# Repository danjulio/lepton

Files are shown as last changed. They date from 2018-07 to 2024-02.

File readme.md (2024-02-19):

## FLIR Lepton Code

This repository contains code, libraries and hardware I developed over the course of making a series of thermal imaging cameras based on the FLIR Lepton 3.5 camera or [module](https://store.groupgets.com/collections/flir-lepton-accessories/products/flir-lepton-breakout-board) on many different platforms.

The project process is documented at [hackaday.io](https://hackaday.io/project/159615-lepton-35-thermal-imaging-camera).

### ESP32
Contains code, design information and supporting applications for a pair of cameras based around the ESP32.

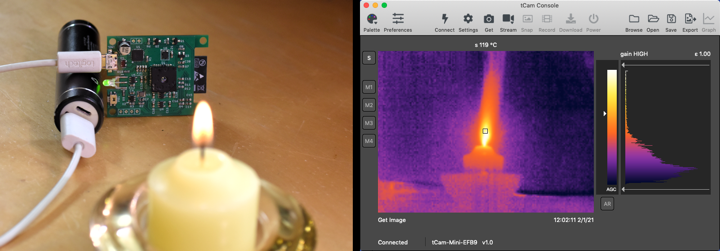
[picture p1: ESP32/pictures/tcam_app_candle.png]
tCam-Mini
 

# Note

As of Nov 6 2022, the ESP32 designs have been moved to their own repository [tCam](https://www.github.com/danjulio/tCam) to make it easier for most people who are only interested in those files.  Files here will no longer be updated.

### beaglebone
Code for the Beaglebone Black including my initial PRU-based VoSPI video pipleline and LCD display.

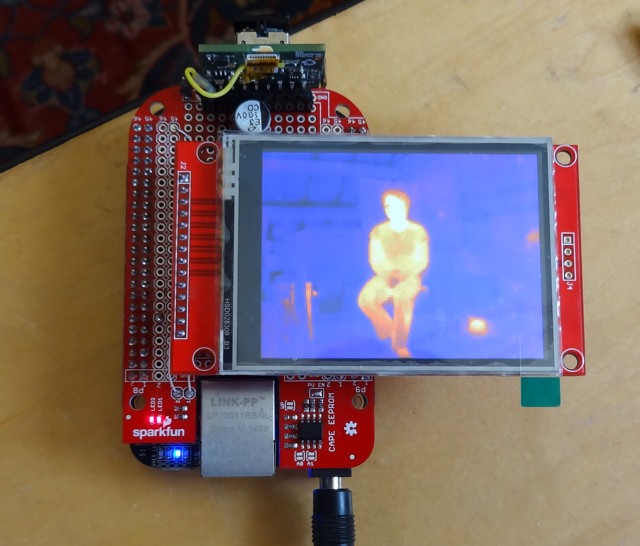
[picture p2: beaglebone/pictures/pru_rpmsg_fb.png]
Beaglebone Black Prototype


### pocketbeagle
The pocketbeagle was used for the final design of a thermal imaging camera.  This directory contains the code supporting the camera and the re-targeting of my Solar Pi Platter as a power-management and expansion board for the Pocketbeagle.

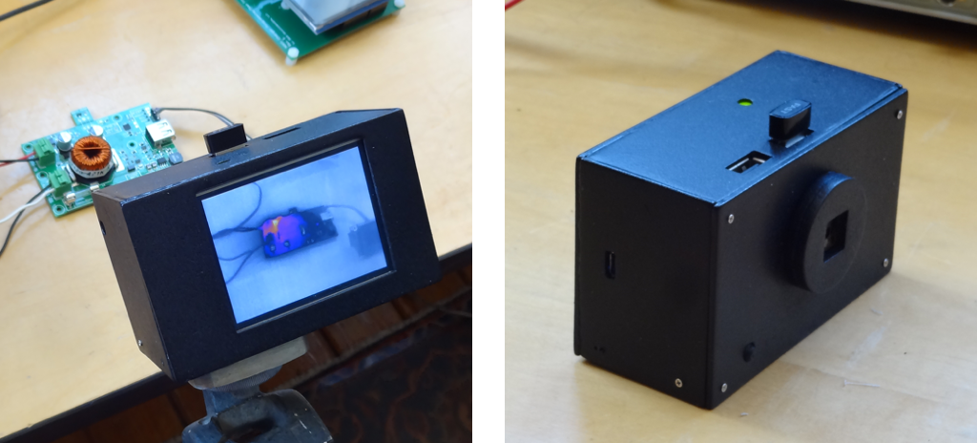
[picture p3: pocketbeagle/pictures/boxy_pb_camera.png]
Pocketbeagle Thermal Imaging Camera


### raspberrypi
Contains a modified version of Damien Walsh's great [leptonic](https://github.com/themainframe/leptonic) program running on the Raspberry Pi.  My version uses the VSYNC output from the Lepton to synchronize the VoSPI transfer as an experiment to increase the reliability of syncing a user-space process to the Lepton video stream.

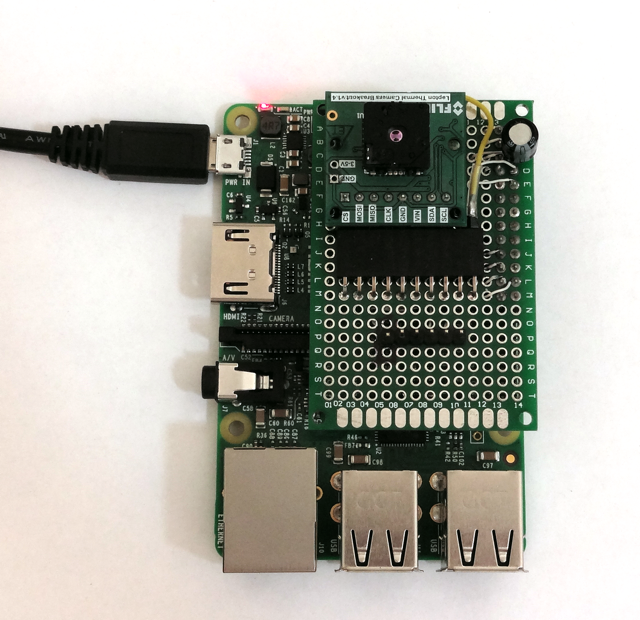
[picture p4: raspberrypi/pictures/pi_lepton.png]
Raspberry Pi Prototype


### teensy3
Contains the code I wrote initially for a test platform based on the PJRC Teensy 3.2 board to learn about the Lepton.  Also includes a port of FLIR's LeptonSDKEmb32OEM CCI to the Arduino platform.

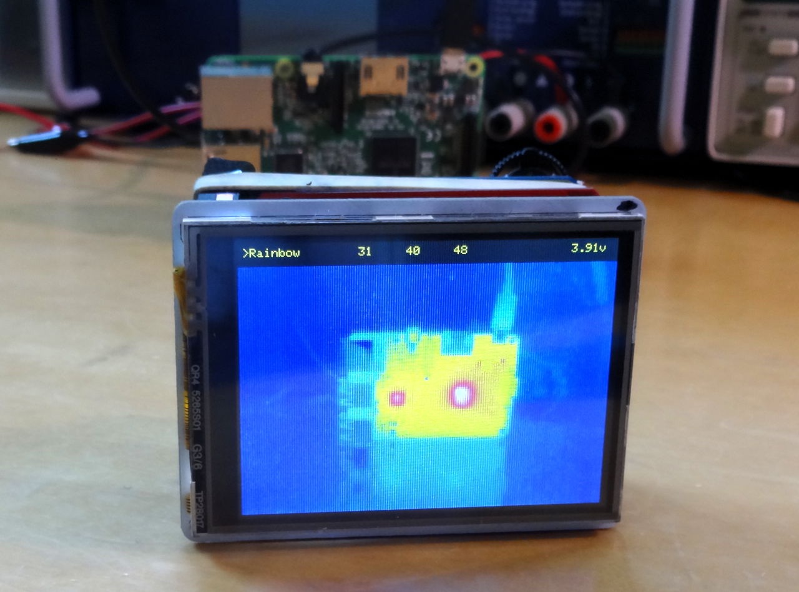
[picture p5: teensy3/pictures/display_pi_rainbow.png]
Teensy 3 Cam


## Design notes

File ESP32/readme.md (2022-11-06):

## ESP32-based Thermal Imaging Cameras
tCam and tCam-Mini are two cameras I designed around the ESP32 and Lepton 3.5.  They are designed to provide easy access to radiometric data from the Lepton.  Radiometric data is useful because it contains temperature information for each pixel in the camera's image allowing for all kinds of data analysis even if the image is stored to a file.

# Note

As of Nov 6 2022, the ESP32 designs have been moved to their own respository [tCam](https://www.github.com/danjulio/tCam) to make it easier for most people who are only interested in those files.  Files here will no longer be updated.

### tCam
tCam (still under development) is a full featured, battery powered camera with a local touchscreen display, local storage and a WiFi interface.

### tCam-Mini
tCam-Mini is a smaller network-only camera designed for streaming and remote access.  It can be built using development boards or a tested unit can be purchased from Group Gets [with built in antenna](https://store.groupgets.com/products/tcam-mini-rev4-wireless-streaming-thermal-camera-board) or [with an external antenna](https://store.groupgets.com/products/tcam-mini-rev4-external-antenna-wireless-streaming-thermal-camera-board).

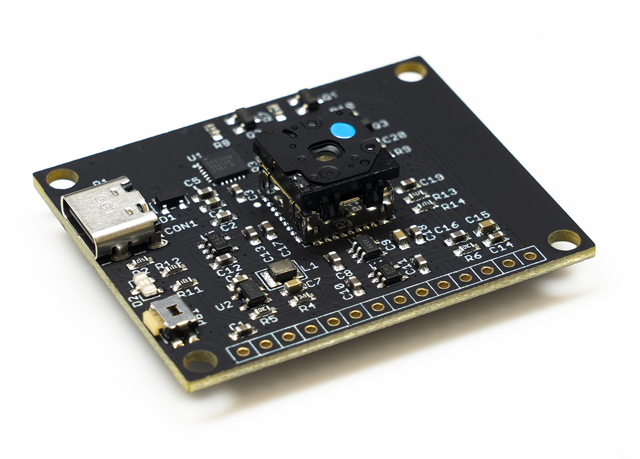
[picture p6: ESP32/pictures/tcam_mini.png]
tCam-Mini

(Photo Credit: Matthew Navarro)

### Desktop Application
Both cameras share a common command set for remote access.  A companion Desktop computer application may be used to configure and access the cameras as well as perform some analysis.

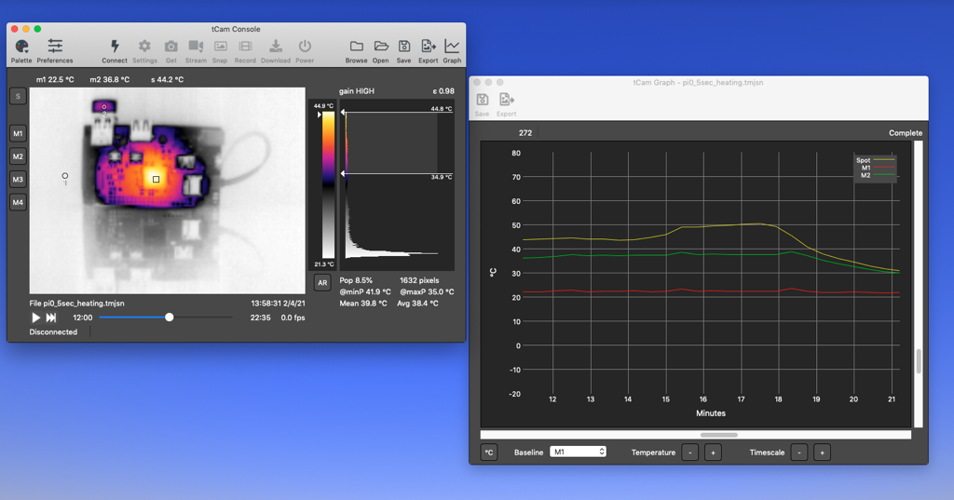
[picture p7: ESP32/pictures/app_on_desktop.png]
Desktop Application


### IOS Application
Connect, view and save images on an iPhone or iPad using the [IOS App](https://apps.apple.com/us/app/tcamview/id1610451813).  Documentation may be found on my [website](https://danjuliodesigns.com/products/tcam_app.html).

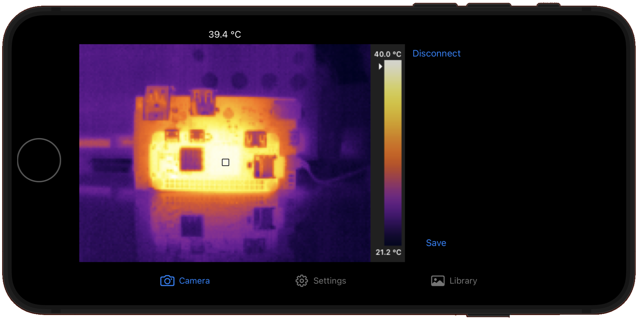
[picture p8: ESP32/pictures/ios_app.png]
IOS App


### Web Server
A simple stand-alone server that can connect to multiple cameras, record images that meet certain criteria and display images from the cameras in a web browser.

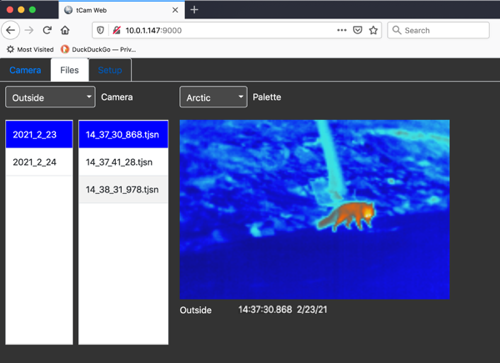
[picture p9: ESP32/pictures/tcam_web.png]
Web Application


### Python Driver
A simple driver to allow access from python programs.

### R Driver
Bob Rudus wrote a R driver for tCam-Mini that can be found in his [github repository](https://github.com/hrbrmstr/tcam).

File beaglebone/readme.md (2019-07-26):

# Beaglebone Black Code

This directory contains code and libraries developed for the Beaglebone Black board.

## pru\_rpmsg\_fb
Beaglebone Black Thermal Imaging Camera

The first code I got running on the Beaglebone Black using the two PRU co-processors to handle the Lepton's VoSPI stream and display the image on a linuxfb device driving a ubiquitous ILI9341-based 320x240 pixel LCD display.

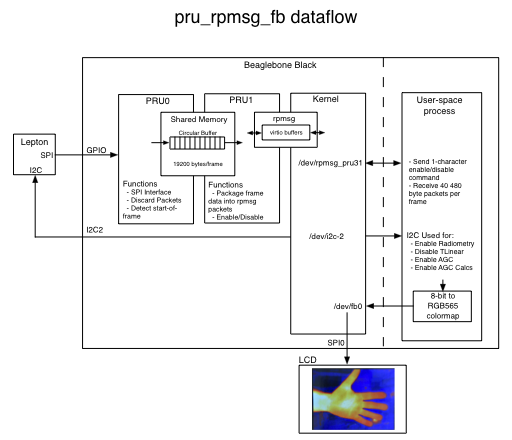
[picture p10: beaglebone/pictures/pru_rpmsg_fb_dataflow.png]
PRU Pipeline to LCD Display


## littlevgl\_devicetree
The device tree files and connection diagram to run the littlevgl GUI on the LCD display attached to a Beaglebone Black.

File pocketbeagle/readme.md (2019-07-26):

# Pocketbeagle Code and Hardware
The tiny Pocketbeagle forms the core of a complete thermal imaging camera using the Lepton 3.5 and a modified Solar Pi Platter board powered by a 3.7V 3000 mAh LiPo battery.  This directory contains the design of the camera and various pieces of software written to run on it.

Thermal Imaging Camera

## Software
### littlevgl\_demo
The necessary device tree file and a port of the littlevgl library and demo program to enable a touch-based GUI application on the build-in LCD.

### pru\_rpmsg\_fb
A port of the code originally written for the Beaglebone Black to the Pocketbeagle to display a simple image on the attached LCD screen.  The primary differences are the device tree files for the PRU/Lepton interface and SPI/LCD interface and the ```uEnv.txt``` file that uses them.  The PRU firmware implementing the VoSPI pipeline is also modified for the different pins used on the Pocketbeagle, but otherwise the same as the Beaglebone Black version.

## Camera Hardware
The hardware consists of several subsystems wired together.

### Schematic
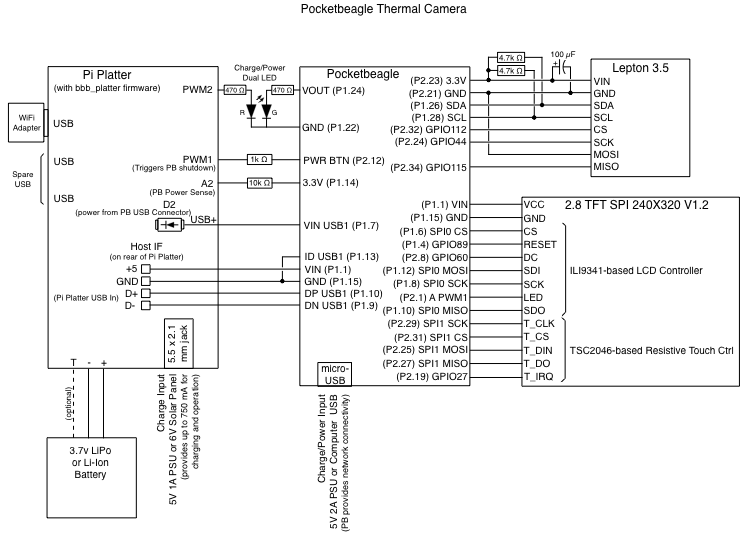
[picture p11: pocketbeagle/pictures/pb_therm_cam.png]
Pocketbeagle Thermal Imaging Camera Schematic


A dual red/green common-cathod LED provides indication of charging state and power.  The red LED lights when the battery is charging and the Green LED lights when the system is powered.

An optional USB WiFi dongle provides network access.

### Pocketbeagle board
Pocketbeagle on a proto-board with external discrete components and connections to other modules.

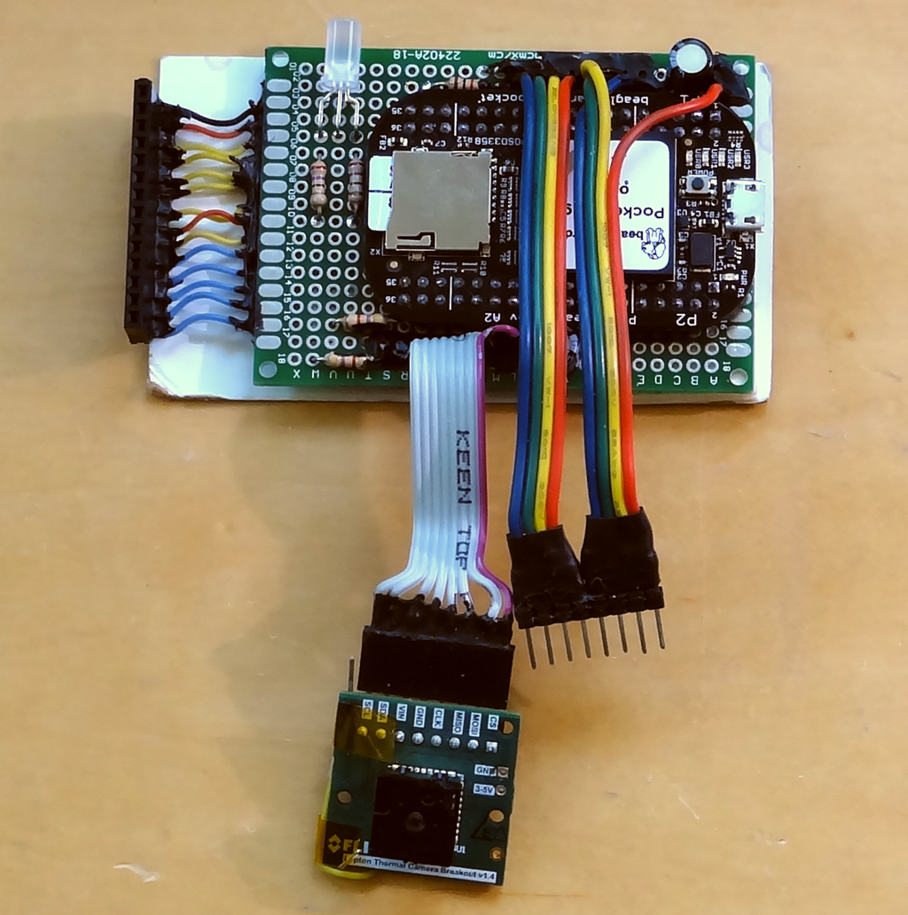
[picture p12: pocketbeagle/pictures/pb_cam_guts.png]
Pocketbeagle Board


The wire connection to the LCD connector shown above proved to be unreliable because flexing the cable during repeated camera assembly and disassembly eventually broke the solder connections.  Ultimately I replaced it with a connector on another proto-board securely mounted in the same plane as the Pocketbeagle proto-board.

### 2.8" LCD with resistive touch
I used a commonly available and inexpensive LCD module and removed the unused SD-card circuitry to prevent it from pressing against the Pocketbeagle wiring in the case.  I bought my module from Amazon but they are readily available from other sources as well.

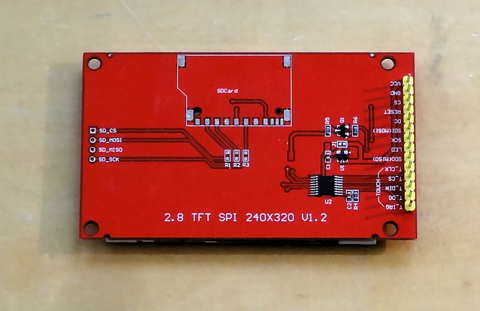
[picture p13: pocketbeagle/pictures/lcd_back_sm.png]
LCD Module Rear


### Modified Solar Pi Platter and Battery
My own Solar Pi Platter design was repurposed to provide power management and IO expansion for the camera.  It is documented in the ```bbb_platter``` directory.

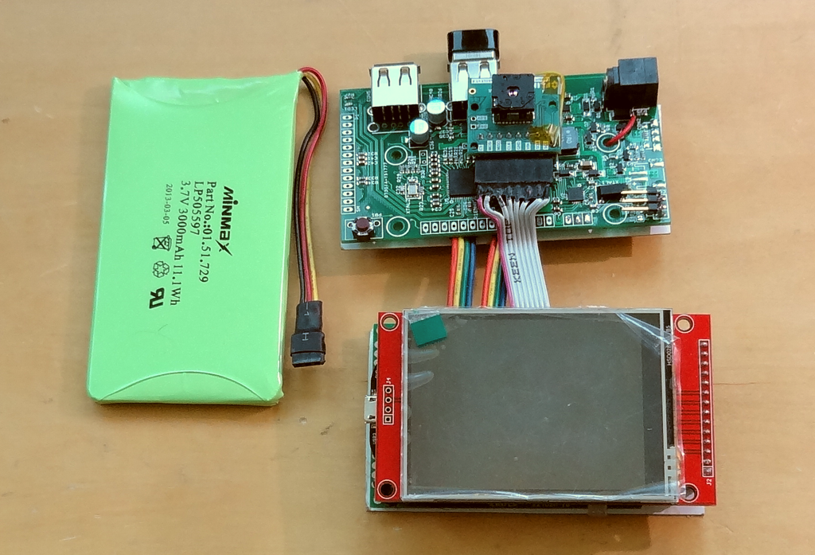
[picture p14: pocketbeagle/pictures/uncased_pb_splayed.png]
Pi Platter and Battery


The battery shown above includes a 10k thermistor connected to the Pi Platter for battery temperature monitoring.  This is optional.  Batteries from traditional suppliers like Adafruit and Sparkfun that do not include a thermistor may also be used.  I get several hours of operation from the 3000 mAh battery.

### Cardboard
I used two pieces of thin cardboard behind the two PCBs to smoothly sandwich the battery. 

### enclosure
Eight 3D printed parts are used to create an enclosure.  The parts were designed using OpenSCAD.  The source files and STL files are included in this directory.  You will need to slice the STL files into gcode for your 3D printer.

1. base.scad - Camera base including a cut-out for a tripod-mounting nut.  Includes guides to hold the various internal components of the camera and blocks that can be used to screw the front, side and rear plates to the base.
2. button.scad - A simple button that rides on top of the physical switch on the Pi Platter board and pokes out the rear of the camera to allow the user to power on/off.
3. front2.scad - The LCD bezel.
4. rear_lens.scad - A protective shield for the Lepton module that mounts to the rear plate of the camera.
5. rear_smooth.scad - The rear plate including a cut-out for the Lepton and hole for the power button.
6. side1.scad - A side plate with hole for the Pi Platter 5.5x2.1mm power jack.
7. side2.scad - A side plat with cutout for the Pocketbeagle Micro-USB port.
8. top.scad - Camera top with hole for the charge/power LED and cut-outs for two USB Type-A expansion ports.  Includes guides to hold the various internal components of the camera and blocks that can be used to screw the front, side and rear plates to the base.

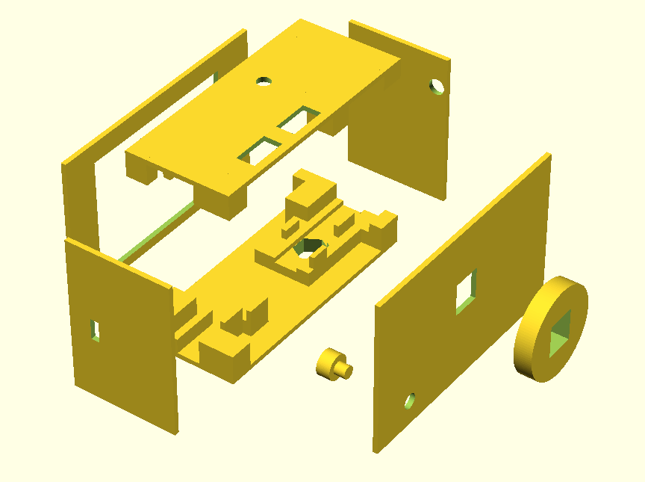
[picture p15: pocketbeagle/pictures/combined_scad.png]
Exploded view of 3D printed parts


I glued the front, sides and top together before sanding and painting the camera.  I also glued the rear_lens to the rear plate.  Then these two assemblies and the bottom are held together with screws to allow access to the camera internals.  I drilled small holes through the combined assemblies and then used small screws slightly larger than the holes to hold the parts together.  The camera was painted using a textured black spray paint over a gray primer and then clear coated.  Several layers of each paint were used.

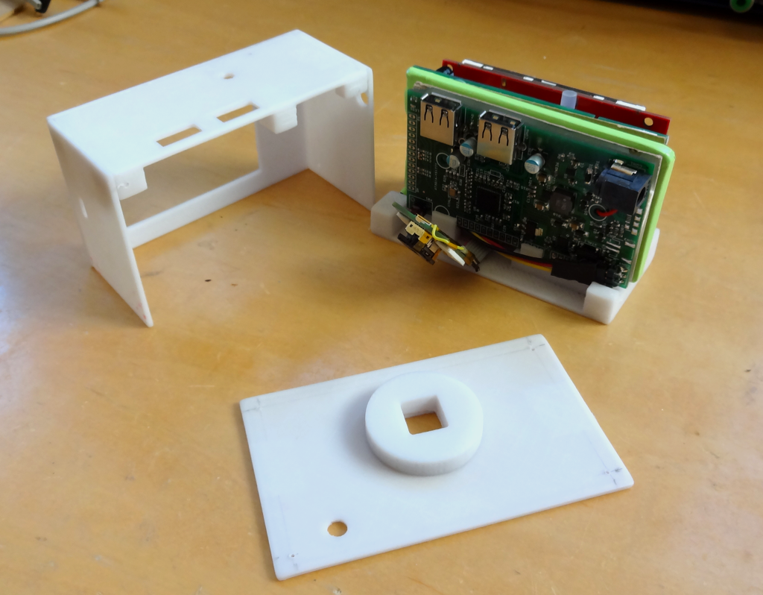
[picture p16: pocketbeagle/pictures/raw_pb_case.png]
Partially assembled camera


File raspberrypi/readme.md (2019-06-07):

# Raspberry Pi Code

## leptonic-vsync
A version of Damien Walsh's [leptonic](https://github.com/themainframe/leptonic) server program for the Raspberry Pi that uses VSYNC and an ISR running in user-space on the Pi to sync the Lepton's VoSPI data.

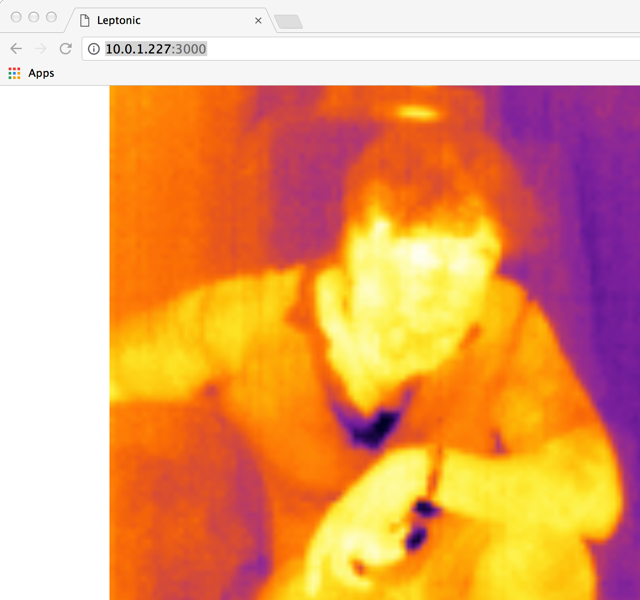
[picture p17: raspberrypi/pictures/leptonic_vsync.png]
leptonic_vsync


### Hardware

Pi Thermal Imaging Camera

Connect the Lepton module's power, I2C, SPI and VSYNC output to the Pi as follows.  

| Pi Header Pin | Function | Lepton Module |
|:---:|:---:|:---:|
| 1 | 3V3 | VIN |
| 3 | SDA | SDA |
| 5 | SCL | SCL |
| 6 | GND | GND |
| 7 | VSYNC | GPIO3 |
| 19 | MOSI | MOSI |
| 21 | MISO | MISO |
| 23 | SCLK | SCLK |
| 24 | CS0 | CS |

VSYNC can be found on the back of the Lepton module.

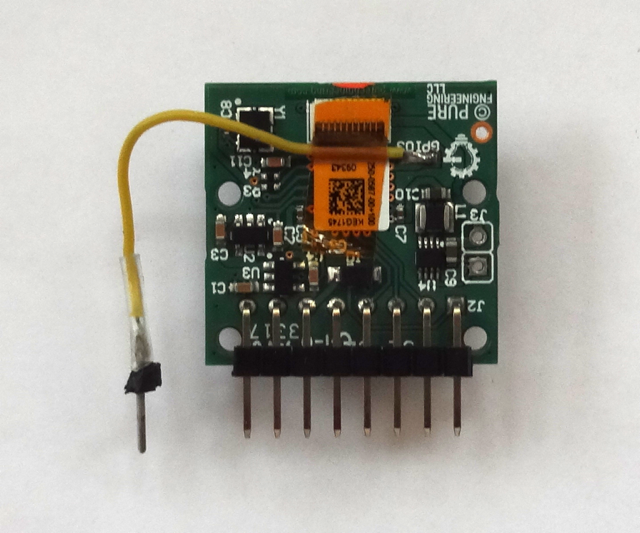
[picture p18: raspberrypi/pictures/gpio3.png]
VSYNC


### Software
Download and install Damien's version of [leptonic](https://github.com/themainframe/leptonic) including the dependencies he lists.  In addition, install the [PIGPIO C library](http://abyz.me.uk/rpi/pigpio/) and enable I2C on your Pi if necessary using ```raspi-config```.  PIGPIO is used for low-latency user-space interrupt handling.  Download and unpack leptonic-vsync.

```
cd leptonic-vsync
make
sudo ./bin/leptonic /dev/i2c-1 /dev/spidev0.0

```

You should see the leptonic server start up with output like the following.

```
pi@raspberrypi:~/leptonic-vsync $ sudo ./bin/leptonic /dev/i2c-1 /dev/spidev0.0
08:10:14 INFO  src/leptonic.c:223: preallocating space for segments...
08:10:14 INFO  src/leptonic.c:232: Creating get_frames_from_device thread
08:10:14 INFO  src/leptonic.c:238: Creating send_frames_to_socket thread
08:10:14 INFO  src/leptonic.c:80: opening I2C device... /dev/i2c-1
08:10:14 INFO  src/leptonic.c:87: opening SPI device... /dev/spidev0.0
08:10:14 INFO  src/leptonic.c:106: aquiring VoSPI synchronisation
```

Then start the frontend code in the original leptonic frontend directory.

```
npm start
```

You should be able to view the output from the camera on a web browser using the Pi's address at port 3000 as with Damien's original code.

#### AGC
Uncomment out the call to ````cci_set_agc_enable_state```` in leptonic.c to enable AGC.  This results in a slightly better image utilizing the Lepton's built-in AGC functionality.

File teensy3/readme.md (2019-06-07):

## Teensy 3 Test Platform

Teensy Thermal Imaging Camera

This directory contains code for a test platform based on the PJRC Teensy 3.2 development board.  It consists of a set of Arduino-environment sketches and a port of the FLIR IDD library used to control the module via its I2C bus.

The project is documented at [hackaday.io](https://hackaday.io/project/159615-lepton-35-thermal-imaging-camera).  It uses an ILI9341-based 320x240 pixel LCD display.

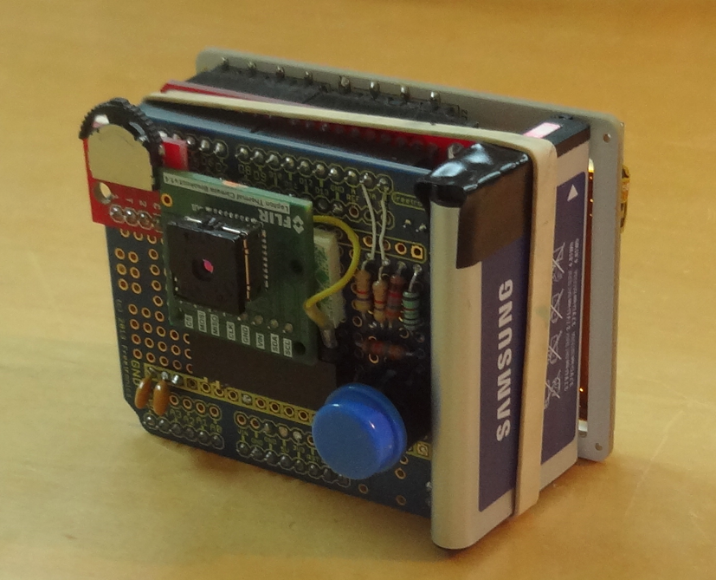
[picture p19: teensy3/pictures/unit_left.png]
Teensy Thermal Imaging Camera


### Contents

1. LeptonSDKEmb32OEM - FLIR's IDD library ported for operation on the Teensy.  Primarily this required adapting the different sizes of enums on the Teensy platform vs. 32-bit Linux platforms such as the Raspberry Pi.  This library has a dependence on the Teensy i2c_t3 library in case you want to try it on another embedded platform.  It should be put in your Arduino libraries folder.
2. lep_test5 - A test sketch demonstrating the Lepton's built-in AGC function.  Eight-bit output from the Lepton is displayed through a color map.
3. lep_test6 - A test sketch demonstrating the (default) 16-bit Tlinear radiometric data from the Lepton.  Sixteen-bit output from the Lepton is scaled linearly into an 8-bit range and displayed through a color map.  The temperature of the image center is displayed.
4. lep_test7 - A test sketch demonstrating the Lepton's internal color map LUTs.  AGC is enabled as well as 24-bit RGB output.  This data is then reduced to 16-bits for the LCD display without using any color maps on the Teensy.
5. lep_test8 - A test sketch designed to allow comparison of the Lepton's built-in AGC modes (HEQ and linear) with a simple linear transformation done in code with the 16-bit temperature data.
6. lep_test9 - A test sketch designed to allow investigating the emissivity setting (RAD Flux Linear Parameter) and comparing the spot meter output (via I2C) with the raw pixel data temperature.
7. lep_test10 - A combination of test5 and test9 enabling AGC (with HEQ mode), spot meter readout of center temperature and ability to set emmissivity.  Code has been ported to Adafruit's LCD shield (CS# on D10, DC on D9) and uses latest Adafruit GFX and ILI9341 Arduino libraries.
8. teensy_schematic.pdf - Shows the connections for the test platform including the soft power control and battery charging/boost converter circuitry.

This code is "as-is" and may contain bugs (especially the library as it has a lot of functions I haven't tested).  Please let me know if you have a question or find a bug.

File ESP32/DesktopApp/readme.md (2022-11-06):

# Note

As of Nov 6 2022, the ESP32 designs have been moved to their own respository [tCam](https://www.github.com/danjulio/tCam) to make it easier for most people who are only interested in those files.  Files here will no longer be updated.

## tCam Desktop Application

This repository contains the companion desktop application for the tCam cameras.  It communicates with the cameras via a network connection using their json packet command set.  It provides functionality to control the cameras, download and display data from them and analyze the radiometric data.

* Get a current image.
* Stream images from a connected camera at various rates.
* Control remote picture and video recording and download images from the camera's local storage (tCam only).
* Save and load radiometric image files.
* Save and load radiometric video (stream) files.
* Export radiometric data as a common format image file.
* Graph temperature at up to five points from a stream or video file.
* Update camera firmware (tCam-Mini requires FW 2.0 and beyond).
* Discover cameras on the local network (requires tCam-Mini FW 3.0 and beyond)

The application is developed using the [xojo](https://www.xojo.com) development environment.  64-bit binary images are provided for Mac OS X, Windows and x86 Linux systems.  A 32-bit binary image is provided for Raspbian or other ARM7HF Linux SBCs.  Download the zip file for your platform.  The application can be run directly from the unzipped directory by double clicking the application binary icon.

Note: Zip files for each application platform can be downloaded directly from my [website](http://danjuliodesigns.com/products/tcam_mini.html) as well if you don't want to clone this entire repository.

#### Version History
The latest version release notes are shown here.  Please see the ```release_notes.pdf``` file for notes from previous versions.

Version 3.1.0

1.	Support 63 character WiFi passwords with all tCam firmware and tCam-Mini firmware 3.1 and beyond
2. Disabled Graph when connected to a camera with a Lepton 3.0
3. Display “RAW” and “AGC” in color palette bar when connected to a camera with a Lepton 3.0
4. Worked around Xojo bug where pull-down menus didn't work properly in Linux builds (starting with
version 3.0.0)

#### Platform Caveats

1. The Mac version should now be signed and is delivered as a Universal installer package.  Let me know if you have any trouble.
2. You may need to make the Linux application file executable.
3. You may also have to authorize the application on the Windows platform since I don't yet package it for distribution in their online stores.
4. Windows users may need to install support for Bonjour (mDNS) using the ```bonjoursdksetup.exe``` installer from Apple found here.
5. Different Linux desktop systems render the toolbar differently and all toolbar items aren't visible since Linux renders the text next to the icon instead of beneath it.  You can make the window wider to expose some important controls like Stream that has sub-menus or you can use the pull-down menus at the top of the window.
6. Linux users may need to install ```libwebkit2gtk``` to view the built-in documentation.
7. The Raspberry Pi versions basically require a Pi 4 to display a stream at the full rate.  On slower Pi models the application may not be able to keep up and the controls may become unresponsive when streaming at the full ~9 FPS rate.

An advance apology - I develop on my Mac and do quick tests on Windows 7 and 10, and Ubuntu, Kubuntu and Raspbian.  Although xojo provides pretty good cross-platform compatibility for OS X and Windows, sometimes there are issues with Linux.  If you find some other issue, please let me know and I'll try to fix it.

### Main Window
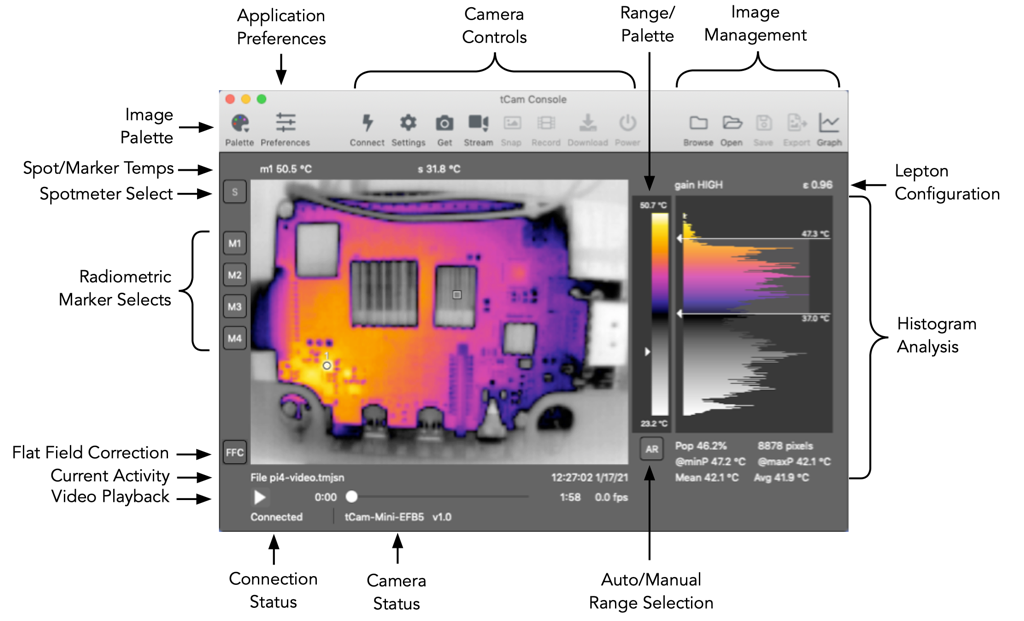
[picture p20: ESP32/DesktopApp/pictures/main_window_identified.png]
Main Window


Main window operation is described below.

### Preferences
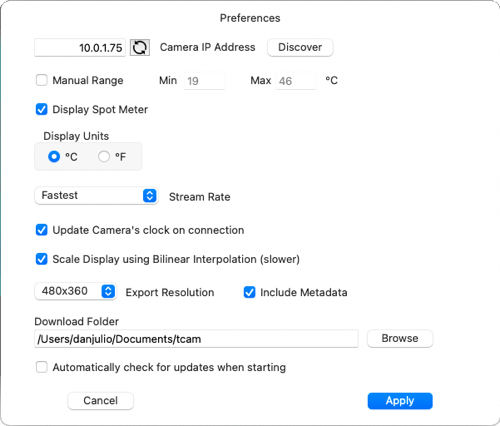
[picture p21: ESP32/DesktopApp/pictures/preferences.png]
Preferences Window


The preferences window is used to configure the application.  Preferences are stored on the computer and loaded each time the application starts.

* Camera IP Address - Set the camera's IP address.  Clicking the refresh button sets the computer's current network IP4 address with the lowest octet set to "1".  If the camera is acting as an AP then this address will be the camera address "192.168.4.1".  If the camera and computer are both connected to an external AP then replace the lowest octet with the address associated with the camera.
* Discover - Displays the Camera Discovery window which is used to display the IP addresses of cameras on the same network (tCam-Mini cameras must be running FW 3.0 and beyond).
* Manual Range - Allows setting a specific manual temperature range for the display of radiometric images.
* Display Units - Allows setting the unit display used throughout the main window.
* Stream Rate - Allows setting the requested stream rate from the camera when streaming is enabled (fastest possible rate down to one image every five minutes)
* Update Camera Clock - Causes the application to set the camera's built-in clock to the current computer time on each connection.  The clock is used to timestamp images.
* Scale Display using Bilinear interpolation - Uses an algorithm that results in a slightly smoother image as it is increased from the camera's native 160x120 pixel resolution.  De-selecting this uses a much faster algorithm that will work better on slower computers and when resizing the image at the cost of some smoothness.
* Export Resolution - Sets the size of an exported image (160x120 pixels to 640x480 pixels) and specifies if only the image or the image plus additional information is rendered to the exported file.
* Download Folder - Sets the default folder for downloaded/saved images.
* Automatically check for updates - Selecting this enables the program to check for an updated version every time it is launched.  It is always possible to check for an update using the ```Applications->Check for updates...``` menu item if this is de-elected.  No information is transmitted during the check.

### Connecting to an Ethernet Camera
The tCam-POE camera using its Ethernet interface has either a DHCP-served or statically assigned IPV4 address.  This address is entered into the application preference's Camera IP Address field.  A statically assigned address may be set using the Settings button as described below (Camera Settings Window).

### Connecting to a WiFi Camera
The tCam cameras operate in one of two WiFi modes.  By default they act as an Access Point (AP) and create their own WiFi network with the SSID "tCam-XXXX" or "tCam-Mini-XXXX" where XXXX are four hexadecimal digits.  This makes it easy to connect to a camera right away.  Once connected the camera may be reconfigured using the application to connect to an existing WiFi network, either getting a DHCP served IPV4 address from the network's router or with a statically assigned IPV4 address.  This makes it possible for the computer running the application to talk to both the camera and the internet at large.

#### Connecting to a camera as Access Point
Configure the computer to connect to the camera's SSID.  The camera always has a IPV4 address of "192.168.4.1" when it is acting as an Access Point so this number should be entered into the application preference's Camera IP Address field (this is the application's default value).  Press the Connect button after configuring or verifying the preference IP address field.

#### Configuring the camera to connect to another WiFi network
Once connected the application can be used to reconfigure the camera to connect to an existing WiFi network using the Settings button as described below (Camera Settings Window).  The camera may be configured to either get a DHCP served IPV4 address from the router or given a static IPV4 address on the network.

#### Connecting to a camera connected to another WiFi network
Connecting to a camera on an existing WiFi network requires the camera's IPV4 address to be entered into the application preference's Camera IP Address field before pressing Connect.  For cameras running firmware prior to version 3.0, it may be necessary to log into the WiFi router or use a utility program (for example Fing on Android or nmap on Linux) to obtain the camera's IPV4 address if it has been assigned automatically using DHCP.

#### Discovering Cameras
tCam-Mini cameras running version 3.0 firmware or later, and all tCam and tCam-POE cameras implement mDNS (bonjour) for discovery.  The Discover Cameras window displays all cameras on the local network.  Selecting a camera and clicking Apply sets the Camera IP Address with the IP Address of the selected camera.

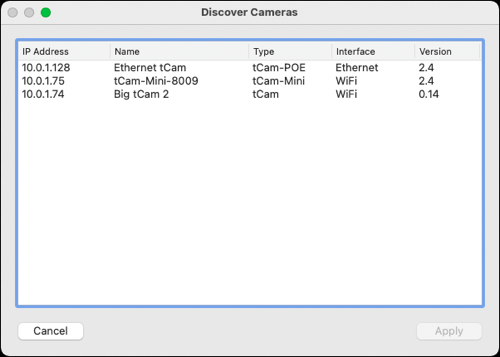
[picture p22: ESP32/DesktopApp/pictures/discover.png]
Discovery Window


### Application Operation
The application is oriented around radiometric image files.  It always displays the last image it processed.  This may be a static image loaded from a file or taken by an attached camera.  It may also be a series of images from a video file or streamed from the camera.  Each image is displayed using a selected Palette to provide a false color image.  The 16-bit radiometric data is linearly scaled to 8-bits and the selected palette used to generate 24-bit RGB pixel colors.  When the camera is configured into AGC mode the 8-bit data from the camera is used directly with the selected palette.

Note that while the application is designed primarily for use with radiometric image files, it is also capable of displaying images taken when the camera's Lepton sensor has been configured into AGC mode.  In this case, since the data from the camera no longer contains radiometric information, several functions (such as radiometric markers or histogram analysis) are not available.

#### Camera Controls
Camera controls are available when the application is connected to a camera.  The main camera controls are displayed at the top of the main window.  These controls and additional controls are displayed under the ```Camera``` pull-down menu.

* Connect - Toggles the connection state with the camera.  The connection state is shown in the Connection Status area.  When first connected, and then periodically, the application requests the camera status and displays it in the Camera Status area.
* Settings - Requests the current Lepton configuration and WiFi setup from the camera and displays the settings window. 
* Get - Get a single image from the camera.
* Stream - Start (or Stop) the camera streaming images at the rate set in the Preferences Window.  The stream may optionally be stored to a video file.  Clicking the Stream button brings up a submenu.
	* Stream - Only display the stream.
	* Record - Select a video file to record the stream into and display the stream.
	* Stop - End a stream (close the video file if recording).
* Snap - Take a picture and store it in the camera's local storage (tCam only).  Equivalent to pressing the shutter button with the camera set to Image mode.
* Record - Start or stop the camera recording a stream in its local storage (tCam only).  Equivalent to pressing the shutter button with the camera set to Video mode.
* Download - Download a selected set of image or video files from the camera's local storage (tCam only).
* Power - Switch the camera off (tCam only).
* Check for new Firmware - Checks to see if a newer version of the firmware for the connected camera is available to download from ```danjuliodesigns.com```.
* Update Firmware - Initiate a FW update process with cameras that can support it.
* Camera Info - Display a pop-up (shown below) with information about the currently connected camera.

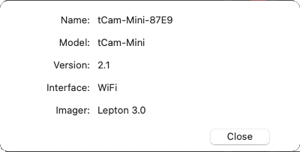
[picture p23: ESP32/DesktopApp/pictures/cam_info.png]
Camera Information Window


#### Camera Settings Window
The Camera Settings Window allows configuring the camera operation.  Items with the associated "Update Camera" checkbox set will be updated in the camera if Apply is pressed.

##### Configuration Tab

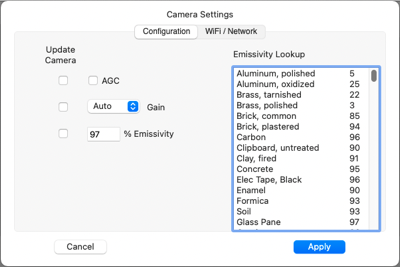
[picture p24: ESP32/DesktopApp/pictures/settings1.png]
Camera Configuration Window


Configuration items affect the Lepton's operation.

* AGC Button - Selects between Radiometric operation or the Lepton's AGC mode which uses a built-in algorithm to improve visual image quality at the expense of outputting radiometric data.  When AGC is selected the output data is 8-bits/pixel designed to be displayed through the color palette with improved visual characteristics and is useful to see differences in temperature in an image.
* Gain Pulldown - Selects the Lepton's Gain mode.  High gain is useful for images with similar temperatures.  Low gain is useful for images with widely varying and high temperatures (for example when looking at fire).  Automatic gain mode allows the Lepton to switch from High to Low gain as necessary based on the image.
* Emissivity - Sets the Lepton's applied emissivity and is a value of 1-100%.  Should be set based on the characteristics of the materials being imaged.  Some useful materials are listed in the scroll-box.  Selecting one of them automatically updates the emissivity value.

##### WiFi / Network Tab

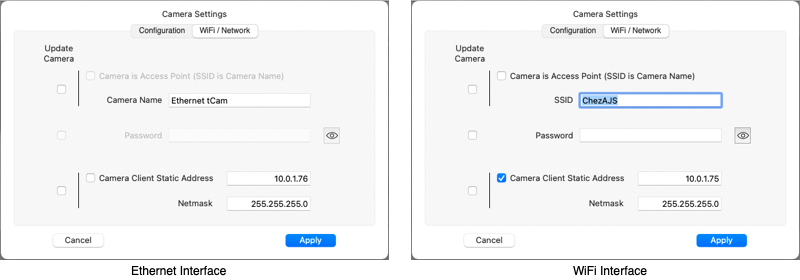
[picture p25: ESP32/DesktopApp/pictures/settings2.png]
Camera Network Window


The WiFi / Network tab configures the camera network interface.

##### Ethernet Interface

For cameras using an Ethernet interface (tCam-POE configured to use Ethernet) the tab displays Network items.  Network items include the camera name and if a static IP should be set.

* Camera Name - Configure the name of the camera as displayed in the Discover Cameras Window.
* Camera Client Static Address - Selecting this checkbox and filling in the associated IPV4 address field allows configuring the camera with a static IPV4 address.  The address must be on the same network and should not be in a range the network's router might assign automatically using DHCP.  De-selecting the checkbox will enable the camera to request a DHCP served IPV4 address from the router.
* Netmask - The netmask to use when using a static IPV4 address.  Usually this will be "255.255.255.0".

##### WiFi Interface

For cameras using WiFi (tCam, tCam-Mini and tCam-POE configured to use WiFi) the tab displays WiFi items.  WiFi items include whether the camera is acting as an Access Point (AP) or connecting to an AP (Client mode), the associated SSID and password and if a static IP should be set (in Client mode only - the camera always has the IP address of 192.168.4.1 in AP mode).

* Camera is Access Point checkbox - Configure the camera's Wifi Mode as either Access Point (it creates a Wifi Network) or Client (it connects to another Wifi Network).
* SSID - The Wifi Network SSID.  This is the name of the WiFi Network the camera will create if it is in AP mode or the name of the WiFi Network it will attempt to connect too in Client mode.  The maximum length is 32 characters.
* Password - The Wifi Network WPA password.  This is the password that is necessary to connect to the camera's WiFi Network if it is in AP mode or the password it will use to connect the another WiFi Network in Client mode.  Leave the field blank if there is no password, otherwise the password must be between 8 - 32 characters long.
* Camera Client Static Address - Selecting this checkbox and filling in the associated IPV4 address field allows configuring the camera with a static IPV4 address.  This only applies to the camera when it is operating in Client mode.  The address must be on the client network and should not be in a range the network's router might assign automatically using DHCP.  De-selecting the checkbox will enable the camera to request a DHCP served IPV4 address from the router.
* Netmask - The netmask to use when using a static IPV4 address.  Usually this will be "255.255.255.0".

The application will be disconnected after changes to the Wifi / Network configuration are made.  The application Camera IP Address field preference may need to be updated to reconnect.

#### Download Window
Selecting ```Download``` queries the connected camera for all files stored in its local storage.  The files and their parent directories are displayed in the download window.

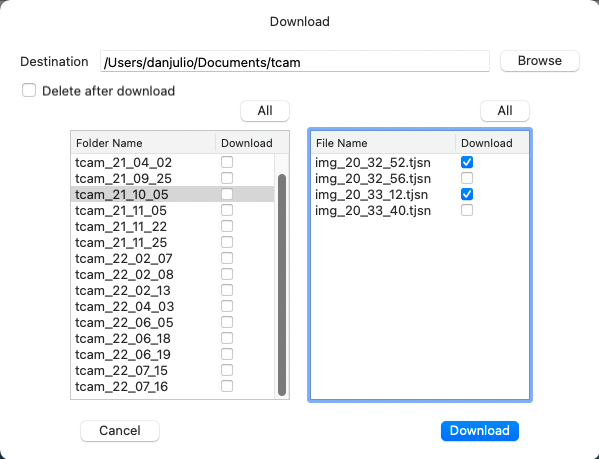
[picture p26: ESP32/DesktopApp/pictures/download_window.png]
Download Window


The window allows selecting either entire folders for download or individual files within a folder for download to the destination parent folder.  Click the associated Download checkbox next to either the folder name or file name and click ```Download``` to start downloading files.  Selecting the ```Delete after download``` checkbox will delete the file or folder on the camera after it is downloaded.

#### Range/Palette Display
The Range/Palette display shows the currently selected palette with a marker showing the spotmeter temperature location within the range of temperatures.  It also displays the minimum and maximum temperatures used to scale the image when the Lepton is operating in Radiometric output mode.  These temperatures are simply the minimum and maximum temperature in the image's radiometric data when Auto Range Selection is enabled.  They are the manual temperature range (set by the user in the Preferences window or automatically when the AR button is pressed) when Manual Range Selection is enabled.

#### Image Management
Image Management controls are available based on the type of operation occurring or image being displayed.

* Browse - Allows opening a directory (Folder) of image and video files and displays forward and backward buttons in the Current Activity area.
* Open - Allows opening a single image or video file.
* Save - Allows saving the current image in a file.
* Export - Allows saving the current image as a jpeg, png or tiff image, with or without additional metadata rendered to the image.
* Graph - Allows graphing either a stream or video file.  At least one of the spotmeter or four radiometric markers must be enabled to graph.

An example of a 320x240 pixel exported image (with metadata) is shown below.

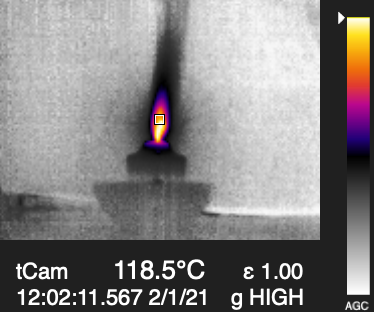
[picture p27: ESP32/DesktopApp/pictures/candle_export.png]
Exported Image


#### Image Palette
A pull-down menu allowing selection between a set of false color maps.  Different palettes are useful in visualizing various attributes of an image.  For example the ```Rainbow HC``` palette, with its rapidly changing colors is good for showing temperature gradients while the ```Ironblack``` palette is good for emphasizing only the hotter areas in a scene.

#### Spot/Marker Temps
Displays the current enabled SpotMeter ("s") or Radiometric Marker temperatures ("m1" - "m4").

The SpotMeter temperature is taken from the telemetry data in the last image.  It is based on a 4-pixel average.

The Radiometric Marker temperatures are computed based on the Radiometric data in the last image.  They are also computed using a 4-pixel average.

#### Spotmeter Select
Clicking the Spotmeter Select button enables setting the spot meter position in the Lepton by clicking on a location in the image.  Note that changing the spotmeter position causes a command to be sent to the camera setting the location.  However the spotmeter display in the image and the temperature displayed above are not changed until a new image is loaded from the camera.

#### Radiometric Marker Selects
The Radiometric Markers are only enabled if the displayed image contains radiometric data (they are disabled if the image was generated by the Lepton while AGC is enabled).

Clicking on a Radiometric Marker Select button enables setting the associated marker position in the displayed image.  The marker is displayed immediately since it is calculating the temperature at the location based on the existing image radiometric data.

Double clicking a Radiometric Marker Select button disables the marker if it is currently displayed.

#### Flat Field Correction
Clicking on the FFC button causes the connected camera to initiate a Lepton flat field correction.

#### Current Activity
The Current Activity area displays the source of the last loaded image and its timestamp.  It also displays a pair of forward and backward buttons when browsing a folder.

Browse Controls

#### Video Playback
The Video Playback area displays controls and timestamp information when a video file has been opened.  It also displays the frames-per-second of a playing video or stream.

A play/pause button, denoted by a single right-facing triangle, controls video playback.  A position slider allows setting the video position.

Video files with a frame-rate of below 1 frame-per-second cause a second fast forward button, denoted by a double right-facing triangle, to appear.  Pressing this button plays the video at a fixed rate of one frame-per-second instead of the video's normal rate (which could be as slow as one frame every five minutes!).

Video Fast Forward

#### Connection Status
Connection Status shows the current connection state, either Connected or Disconnected.  While connected the application periodically sends a request for status.  If the camera does not respond with a status response the application will assume the camera has been disconnected.

#### Camera Status
Information from the camera status responses are displayed in the Camera Status area including the camera name, and optionally battery level and charge status for tCam.

#### Auto/Manual Range Selection
The Auto/Manual Range Selection button toggles between Automatic and Manual Range modes when the Lepton is configured in Radiometric mode (the button is disabled if AGC is enabled).

In Automatic Range mode the minimum and maximum temperatures present in each image are used to linearly scale the radiometric data.

Manual Range mode uses a preset minimum and maximum temperature to scale the radiometric data.  This mode is useful to eliminate radical image changes while streaming or playing back a video and the scene dynamic range changes from image to image resulting in very different false color mappings.  Typically a manual range is set to be slightly greater than the largest expected scene range.

The Range mode can also be controlled via Preferences.

When the Auto/Manual Range Selection button is used to enter Manual mode, the minimum and maximum temperatures are set by rounding the existing scene minimum temperature down to next whole number value and the existing scene maximum temperature up to the next whole number value.

#### Lepton Configuration
Displays the Lepton's gain and emissivity settings for the current image.

The gain setting is either HIGH or LOW.  When the camera's Lepton is allowed to automatically select the gain setting (via the Camera Settings) then it will use a High gain setting for scenes with a low dynamic range (-10°C to 140°C) for improved accuracy and resolution.  It will switch to Low gain setting for scenes with a higher dynamic range.

The emissivity setting is a percent, from 1-100, that the Lepton uses to improve accuracy when computing the radiometric temperature of each pixel.  It should be set to match the emissivity of objects in the scene.

#### Histogram Analysis
The Histogram Analysis area displays a histogram showing the relative number of pixels for each of the 256 values (bins) that result from the linear transformation of the radiometric data or are direct from the camera when AGC is enabled.

A pair of markers can be dragged onto the histogram.  The markers display the temperature of the bin they are over when the image contains radiometric data.

Additional information is displayed about the region between the two markers when both are dragged onto the display.

* Population - Percent (and number) of pixels out of the Lepton's 19200 total pixels between the markers.
* @minP (radiometric data only) - The temperature of the bin with the least number of pixels in the region between the two markers.
* @maxP (radiometric data only) - The temperature of the bin with the highest number of pixels in the region between the two markers.
* Mean (radiometric data only) - The mean temperature in the region between the two markers.
* Average (radiometric data only) - The average temperature in the region between the two markers.

### Graphing
Temperature data from a streaming session or video file may be graphed over time for further analysis.  If enabled the spotmeter temperature is included in the graph.  Any enabled Radiometric Markers (radiometric data only) are also included allowing a total of up to five locations in the image to be plotted.

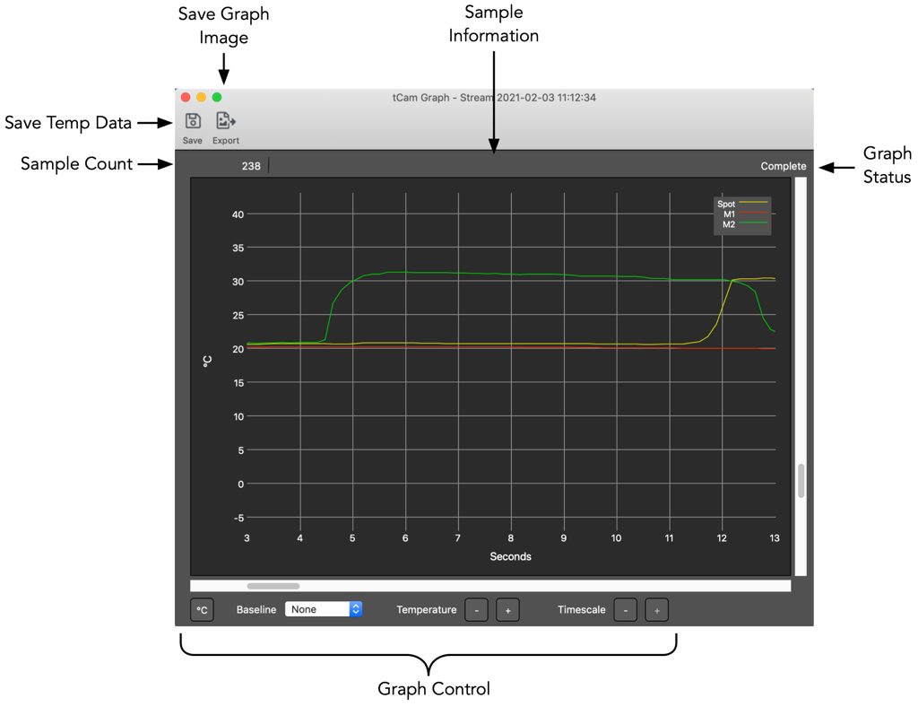
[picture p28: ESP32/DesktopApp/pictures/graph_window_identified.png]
Graph Window Identified


To graph from a stream

1. Start streaming at the desire rate.
2. Select Spot and Radiometric Marker positions.
3. Click Graph to start plotting data.
4. Stop streaming to complete the graph.

To graph from a video file

1. Open the video file.
2. Select any additional Radiometric Marker positions (the spotmeter location is set in the file's image data).
3. Click Graph to plot the data.

Multiple graph windows may be opened.  The data may be saved in a text file or an image of the graph exported once the graph is complete.

#### Save
Saves the temperature data in a text file comprised of one or more temperature values following a timestamp, separated by spaces with one set per line.

	<timestamp> <spot> <m1> <m2> <m3> <m4> <CR><LF>

* \<timestamp\> is the number of milliseconds from the start of Unix Epoch time (Thursday, January 1, 1970 12:00:00 AM GMT).
* \<spot\> is the spotmeter temperature (°C) if available or the character "-" if not available.
* \<m1\> - \<m4\> are the Radiometric Marker temperatures (°C) if available or the character "-" if not available.
* \<CR\>\<LR\> are the Carriage Return and Linefeed characters.

#### Export
Saves the contents of the graph window as a jpg, png or tiff formatted file.

Selecting "Copy" from the Graph Window Edit pull-down menu copies the contents of the graph window to the computer's clipboard.

#### Complete
The graph is marked Complete when all data has been plotted.  This occurs when streaming is stopped or after all video file data is processed.  No further data will be added to the graph.

#### Graph Controls
Graph Controls control how the data is displayed.

* Units Button - Toggles unit display between °C and °F.
* Baseline - Allows selecting one of the traces to be used as a Baseline temperature when displaying sample data (see below).
* Temperature - Controls the zoom factor of the temperature axis.  The graph displays a total temperature range of 500°C (900°F).  The temperature zoom factor allows display of temperature data from 0.5°C (1°F) to 30°C (50°F) per horizontal rule line.
* Timescale - Controls the zoom factor of the time axis.  The time zoom factor allows display of time data from 1 second to 30 minutes per vertical rule line.

The position of the data graphed is controlled by the horizontal and vertical sliders.  It may also be controlled, when the cursor is over the graph, by horizontal and vertical mouse controls.

#### Viewing Sample Data
Positioning the cursor over the graph displays the sample points on each trace.  Positioning the cursor over a sample point displays the sample data in the Sample Information area.  Sample data includes the sample source, its time relative to the start of the graph, the sample's original timestamp and its temperature.

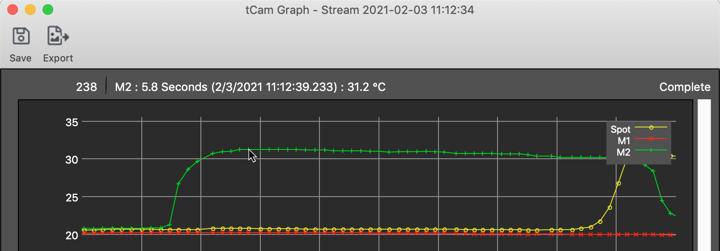
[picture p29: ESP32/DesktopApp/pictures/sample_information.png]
Sample Information


#### Using a Baseline
Selecting a baseline allows comparing temperatures on traces with the temperature on the baseline trace.  This is often useful for comparing a temperature of something with the temperature of an object with a precisely known temperature for improved accuracy.

In the image below the temperature of a point on the M2 trace is compared with the temperature of the point on the Spotmeter trace.

Sample Information with Baseline

### Application Menu Items
All functions available through controls on the Main Window are also available from the pull-down menus at the top of the window (or OS X main menu bar).

The ```Application``` menu item contains two items not accessible elsewhere that provide additional functionality.

1. CCI Access - Provides direct access to the Lepton Command and Control interface.
2. Log Window - Displays a log of program status and transmitted and received packets.
3. Check for updates - Checks to see if a newer version of the application is available to download from ```danjuliodesigns.com```.

#### CCI Access
The CCI Access window allows direct access to the Lepton's I2C interface as described in the Flir Lepton Software Interface Description Document.  It allows access to the Lepton CCI registers and Block Data Buffer 0 for data lengths greater than 16 DWORDs.

CCI Access

You should be familiar with the Lepton CCI Interface.  It is possible to misconfigure and/or crash the Lepton or tCam camera using this interface.

Operation is straight-forward.  The Command, Length and Data fields correspond directly with the associated Lepton registers.  The first sixteen Data values are associated with Data 0 - 15 for Length's of 16 DWORDs or less.  The up to 512 Data values are associated with Block Data Buffer 0 for Length's of 16 DWORDs or more.

To read the Lepton configure the Command and Length and click ```READ```.  The Data fields are updated.  The Last Status field is updated with the STATUS register value after the read.

To write the Lepton configure the Command, Length and Data values and click ```WRITE```.  The Last Status field is updated with the STATUS register value after the write.

To run a command sequence configure the Command value and click ```RUN```.  The Last Status field is updated with the STATUS register value after the run command.

The ```LOAD``` and ```SAVE``` buttons save or load values to or from a simple text file with one value per line.  The file layout is as follows.

```
	Command
	Length
	Data 0
	...
	Data <Length - 1>
```

#### Log Window
The Log Window displays connection/disconnection status messages and logs the transmitted and received json packets to the camera.  It can be useful to understand the packet contents.

Log Window

It provides a simple set of controls.

* Enable - Enable or disable logging.
* Shorten Json - Shortens long json strings (helpful when displaying image and FW update packets.
* Filter Status - Filters out the ```get_status``` and ```status``` response packets which are sent periodically while the application is connected to the camera to verify connectivity.
* Auto Scroll - Configures the window to automatically scroll when text reaches the bottom.
* Clear - Clears all text.

#### Check for Updates

Updates for either the application or firmware are displayed in the Update Available window.  It displays a description of the changes in the new version. Clicking ```Download``` will download a zip file with the new application (for the current platform) or firmware (for the connected camera).

Update Available Window

### Help Menu Items
The ```Help``` menu items contains the following selections.

1. About tcam - Displays version and copyright information.  Click in the window to dismiss.
2. Documentation - Displays documentation like this readme file in a window.

### File Formats
The application supports two file formats.

* Image files (ending with the .tjsn suffix) - An image file is simply the json text from the camera's image json packet.
* Movie (video) files (ending with the .tmjsn suffix) - A movie file consists of multiple image json text strings, one for each camera image json packet followed by a special "video_info" json text string.  Each json text string is separated by a character with the value 0x03 (the same as the END\_OF\_JSON delimiter used when an image is sent over a network interface).

The "video_info" json text string contains the starting and ending timestamps and number of frames.  It is used by the application to validate the file and also determine if it should show the "Fast Forward" control for videos with long delays between frames.

```
{
	"video_info": {
		"end_date": "2/2/21",
		"end_time": "21:53:10.8",
		"num_frames" 143,
		"start_date": "2/2/21",
		"start_time": "21:52:46.8",
		"version": 1
	}
}
```

Example files are found in the "sample_files" subdirectory here.

### Firmware Updates
The ```Update Firmware``` menu selection is available for cameras that support over-the-air FW updates.  Selecting it opens a file selection dialog box.  Open a FW binary file appropriate for the camera.

* tCam-Mini / tCam-POE - Open a ```tCamMini.bin``` binary file.
* tCam - Open a ```tCam.bin``` binary file.

An error message is displayed if the selected file is not the appropriate binary file for the connected camera.  A warning message is displayed if the selected file has a version that is equal to or less than the version the camera is currently running.

Once a binary file has been loaded the camera will indicate that a firmware update has been requested.  The user must perform an action on the camera to initiate the update.

* tCam-Mini / tCam-POE - LED alternating green/red blinking pattern.  Press the Wifi Reset button to initiate the update.
* tCam - Pop-up message appears on the LCD.  Select ```Confirm``` to initiate the update.

A progress bar is displayed in a dialogue box during the firmware update.  The camera will reboot once the firmware update is completed successfully.  An error message is displayed if the update is unsuccessful.

### A Note about AGC
This application is designed primarily for use with the Camera's Lepton outputting radiometric data because that data allow analysis of scene temperature, even from a stored image or video file.  A linear transformation is performed on the data to generate a visual image.  This image may not be as good, visually, as an image generated when the Lepton AGC is enabled so this mode is also supported for the cases where the user prefers a better image at the expense of being able to access the temperature of each pixel.  The Spotmeter is still functional in AGC mode so the temperature at one point can still be displayed.

Read the Flir Lepton 3.5 datasheet for a better description of AGC mode (and why Flir is clearly so proud of it...).

### A Note about the Lepton 3.0
Since the Lepton 3.0 does not support Radiometric data output the application suppresses all temperature related controls and displays.

### Fin

If you've read all the way down here you must be somewhat serious about this program that I've put a lot of work into.  It represents the functionality I find useful in a thermal imaging camera and I hope you do too.  Try it, let me know what you think and what you think I could do better.  I might be able to add your suggestion.

I am also available for hire to modify the application for custom applications.

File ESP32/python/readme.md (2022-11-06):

# Note

As of Nov 6 2022, the ESP32 designs have been moved to their own respository [tCam](https://www.github.com/danjulio/tCam) to make it easier for most people who are only interested in those files.  Files here will no longer be updated.

## tCam-Mini Python Driver
Todd LaWall (bitreaper) wrote a python 3 driver to allow access to tCam and tCam-Mini from python programs.  The driver supports accessing tCam and tCam-Mini via the network socket interface and also supports accessing tCam-Mini via the hardware Slave Interface on a Raspberry Pi.

### tcam.py
The ```tcam.py``` file contains an object ```TCam``` used to connect to and communicate with a camera.  It manages the network socket or direct hardware connection and provides an API for sending commands to the camera and for receiving responses back from the camera.  It uses three queues to handle the asynchronous nature of the interface.  A command queue is used for outgoing commands to the camera.  Responses from the camera are pushed into two incoming queues.  Image responses are stored in a special image queue.  All other responses are stored in a response queue.  The API hides queue operation.  API operations are single threaded and do not return until a response is returned or a timeout expires.  All response packets are presented as a python dictionary built from the json response string.

### ioctl\_numbers.py
The ```ioctl_numbers.py``` includes helpers for use when communicating with tCam-Mini via the hardware interface.  It must be included with ```tcamp.py```.

#### Network Usage
Include the TCam object from ```tcam.py``` file in your program.

	from tcam import TCam

Create a reference.

	cam = TCam()

Open a connection to the camera.

	cam.connect(<ip_address>)

where ```<ip_address>``` is the camera's IP address as a string.  The connect method returns a response indicating of the connection was successful or not.

	{"status": "timeout"}
	{"status": "connected"}

#### Hardware Interface Usage
See below for a diagram showing how to connect the tCam-Mini hardware Slave Interface to the Raspberry Pi default serial and SPI ports.

Use the Raspberry Pi Configuration tool to enable the serial interface (make sure the console on that port is disabled) and the SPI port.  Increase the maximum SPI transfer the Pi can perform by editing the ```/boot/cmdline.txt``` file and add the following string to the end of the line in that file.  Reboot the Pi after making this change.

	spidev.bufsiz=65536
	
Include the TCam object from ```tcam.py``` file in your program.

	from tcam import TCam

Create a reference.

	cam = TCam(is_hw=True)

Open a connection to the camera using the default serial (```/dev/serial0```) and SPI master (```/dev/spidev0.0```).

	cam.connect()

To use alternate Pi hardware, specify the device files in the connect method.

	cam.connect(spiFile='/dev/spidev0.1', serialFile='/dev/serial1')
	
### Common API
A common API is used to access and control the attached camera.

Many API calls take an optional timeout value which specify the number of seconds to wait for a response when using the socket interface.  By default the timeout value is 10 seconds.

#### start\_stream(self, delay\_msec=0, num\_frames=0, timeout=None)

	rsp = cam.start_stream()

Sends a ```stream_on``` command to the attached camera.

| Argument | Description |
| --- | --- |
| delay_msec | Delay, in mSec, between frames.  A value of 0 specifies fastest stream.  Non-zero values should be greater than 250 mSec. |
| num_frames | Number of frames to send.  A value of 0 specifies to stream until stopped. |

Returns the ```cam_info``` json response to the command, typically 

	{"cam_info":{"info_value":1,"info_string":"stream_on success"}}

#### stop\_stream(self, timeout=None)

	rsp = cam.stop_stream()

Sends a ```stream_off``` command to the attached camera.

Returns the ```cam_info``` json response to the command.

#### get\_image(self, timeout=None)

	img = cam.get_image()

Sends a ```get_image``` command to the attached camera.

Returns the ```image``` json response.  See the demo code for examples how to process the response into an image using the radiometric and telemetry data.

#### get\_frame(self)

	img = cam.get_frame()

Used to get images from the internal queue when streaming.

Returns an ```image``` json response or None if there are no images available.

#### frame\_count(self)

	num = cam.frame_count()

Returns the number of pending images in the internal queue.  Useful while streaming to determine if there are images to process.

#### run\_ffc(self, timeout=None)
	
	rsp = cam.run_ffc()

Sends a ```run_ffc``` command to the attached camera to initiate a Flat Field Correction.

Returns the ```cam_info``` json response to the command.

#### get\_status(self, timeout=None)

	rsp = cam.get_status()

Sends a ```get_status``` command to the attached camera.

Returns the ```status``` json response.  For example

	{"status":{"Camera":"tCam-Mini-87E9","Model":262402,"Version":"3.0","Time":"9:55:48.149","Date":"8/7/22"}}

#### set\_time(self, hour=None, minute=None, second=None, dow=None, day=None, month=None, year=None, timeout=None)

	rsp = cam.set_time(9, 45, 00, 1, 7, 8, 52)

Sends a ```set_time``` command to the attached camera.  The above example sets the time 09:45:00 on Sunday Aug 7, 2022.

| Argument | Description |
| --- | --- |
| hour | Hour 0 - 23 |
| minute | Minute 0 - 59 |
| second | Second 0 - 59 |
| dow | Day of Week starting with Sunday 1-7 |
| day | Day of Month 1-28 to 1-31 depending |
| month | Month 1-12 |
| year | Year offset from 1970 |

All arguments are required.

Returns the ```cam_info``` json response to the command.

#### get\_config(self, timeout=None)

	rsp = cam.get_config()

Sends a ```get_config``` command to the attached camera.

Returns the ```config``` json response.  For example

	{"config":{"agc_enabled":0,"emissivity":98,"gain_mode":2}}

#### set\_config(self, agc\_enabled=1, emissivity=98, gain\_mode=2, timeout=None)

	rsp = cam.set_config(0, 96, 0)

Sends a ```set_config``` command to the attached camera.  The above example sets AGC off, the emissivity to 96% and gain mode too High.

| Argument | Description |
| --- | --- |
| agc_enabled | Lepton AGC Mode: 1: Enabled, 0: Disabled (Radiometric output) |
| emissivity | Lepton Emissivity: 1 - 100 (integer percent) |
| gain_mode | Lepton Gain Mode: 0: High, 1: Low, 2: Auto |

All arguments are required.

Returns the ```cam_info``` json response to the command.

#### set\_config\_agc(self, agc\_enabled=1, timeout=None)

	rsp = cam.set_config_agc(0)

Sends a ```set_config``` command to the attached camera with only the agc_enabled argument.  The above example sets AGC off.

| Argument | Description |
| --- | --- |
| agc_enabled | Lepton AGC Mode: 1: Enabled, 0: Disabled (Radiometric output) |

Returns the ```cam_info``` json response to the command.

#### set\_config\_emissivity(self, emissivity=98, timeout=None)

	rsp = cam.set_config_emissivity(96)

Sends a ```set_config``` command to the attached camera with only the emissivity argument.  The above example sets the emissivity to 96%.

| Argument | Description |
| --- | --- |
| emissivity | Lepton Emissivity: 1 - 100 (integer percent) |

Returns the ```cam_info``` json response to the command.

#### set\_config\_gain\_mode(self, gain\_mode=2, timeout=None)

	rsp = cam.set_config(0)

Sends a ```set_config``` command to the attached camera with only the gain_mode argument.  The above example sets the gain mode too High.

| Argument | Description |
| --- | --- |
| gain_mode | Lepton Gain Mode: 0: High, 1: Low, 2: Auto |

Returns the ```cam_info``` json response to the command.

#### get\_lep\_cci(self, command=0x4ECC, length=4, timeout=None)

	cci_data = cam.get_lep_cci(0x4EBC, 8)

Sends a ```get_lep_cci``` command to the attached camera.  The above example gets the RAD Flux Linear Parameters.  The command default arguments get the RAD Spotmeter Region of Interest (ROI).

| Argument | Description |
| --- | --- |
| command | 16-bit Lepton COMMAND register value.  Issuing RAD commands requires setting the OEM Bit (Bit 14, value = 0x4000) in the command word in addition to setting the rest of the command word bits. |
| length | Number of 16-bit words to read (1-512) |

All arguments are required.

Returns the ```cci_reg``` json response to the command.  The example will return

	{"command":20156,"length":8,"status":63750,"data":"BQAAADA3MjYtMDEAAAAAAA=="}}

Refer to the Flir document "Software Interface Description Document (IDD)" Document Number: 110-0144-04 Rev 200 for a complete description of the CCI interface including commands, command lengths and data format.

#### set\_lep\_cci(self, command, data, timeout=None)

	reg_array = array.array('H', [20, 20, 21, 21])
	enc_data = reg_array.tobytes()
	rsp = cam.set_lep_cci(0x4ECD, enc_data)

Sends a ```set_lep_cci``` command to the attached camera.  The above example sets the spot meter region of interest to (20, 20) - (21, 21).

| Argument | Description |
| --- | --- |
| command | 16-bit Lepton COMMAND register value.  Issuing RAD commands requires setting the OEM Bit (Bit 14, value = 0x4000) in the command word in addition to setting the rest of the command word bits. |
| data | Data to write to the camera.  Must be a multiple of 16-bit words. |

All arguments are required.

Returns the ```cci_reg``` json response to the command.  The example will return

	{"cci_reg":{"command":20173,"length":0,"status":6}}

Take care using this command. It is possible to crash the Lepton or tCam camera (a power-cycle should restore normal operation).

#### set\_spotmeter(self, c1=79, c2=80, r1=59, r2=60, timeout=None)

	rsp = cam.set_spotmeter(90, 92, 70, 72)

Sends a ```set_spotmeter``` command to the attached camera.  The above example sets the spot meter region of interest to (90, 70) - (92, 72).

| Argument | Description |
| --- | --- |
| c1 | Spotmeter column 1: Left X-axis spotmeter box coordinate (0-159) |
| c2 | Spotmeter column 2: Right X-axis spotmeter box coordinate (0-159) |
| r1 | Spotmeter row 1: Top Y-axis spotmeter box coordinate (0-119) |
| r2 | Spotmeter row 2: Bottom Y-axis spotmeter box coordinate (0-119) |

All arguments are required.

Returns the ```cam_info``` json response to the command.

#### get\_wifi(self, timeout=None)

	rsp = cam.get_wifi()

Sends a ```get_wifi``` command to the attached camera.

Returns the ```wifi``` response.  For example

	{"wifi":{"ap_ssid":"tCam-Mini-289B","sta_ssid":"","flags":15,"ap_ip_addr":"192.168.4.1","sta_ip_addr":"192.168.4.2","sta_netmask":"255.255.255.0","cur_ip_addr":"10.0.1.123"}}

#### set\_wifi\_ap(self, ap\_ssid, ap\_pw, timeout=None)

	cam.set_wifi_ap("AP_SSID", "AP_PASSWORD")

Sends a ```set_wifi``` command to the attached camera to configure it as an Access Point with the specified SSID and password.

| Argument | Description |
| --- | --- |
| ap_ssid | Access Point SSID (1-32 characters).  Also becomes the camera name. |
| ap_pw | Access Point WPA password (8-32 characters). |

All arguments are required.

There is no return value.  You must call ```cam.disconnect()``` following this call since the camera will have disconnected the socket.

#### set\_wifi\_sta(self, sta\_ssid, sta\_pw, is\_static=False, sta\_ip\_addr="192.168.0.2", sta\_ip\_netmask="255.255.255.0", timeout=None)

	cam.set_wifi_sta("STA_SSID", "STA_PW")

Sends a ```set_wifi``` command to the attached camera to configure it as a client to an existing WiFi network obtaining a DHCP-served IP address.

	cam.set_wifi_sta("TA_SSID", "STA_PW", True, "10.0.1.73", "255.255.255.0")

Sends a ```set_wifi``` command to the attached camera to configure it as a client to an existing WiFi network with the specified static IP address.

| Argument | Description |
| --- | --- |
| sta_ssid | Existing WiFi network SSID (1-32 characters) |
| sta_pw | Existing WiFi network password (8-32 characters) |
| is_static | Set True to configure a static IP address, False for a DHCP-served address |
| sta_ip_addr | Static IP address string |
| sta_ip_netmask | Static IP address netmask string |

Only ```sta_ssid``` and ```sta_pw``` are required. 

There is no return value.  You must call ```cam.disconnect()``` following this call since the camera will have disconnected the socket.

#### set\_static\_ip(self, is\_static=False, sta\_ip\_addr="192.168.0.2", sta\_ip\_netmask="255.255.255.0", timeout=None)

	cam.set_static_ip()
	
Sends a ```set_wifi``` command to the attached camera to configure it to receive a DHCP-served IP address.

	cam.set_static_ip(True, "10.0.1.73", "255.255.255.0")
	
Sends a ```set_wifi``` command to the attached camera to configure it with a static IP address (10.0.1.73 in this example).

| Argument | Description |
| --- | --- |
| is_static | Set True to configure a static IP address, False for a DHCP-served address |
| sta_ip_addr | Static IP address string |
| sta_ip_netmask | Static IP address netmask string |

This command should only be run for a WiFi connected camera in STA mode or for an ethernet connected tCam-POE.  It will have no effect for a WiFi connected camera acting as an Access Point.

There is no return value.  You must call ```cam.disconnect()``` following this call since the camera will have disconnected the socket.

#### disconnect(self)

	cam.disconnect()
	
Disconnect the driver from the camera.

#### shutdown(self)

	cam.shutdown()
	
Shut down the driver before finishing your program to close the socket or hardware connection and terminate an internal manager thread.

### Demos
The ```examples``` directory contains several example python programs using the TCam driver.

The example programs take command line arguments.  Look at the source code for example-specific arguments but all socket examples allow specifying the camera IP address as shown.  By default the TCam driver attempts to connect to the default tCam-as-AP address of ```192.168.4.1```.

	disp_image.py -i 10.0.1.71

Some of the demo programs like ```disp_file.py``` and ```dump_image.py``` must be run in the same directory as the ```palettes``` directory.

The ```streamtest_hw.py``` program demonstrates how to use the driver with the hardware interface on a Raspberry Pi.  A tCam-Mini must be connected as shown below.

### tCam-Mini Hardware Interface Connections

tCam-Mini with Pi 3

The tCam-Mini hardware Slave Interface is enabled on power-up when the tCam-Mini detects a jumper from the MODE pin to GND.  Seven wires interface the Slave Interface to the Pi and provide power as shown below.  Be sure to make all the connections before applying power to the Pi.

tCam-Mini Wiring Diagram

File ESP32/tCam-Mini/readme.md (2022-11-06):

# Note

As of Nov 6 2022, the ESP32 designs have been moved to their own respository [tCam](https://www.github.com/danjulio/tCam) to make it easier for most people who are only interested in those files.  Files here will no longer be updated.

## tCam-Mini
tCam-Mini was created using code from the tCam project and ended up being finished first.  It is a simple device, hardware-wise, consisting of an ESP32 WROVER module, USB UART for programming and debug, Lepton 3.0/3.5 and supporting voltage regulators and oscillator.

tCam-Mini Front and Back

(image courtesy of Group Gets)

Revision 4 of the PCB, along with FW 2.0 and beyond, introduces a new hardware expansion port that can be used by an external micro-controller or single-board computer to communicate with tCam-Mini directly instead of using WiFi.  It also has an I2C expansion port that is currently unused, a USB-C connector and surface-mount LED.

### Firmware
The "Firmware" directory contains a V4.4.2 Espressif ESP32 IDF project for tCam-Mini. You should be able to build and load it into a camera using the IDF commands.  There are also a set of precompiled binaries in the "precompiled" sub-directory.  You can use the Espressif tool and instructions found in the "programming" directory in parallel to this one to load those into a camera without having to build the project.

The precompiled firmware and Windows-based programming application can be downloaded directly from my [website](http://danjuliodesigns.com/products/tcam_mini.html) as well if you don't want to clone this entire repository.

Cameras running FW 2.0 and beyond can also use the over-the-air update capability in the Desktop application to load new firmware files.

This firmware also provides support for an ethernet interface using the built-in ESP32 MAC and an external PHY chip implemented with the tCam-POE PCB.  A GPIO pin is pulled low to indicate the firmware is running on the tCam-POE PCB.

#### FW 3.1 (9/1/2022)
FW revision 3.1 fixes issues and enhances Lepton support.

 1. Moved to Espressif IDF 4.4.2 (now using esp_netif, adjusted task priorities, stack size).
 2. Support 63 character WiFi passwords.
 3. Fixed bug with Lepton detection.
 4. Fixed bug where WiFi restart fails when setting client mode with static IP.

#### FW 3.0 (8/6/2022)
FW revision 3.0 is a major new release.  It is designed to run on tCam-Mini and tCam-POE PCBs with Revision 3 silicon and 8 MB Flash memory).

1. Support tCam-POE board
2. Optimize flash reads for improved performance
3. Added mDNS for camera discovery
4. Changed model usage to support tCam-POE (model 2 is for tCam-Mini board, model 3 is for tCam-POE board)
5. Added Interface Type flags to model number
6. Add timeout to SPI slave read
7. Blink error LED if SPI Slave fails
8. Fix bug where unknown json command would crash camera

#### FW 2.1 (2/5/2022)
FW revision 2.1 fixes the following issues.  It is designed to run on the tCam-Mini PCBs with Revision 3 silicon and 8 MB Flash memory (camera's built using Revision 1 silicon or less than 8 MB Flash memory should use FW revision 1.3).  It fixes an issue where setting a password of less than 8 characters would brick the tCam-Mini (requiring reload of firmware using the Windows utility).

1. Prevent updating Wifi password if the length is less than 8 characters to avoid a condition where the ESP32 wifi library fails on boot and the camera can't be reconfigured.
2. Add the ability to reset WiFi even when the camera has detected a hardware fault on boot (backup solution to #1 above).

#### FW 2.0 (11/23/2021)
FW revision 2.0 adds the following new features.  It is designed to run on the tCam-Mini PCBs with Revision 3 silicon and 8 MB Flash memory (camera's built using Revision 1 silicon or less than 8 MB Flash memory should use FW revision 1.3).

1. Faster performance - often reaching the full 8.7 fps over WiFi.
2. Support for Lepton 3.0.
3. Support for OTA FW updates (from the Desktop Application 2.0). It won’t be necessary to use the serial IF and Espressif utility to load new firmware releases after 2.0 is loaded.
4. Support for a new HW Slave interface (available on PCB revision 4) for direct connect to another Micro (I use this for tCam).

### Hardware
The "Hardware" directory contains PCB and stencil Gerber files, a BOM and a schematic PDF.  These can be used to build a tCam-Mini on the PCB I designed.  Of course you can also buy a pre-assembled unit from [Group Gets](https://store.groupgets.com/products/tcam-mini) with or without the Lepton.  See below for instructions on building one from commonly available development boards.

Note: My interests are in radiometric thermography so I have focused primarily on the Lepton 3.5.  The Lepton 3.0 is supported starting with FW 2.0.  It should be possible for someone to modify my firmware source to work with the Lepton 2 and 2.5 models by modifying the task that reads the lepton (probably easiest to modify the code that reads the data and then just pixel-double it before handing it off to other tasks).  I will be happy to include a link to anyone else's clone of my code that supports these older Leptons.

### Operation
tCam-Mini is a command-based device.  It is designed for software running on another device to control it and receive responses and image data from it.  The software communicates with tCam-Mini via one of two ways depending on the polarity of the Mode input at boot.

1. Mode bit left disconnected (pulled high) configures communication via WiFi using a socket interface with commands, responses and images encoded as json packets.  Data is not encrypted so appropriate care should be taken.
2. Mode bit low (grounded) configures communication via the Hardware Interface using a serial interface and a slave SPI interface.  Commands and responses are sent as json packets over the serial interface.  A new "image_ready" packet indicates that the controller can read an image from the SPI interface.

#### USB Port
The USB Port provides a USB Serial interface supporting automatic ESP32 reset and boot-mode entry for programming.  It is also used for serial logging output by the ESP32 firmware (115,200 baud).

#### Status Indicator
A dual-color (red/green) LED is used to communicate status.  Combinations of color and blinking patterns communicate various information.

| Status Indicator | Meaning |
| --- | --- |
| Off or Dim | Firmware did not start |
| Solid Red | Firmware is running: initializing and configuring the Lepton and WiFi (when configured to use WiFi)|
| Blinking Yellow | WiFi AP Mode : No client connected to camera's WiFi |
|  | WiFi Client Mode : Not connected to an AP |
| Solid Yellow | WiFi AP Mode : Client connected to camera'sWiFi |
|  | WiFi Client Mode : Connected to an AP |
| Solid Green | Wifi Mode : WiFi is connected and external software has connected via the socket interface|
|  | Hardware Interface Mode : Camera is ready for operation |
| Fast Blink Yellow | WiFi Reset in progress |
| Alternating Red/Green | Over-the-air FW update has been requested.  Press the button to initiate the update |
| Blinking Green | FW update in process (blinking my occur at irregular intervals as the Flash memory is written) |
| Series of Red Blinks | A fault has been detected.  The number of blinks indicate the fault type (see table below) |

| Fault Blinks | Meaning |
| --- | --- |
| 1 blink | ESP32 I2C or SPI peripheral initialization failed |
| 2 blinks | ESP32 Non-volatile storage or WiFi initialization failed |
| 3 blinks | ESP32 static memory buffer allocation failed (potential PSRAM issue) |
| 4 blinks | Lepton CCI communication failed (I2C interface) |
| 5 blinks | Lepton VoSPI communication failed (SPI interface) |
| 6 blinks | Internal network error occurred |
| 7 blinks | Lepton VoSPI synchronization cannot be achieved |
| 8 blinks | Over-the-air FW Update failed |

Additional start-up and fault information is available from the USB Serial interface.

#### WiFi
tCam-Mini can act as either an Access Point (creating its own WiFi network) or a client (connecting to an existing WiFi network).  WiFi is enabled when the Mode input is high (left floating) when tCam-Mini boots.  The camera acts as an Access Point (AP) by default.  It selects an SSID based on a unique MAC ID in the ESP32 with the form "tCam-Mini-HHHH" where "HHHH" are the last four hexadecimal digits of the MAC ID.  There is no password by default.  When acting as an Access Point, each tCam-Mini always has the same default IPV4 address (192.168.4.1).

It can be reconfigured via a command (for example, from the desktop application) to act as a WiFi Client (STAtion mode) and connect to an existing WiFi network.  When configured as a WiFi Client, it can either get a DHCP served address from the network's router or it can also be reconfigured to have a fixed (static) IPV4 address.  Using a static address makes it easier to connect to tCam-Mini because you don't have to find out what DHCP address the router gave it by logging into the router or using a utility like the Fing Android app or nmap on Linux.

Currently only one device can connect to the camera at a time.

Please see the set of instructions in the DesktopApp folder in this repository for connecting to tCam-Mini in either mode.

#### WiFi Reset Button
Pressing and holding the WiFi Reset Button for more than five seconds resets the WiFi interface back to the default AP mode.  The status indicator will blink a pattern indicating the reset has occurred (see below).

Pressing the button quickly when an OTA FW update has been requested (LED alternating red/green) by the Desktop application initiates the update process.

#### Hardware Interface
The hardware interface is enabled when the Mode input is low (grounded) when tCam-Mini boots.

tCam-Mini Hardware Interface

The serial port (running at 230,400 baud) is used to send and receive commands and responses as described below.  Instead of sending an "image" response over the relatively slow serial port, the firmware sends an "image_ready" response to notify software running on the external system that it can read the image from the slave SPI port using a master SPI peripheral.

The slave SPI port is partially handled by a driver running on the ESP32.  For this reason the highest supported clock rate is 8 MHz.  Too fast and the ESP32 slave SPI driver can't keep up.  I found success running the interface at 7 MHz.

#### mDNS Discovery
The cameras advertise themselves on the local network using mDNS (Bonjour) starting with firmware revision 3.0 to make discovering their IPV4 addresses easier.

* Service Type: "\_tcam-socket._tcp."
* Host/Instance Name: Camera Name (e.g. "tCam-Mini-87E9")
* TXT Records:
	1. "model": Camera model (e.g. "tCam", "tCam-Mini", "tCam-POE")
	2. "interface": Communication interface (e.g. "Ethernet", "WiFi")
	3. "version": Firmware version (e.g. "3.0")

### Command Interface
The camera is capable of executing a set of commands and generating responses or sending image data when connected to a remote computer via one of the interfaces.  It can support one remote connection at a time.  Commands and responses are encoded as json-structured strings.  The command interface exists as a TCP/IP socket at port 5001 when using WiFi.

Each json command or response is delimited by two characters.  A Start delimiter (8-bit value 0x02) precedes the json string.  An End delimiter (8-bit value 0x03) follows the json string.  The json string may be tightly packed or may contain white space.

```<0x02><json string><0x03>```

The camera currently supports the following commands.  The communicating application should wait for a response from commands that generate one before issuing subsequent commands (although the camera command buffer is 12,288 bytes (sized for the ```fw_segment``` command) and can support multiple short commands).

| Command | Description |
| --- | --- |
| [get_status](#get_status) | Returns a packet with camera status.  The application uses this to verify communication with the camera. |
| [get_image](#get_image) | Returns a packet with metadata, radiometric (or AGC) image data and Lepton telemetry objects. |
| [set_time](#set_time) | Set the camera's clock. |
| [get_config](#get_config) | Returns a packet with the camera's current settings. |
| [get\_lep_cci](#get_lep_cci) | Reads and returns specified data from the Lepton's CCI interface. |
| [run_ffc](#run_ffc) | Initiates a Lepton Flat Field Correction. |
| [set_config](#set_config) | Set the camera's settings. |
| [set\_lep_cci](#set_lep_cci) | Writes specified data to the Lepton's CCI interface. |
| [set_spotmeter](#set_spotmeter) | Set the spotmeter location in the Lepton. |
| [stream_on](#stream_on) | Starts the camera streaming images and sets the interval between images and an optional number of images to stream. |
| [stream_off](#stream_off) | Stops the camera from streaming images. |
| [get_wifi](#get_wifi) | Returns a packet with the camera's current WiFi and Network configuration. |
| [set_wifi](#set_wifi) | Set the camera's WiFi and Network configuration.  The WiFi subsystem is immediately restarted.  The application should immediately close its socket after sending this command. |
| [fw\_update_request](#fw_update_request) | Informs the camera of a OTA FW update size and revision and starts it blinking the LED alternating between red and green to signal to the user a OTA FW update has been requested. |
| [fw_segment](#fw_segment) | Sends a sequential chunk of the new FW during an OTA FW update. |

The camera generates the following responses.

| Response | Description |
| --- | --- |
| [cam_info](#cam_info-messages) | Generic information packet from the camera.  Status for commands that do not generate any other response.  May also contain alert or error messages from the camera. |
| [cci_reg](#cci_reg-response) | Response to both get\_cci\_reg and set\_cci\_reg commands. |
| [config](#get_config-response) | Response to get_config command. |
| [get_fw](#get_fw) | Request a sequential chunk of the new FW during an OTA FW update. |
| [image](#get_image-response) | Sent by the camera over the network as a response to get_image command or initiated periodically by the camera if streaming has been enabled. |
| [image_ready](#image_ready-response) | Sent by the camera over the serial interface when an image is ready to be read through the SPI interface. |
| [status](#get_status-response) | Response to get_status command. |
| [wifi](#get_wifi-response) | Response to get_wifi command. |

Commands and responses are detailed below with example json strings.

#### get_status
```{"cmd":"get_status"}```

#### get_status response
```
{
	"status": {
		"Camera":"tCam-Mini-EFB5",
		"Model":262402,
		"Version":"2.0",
		"Time":"17:33:49.0",
		"Date":"2/3/21"
	}
}
```
The get_status response may include additional information for other camera models (for example Battery/Charge information).

| Status Item | Description |
| --- | --- |
| Camera | AP SSID also used as the camera name. |
| Model | A 32-bit mask with camera information (see below). Software can use the camera model to enable and disable camera specific functionality. |
| Version | Firmware version. "Major Revision . Minor Revision" |
| Time | Current Camera Time including milliseconds: HH:MM:SS.MSEC |
| Date | Current Camera Date: MM/DD/YY |

| Model Bit | Description |
| --- | --- |
| 31:19 | Reserved - Read as 0 |
| 18 | Supports over-the-air FW updates |
| 17 | Has Filesystem Flag |
| 16 | Has Battery Flag |
| 15:14 | Reserved - Read as 0 |
| 13:12 | Interface Type (FW 3.0 and beyond) |
| | 0 0 - WiFi Interface |
| | 0 1 - Hardware Interface (Serial/SPI Interface) |
| | 1 0 - Ethernet Interface (tCam-POE only) |
| | 1 1 - Reserved |
| 11:10 | Reserved - Read as 0 |
| 9:8 | Lepton Type (FW 3.1 and beyond) |
| | 0 0 - Lepton 3.5 |
| | 0 1 - Lepton 3.0 |
| | 1 0 - Reserved |
| | 1 1 - Reserved |
| 7:0 | Camera Model Number - tCam-Mini reports 2 |

#### get_image
```{"cmd":"get_image"}```

#### get_image response
WiFi only.  Response to get_image or initiated periodically while streaming.

```
{
	"metadata":	{
		"Camera": "tCam-Mini-EFB5",
		"Model": 2,
		"Version": "1.0",
		"Time": "19:00:58.644",
		"Date": "2/3/21"
	},
	"radiometric": "I3Ypdg12B3YPdgt2BXYRdgF2A3YFdgF2AXYNdv91+3ULdvd..."
	"telemetry": "DgCDMSkAMAgAABBhCIKyzJpkj..."
}
```

| Image Item | Description |
| --- | --- |
| metadata | Camera status information at the time the image was acquired. |
| radiometric | Base64 encoded Lepton pixel data (19,200 16-bit words / 38,400 bytes).  Each pixel contains a 16-bit absolute (Kelvin) temperature value when the Lepton is operating in Radiometric output mode.  The Lepton's gain mode specifies the resolution (0.01 K in High gain, 0.1 K in Low gain). Each pixel contains an 8-bit value when the Lepton has AGC enabled. |
| telemetry | Base64 encoded Lepton telemetry data (240 16-bit words / 480 bytes).  See below for some important telemetry words and the Lepton Datasheet for a full description of the telemetry contents. |

#### image_ready response
Hardware Interface only.  Response to get_image or initiated periodically while streaming.

```{"image_ready": 51980}```

The ```image_ready``` response indicates that an image is available to read from the slave SPI interface.  The value indicates the number of bytes in the image, including the start and end delimiters. It is followed by a 4 byte checksum and 0-3 dummy bytes.  The dummy bytes may be necessary since the SPI read length must be a multiple of 4 bytes.  The SPI read must be a single operation and the image must be read from the slave SPI interface before another image will be sent.  For FW 2.0 and 2.1, the camera's response process hangs until the image is read.  Subsequent firmware releases timeout and discard the image after one second.

![SPI Data layout](pictures/hw_if_spi_data.png)

The checksum is simply the 32-bit sum of all ```image_ready``` response bytes with the high byte first.  It is used to validate that the SPI transfer successfully sent all bytes.  On occasion the ESP32 slave SPI driver may fail to keep up and the checksum is used to discard corrupt images.

#### get\_lep_cci
```
{
  "cmd": "get_lep_cci",
  "args": {
    "command": 20172,
    "length": 4
  }
}
```

| get\_lep_cci argument | Description |
| --- | --- |
| command | Decimal representation of the 16-bit Lepton COMMAND register value. For example, the value "20172" above is 0x4ECC (RAD Spotmeter Region of Interest). |
| length | Decimal number of 16-bit words to read (1-512). |

#### cci\_reg response
Response for get\_lep_cci.

```
{
  "cci_reg": {
    "command":20172,
    "length":4,
    "status":6,
    "data":"OwBPADwAUAA="
  }
}
```

| cci_reg Item | Description |
| --- | --- |
| command | Decimal representation of the 16-bit Lepton COMMAND register value read. |
| length | Decimal number of 16-bit words read. |
| status | Decimal representation of the 16-bit Lepton STATUS register with the final status of the read. |
| data | Base64 encoded Lepton register data. ```length``` 16-bit words.  For length <= 16 the data is from the Data Register 0 - 15.  For length > 16 the data is from Block Data Buffer 0. |

#### set_time
```
{
  "cmd": "set_time",
  "args": {
    "sec": 14,
    "min": 10,
    "hour": 21,
    "dow": 2,
    "day": 18,
    "mon": 5,
    "year": 50
  }
}
```
All set_time args must be included.

| set_time argument | Description |
| --- | --- |
| sec | Seconds 0-59 |
| min | Minutes 0-59 |
| hour | Hour 0-23 |
| dow | Day of Week starting with Sunday 1-7 |
| day | Day of Month 1-28 to 1-31 depending |
| mon | Month 1-12 |
| year | Year offset from 1970 |

#### get_config
```{"cmd":"get_config"}```

#### get_config response
Response to get_config.

```
{
	"config":{
		"agc_enabled":0,
		"emissivity":100,
		"gain_mode":0
	}
}
```

| Status Item | Description |
| --- | --- |
| agc_enabled | Lepton AGC Mode: 1: Enabled, 0: Disabled (Radiometric output) |
| emissivity | Lepton Emissivity: 1 - 100 (integer percent) |
| gain_mode | Lepton Gain Mode: 0: High, 1: Low, 2: Auto |

#### run_ffc
```{"cmd":"run_ffc"}```

The ```run_ffc``` command generates the following ```cam_info``` response.

```
{
  "cam_info": {
    "info_value": 1,
    "info_string": "run_ffc success"
  }
}
```

#### set_config
```
{
  "cmd": "set_config",
  "args": {
    "agc_enabled": 1,
    "emissivity": 98,
    "gain_mode": 2
  }
}
```
Individual args values may be left out.  The camera will use the existing value.

| set_config argument | Description |
| --- | --- |
| agc_enabled | Lepton AGC Mode: 1: Enabled, 0: Disabled (Radiometric output) |
| emissivity | Lepton Emissivity: 1 - 100 (integer percent) |
| gain_mode | Lepton Gain Mode: 0: High, 1: Low, 2: Auto |

```set_config``` items are stored in non-volatile flash memory for cameras operating with WiFi enabled, allowing them to persist across power cycles.  They are not stored in non-volatile memory for cameras operating with the Hardware Interface enabled and only persist until power is removed.  It is assumed the host device will configure the desired items during an initialization sequence.

#### set\_lep_cci
```
{
  "cmd":"set_lep_cci",
  "args": {
    "command":20173,
    "length":4,
    "data":"OwBPADwAUAA="
  }
}
```

| set\_cci_reg argument | Description |
| --- | --- |
| command | Decimal representation of the 16-bit Lepton COMMAND register value.  Note bit 0 must be set for a write. |
| length | Decimal number of 16-bit words written. |
| data | Base64 encoded Lepton register data to write. ```length``` 16-bit words.  For length <= 16 the data will be loaded into the Data Registers.  For length > 16 the data will be loaded into Block Data Buffer 0. |

Note: It is possible to crash the Lepton or camera using the CCI interface.

The ```set_lep_cci``` command generates the following ```cam_info``` response.

```
{
  "cci_reg": {
    "command":20173,
    "length":4,
    "status":6
  }
}
```

| cci_reg Item | Description |
| --- | --- |
| command | Decimal representation of the 16-bit Lepton COMMAND register value.  Note bit 0 will be set for a write. |
| length | Decimal number of 16-bit words written. |
| status | Decimal representation of the 16-bit Lepton STATUS register with the final status of the write. |

#### set_spotmeter
```
{
  "cmd": "set_spotmeter",
  "args": {
    "c1": 79,
    "c2": 80,
    "r1": 59,
    "r2": 60
  }
}
```

| set_spotmeter argument | Description |
| --- | --- |
| c1 | Spotmeter column 1: Left X-axis spotmeter box coordinate (0-159) |
| c2 | Spotmeter column 2: Right X-axis spotmeter box coordinate (0-159) |
| r1 | Spotmeter row 1: Top Y-axis spotmeter box coordinate (0-119) |
| r2 | Spotmeter row 2: Bottom Y-axis spotmeter box coordinate (0-119) |

Column c1 should be less than or equal to c2.  Row r1 should be less than or equal to r2.  All four argument values must be specified.  They specify the box of pixels the Lepton uses to calculate the spotmeter temperature (which is contained in the image telemetry).

#### stream_on
```
{
	"cmd":"stream_on",
	"args":{
		"delay_msec":0,
		"num_frames":0
	}
}
```

| stream\_on argument | Description |
| --- | --- |
| delay_msec | Delay between images.  Set to 0 for fastest possible rate.  Set to a number greater than 250 to specify the delay between images in mSec. |
| num_frames | Number of frames to send before ending the stream session.  Set to 0 for no limit (set\_stream_off must be sent to end streaming). |

Streaming is a slightly special case for the command interface.  Responses are typically generated after receiving the associated get command.  However the image response is generated repeatedly by the camera after streaming has been enabled at the rate, and for the number of times, specified in the set\_stream\_on command.

#### stream_off
```{"cmd":"stream_off"}```

#### get_wifi
```{"cmd":"get_wifi"}```

#### get_wifi response
```
{
  "wifi": {
    "ap_ssid": "tCam-Mini-EFB5",
    "sta_ssid": "HomeNetwork",
    "flags": 143,
    "ap_ip_addr": "192.168.4.1",
    "sta_ip_addr": "10.0.1.144",
    "sta_netmask":"255.255.255.0",
    "cur_ip_addr": "10.0.1.144"
  }
}
```

| Response | Description |
| --- | --- |
| ap_ssid | The camera's current AP-mode SSID and also the camera name as reported in the metadata and status packets. |
| sta_ssid | The SSID used when the camera's WiFi is configured as a client (STAtion mode) |
| flags | 8-bit Wifi Status as a decimal number (see below). |
| ap\_ip_addr | The camera's IP address when it is in AP mode. |
| sta\_ip_addr | The static IP address to use when the camera is a client and configured to use a static IP. |
| sta_netmask | The netmask to use when the camera is a client and configured to use a static IP. |
| cur\_ip_addr | The camera's current IP address.  This may be a DHCP served address if the camera is configured in Client mode with static IP addresses disabled. |

Password information is not sent as part of the wifi response.

| Flag Bit | Description |
| --- | --- |
| 7 | Client Mode - Set to 1 for Client Mode, 0 for AP mode. |
| 6:5 | Unused, will be set to 0. |
| 4 | Static IP - Set to 1 to use a Static IP, 0 to request an IP via DHCP. |
| 3 | Bit 3: Wifi Connected - Set to 1 when connected to another device. |
| 2 | Wifi Client Running - Set to 1 when the client has been started, 0 when disabled (obviously this bit will never be 0). |
| 1 | Wifi Initialized - Set to 1 when the WiFi subsystem has been successfully initialized (obviously this bit will never be 0). |
| 0 | Bit 0: Wifi Enabled - Set to 1 when Wifi has been enabled, 0 when Wifi has been disabled. |

#### set_wifi
```
{
  "cmd": "set_wifi",
  "args": {
    "ap_ssid": "ANewApName",
    "ap_pw: "apassword",
    "ap_ip_addr": "192.168.4.1",
    "flags": 145,
    "sta_ssid": "HomeNetwork",
    "sta_pw": "anotherpassword",
    "sta_ip_addr": "10.0.1.144",
    "sta_netmask": "255.255.255.0"
  }
}
```

Individual args values may be left out (for example to just set AP or Client (STA) values.  The camera will use the existing value.

| set_wifi argument | Description |
| --- | --- |
| ap_ssid | Set the AP-mode SSID and also the camera name as reported in the metadata and status objects (1-32 characters). |
| ap_pw | Set the AP-mode password (8-63 characters). |
| ap\_ip_addr | The camera's IP address when it is in AP mode. |
| flags | Set WiFi configuration (see below). |
| sta_ssid | Set the client-mode (STA) SSID (1-32 characters). |
| sta_pw | Set the client-mode (STA) password (8-63 characters). |
| sta\_ip_addr | Set the static IP address to use when the camera as a client and configured to use a static IP. |
| sta_netmask | Set the netmask to use when the camera as a client and configured to use a static IP. |

Only a subset of the flags argument are used to configure WiFi operation.  Other bit positions are ignored.

| Flag Bit | Description |
| --- | --- |
| 7 | Client Mode - Set to 1 for Client mode, 0 for AP mode. |
| 4 | Static IP - Set to 1 to use a Static IP, 0 to request an IP via DHCP when operating in Client mode. |
| 0 | Bit 0: Wifi Enabled - Set to 1 to enable Wifi, 0 to disable Wifi. |

The command will fail if an SSID is zero length or greater than 32 characters or if a password is less than 8 characters or greater than 63 characters.

Although I do not recommend it, use the following procedure to set a zero-length (null) password.

1. Reset the Wifi configuration using the Wifi reset button.  This sets all password fields to a null value.
2. Use the Desktop application to configure the Wifi but make sure the password field is not updated (de-select the Update checkbox).  Alternatively send a set_wifi command without a password (```ap_pw``` or ```sta_pw``` argument). 

#### cam_info messages
The ```cam_info``` response is generated for commands that do not return a response such as ```set_clock```, ```set_config``` or ```set_wifi``` with status about the success or failure of the command.  It can also be generated by the camera for certain errors.

For example, ```cam_info``` for ```set_clock``` looks like.

```
{
  "cam_info": {
    "info_value": 1,
    "info_string": "set_clock success"
  }
}
```

| cam_info Item | Description |
| --- | --- |
| info_value | A decimal status code (see below). |
| info_string | An information string. |

| cam_info status code | Description |
| --- | --- |
| 0 | Command NACK - the command failed.  See the information string for more information. |
| 1 | Command ACK - the command succeeded. |
| 2 | Command unimplemented - the camera firmware does not implement the command. |
| 3 | Command bad - the command was incorrectly formatted or was not a json string. |
| 4 | Internal Error - the camera detected an internal error.  See the information string for more information. |
| 5 | Debug Message - The information string contains an internal debug message from the camera (not normally generated). |

#### fw\_update_request
The ```fw_update_request``` command initiates the FW update process.

```
{
  "cmd":"fw_update_request",
  "args":{"length":730976,"version":"2.0"}
}
```

All arguments are required.

| fw\_update_request argument | Description |
| --- | --- |
| length | Length of binary file in bytes. |
| version | Binary file version.  This must match the build version embedded in the binary file. |

#### get_fw
The camera requests a chunk of the binary file using the ```get_fw``` response after the user has initiated the update.  Currently the camera will request a maximum of 8192 bytes.

```
{
  "get_fw":{
    "start":0,
    "length":8192
  }
}
```

| get_fw argument Item | Description |
| --- | --- |
| start | Starting byte of the current chunk (offset into binary file). |
| length | Number of bytes to send in a subsequent ```fw_segment```. |

#### fw_segment
Generated in response to a ```get_fw``` request.  Must always use the arguments in the ```get_fw``` request.

```
{
  "cmd":"fw_segment",
  "args":{
    "start":0,
    "length":8192,
    "data":"6QYCMPwUCEDuAAAAAAADAAAAAAAAAAABIABAPwjEAQAyVM2rAAAAAAAAA..."
  }
}
```

| fw_segment Argument | Description |
| --- | --- |
| start | Starting byte of current chunk. |
| length | Length of chunk in bytes. |
| data | Base64 encoded binary data chunk. |
 
### OTA FW Update Process
The OTA FW update process consists of several steps.  The FW is contained in the binary file ```tCamMini.bin``` in the precompiled FW directory or built using the Espressif IDF.  No other binary files are required.

1. An external computer initiates the update process by sending a ```fw_update_request```.
2. The camera starts blinking the LED in an alternating red/green pattern to indicate a FW update has been requested.  The user must press the Wifi Reset Button to confirm the update should proceed.
3. The camera sends a ```get_fw``` to request a chunk of data from the computer.
4. The computer sends a ```fw_segment``` with the requested data.
5. Steps 3 and 4 are repeated until the entire firmware binary file has been transferred.
6. The camera validates the binary file and sends a ```cam\_info``` indicating if the update is successful or has failed.  If successful the camera then reboots into the new firmware.

### Important Telemetry Locations

| Offset | 16-bit Word Description |
| --- | --- |
| 3 | Status Low (see below) |
| 4 | Status High |
| 99 | Emissivity (scaled by 8192) |
| 208 | TLinear Enabled Flag - 0 = disabled, 1 = enabled |
| 209 | TLinear Resolution Flag - 0 = 0.1, 1 = 0.01 |
| 210 | Spot Meter Mean - 16-bit radiometric value |
| 214 | Spot Meter Y1 coordinate |
| 215 | Spot Meter X1 coordinate |
| 216 | Spot Meter Y2 coordinate |
| 217 | Spot Meter X2 coordinate |

| Bit | Status Bit Description |
| --- | --- |
| 20 | Over Temperature Shut Down imminent (shutdown in 10 seconds) |
| 15 | Shutter Lockout - 0 = not locked out, 1 = locked out (outside of valid operating temperature range -10°C to 80°C) |
| 12 | AGC State - 0 = disabled, 1 = enabled |
| 5:4 | FFC State - 0 = Not commanded, 1 = Imminent, 2 = Running, 3 = Complete |
| 3 | FFC Desired |

#### Using telemetry data

The Status AGC State bit indicates the form of the pixel data.  When AGC is enabled the lepton performs a histogram analysis of the data and the pixel data is 8-bits (low byte of each 16-bit word) designed to directly index a palette array for display.  When AGC is disabled the lepton outputs 16-bit radiometric data in each pixel.  This data represents the actual temperature of each pixel in degrees Kelvin scaled by either 10 (TLinear Resolution Flag = 0) or 100 (TLinear Resolution Flag = 1).  The TLinear Resolution Flag indicates the gain mode of the Lepton (0 = Low Gain, 1 = High Gain).

The radiometric pixel temperature in °C may be computed using the following formula where TLinear resolution is 0.1 if TLinear Resolution Flag is 0 and 0.01 if TLinear Resolution Flag is 1.

``` TempC = Pixel[15:0] * TLinear_resolution - 273.15```

The Spot Meter average temperature value is computed using the same formula, substituting the Spot Meter Mean for pixel data, and is valid independent of AGC enabled or disabled.  The Spot Meter is the average value of the pixels in the box defined by the Spot Meter (X1, Y1) and (X2, Y2) coordinates.

The FFC State may be used to identify when the lepton is preparing to perform a FFC (flat field correction) and is performing a FFC.  While performing a FFC the lepton closes the shutter in front of the sensor array.  Image data is not available while a FFC is being performed.

### Previous version
![tCam-Mini Front and Back](pictures/tcam_mini_pcb_r2.png)

### Building with dev boards
A board like the [TTGO T7 V1.4](http://www.lilygo.cn/prod_view.aspx?TypeId=50033&Id=978&FId=t3:50033:3) ESP32 WROVER based development board is a way, along with a [Lepton Breakout](https://store.groupgets.com/products/purethermal-breakout-board) from Group Gets, to hand build a tCam-Mini.

You can use other ESP32 development boards, just make sure they have a PSRAM chip built-in (WROVER-based).

![ttgo based design](pictures/ttgo_version_side.png)

You'll also need the following components.

* Small proto board to build on.  I used a commonly available 4x6cm board.
* 5 10-pin 0.1" headers (4 for the TTGO V7 and 1 for the Lepton Breakout).
* A small tactile push button.
* A dual Red-Green common-cathode LED (I use a Lite-On LTL1BEKVJNN).
* Two 180-330 ohm resistors, 1/8 - 1/4 watt.
* Optional electrolytic capacitor.  This should only be necessary if there is a voltage drop when the Lepton performs a FFC causing it to malfunction due to inductance in the hand wiring.

The components are wired together as shown below.

![ttgo top and bottom](pictures/ttgo_version_top_bot.png)

![ttgo wiring diagram](pictures/ttgo_based_tcam_mini.png)

#### ESP32 Connections

| ESP32 GPIO | Connection |
| --- | --- |
|  0 | Button |
|  5 | Lepton SPI SCK |
| 12 | Lepton SPI CSN |
| 13 | Lepton Vsync |
| 14 | Red LED Anode |
| 15 | Green LED Anode |
| 19 | Lepton SPI MISO |
| 22 | Lepton I2C SCL |
| 23 | Lepton I2C SDA |

#### ESP Revision / Module Notes
The modules I buy from Mouser and that Group Gets sources for the PCB design include a Rev 3 ESP32 chip and I compile for that version.  Some dev boards may include a module with a Rev 1 ESP32.  For these modules you must use the version 1.6 firmware.  Modules with a Rev 3 ESP32 may use the latest firmware.  The binary files for each revision can be found in the firmware/precompiled subdirectory.  The camera won't boot if you use the wrong chip revision.

The PCB versions have 8 MB Flash modules (64 MBit) but the TTGO module is typically 4 MB (32 MBit).  Be sure to properly configure the flash size in the programmer to match your module or the firmware will fail to boot.  This is explained in the programming sub-directory readme.

To enable OTA updates the module must have at least 8 MB of Flash memory.  Modules with 4 MB of Flash can be programmed using the Espressif download tool but cannot be updated using OTA transfers.

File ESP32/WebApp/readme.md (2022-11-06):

# Note

As of Nov 6 2022, the ESP32 designs have been moved to their own respository [tCam](https://www.github.com/danjulio/tCam) to make it easier for most people who are only interested in those files.  Files here will no longer be updated.

## Simple tCam Web Server

This repository contains a simple web server application for the tCam cameras.  It communicates with one or more cameras via a network connection and acts as web server for viewing images and configuring the system.

tcam_web architecture

It can display an image from a camera or be configured to record images that meet certain detection criteria.  To do this it enables the cameras into streaming mode and analyzes the images it receives.  Right now the detection criteria are very simple.  It will record an image if at least certain percentage of pixels are within a specified temperature range. The image file format is the same as used by the tcam desktop application (containing he image json packet from the camera).

The detection criteria, along with some parameters limiting how many images can be stored based on a detection event, the streaming interval and camera configuration may be setup through the web interface.

tcam_web image view

The application is developed using the [xojo](https://www.xojo.com) development environment.  Sixty-four bit binary images are provided for Mac OS X, Windows and x86 Linux systems.  A 32-bit binary image is provided for Raspbian.  Download the zip file for your platform.  The application can be run directly from the unzipped directory by double clicking the application binary icon but is primarily designed to be executed from a command line or shell program.

#### Platform Caveats

1. You may need to make the Linux application file executable.
2. You will have to authorize the application to operate through the built-in firewall on OS X or Windows platforms.  Normally those systems will prompt you when the application is started.
3. I haven't tested beyond a handful of cameras and web sessions but the application is probably fairly limited in how many cameras and concurrent web sessions it can support.
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

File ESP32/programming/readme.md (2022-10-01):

## tCam/tCam-Mini Firmware Serial Upload
There are three ways to load firmware into tCam.

1. Using the Espressif build process after compiling the firmware.
2. Using a download tool from Espressif to load the pre-compiled firmware from this repository.
3. Using the Desktop application and the over-the-air (OTA) capability in tCam-Mini (FW Revision 2.0 and beyond) and all tCam FW revisions.

The second option is described here.  It requires a Microsoft Windows computer.
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

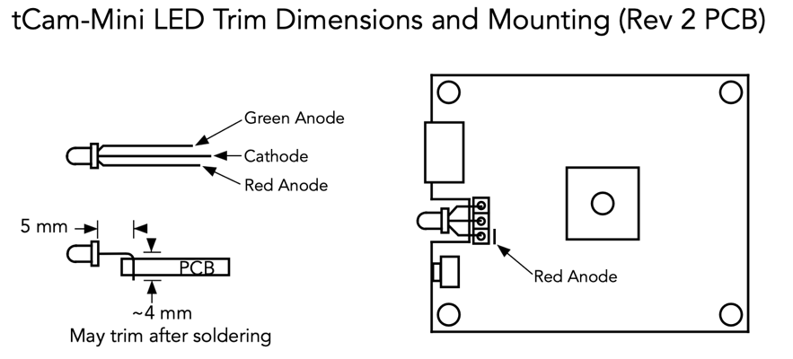
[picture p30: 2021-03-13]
ESP32/tCam-Mini/hardware/pictures/tcam_mini_led_r2.png

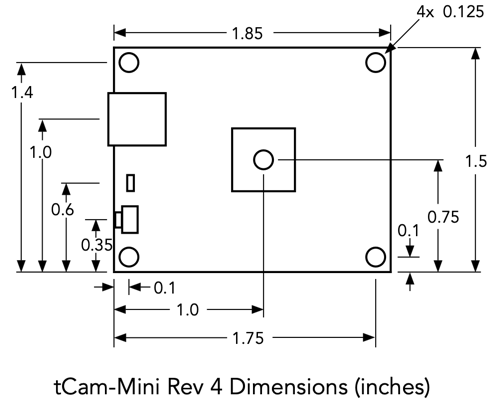
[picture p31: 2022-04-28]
ESP32/tCam-Mini/hardware/pictures/tcam_mini_r4_dimensions.png

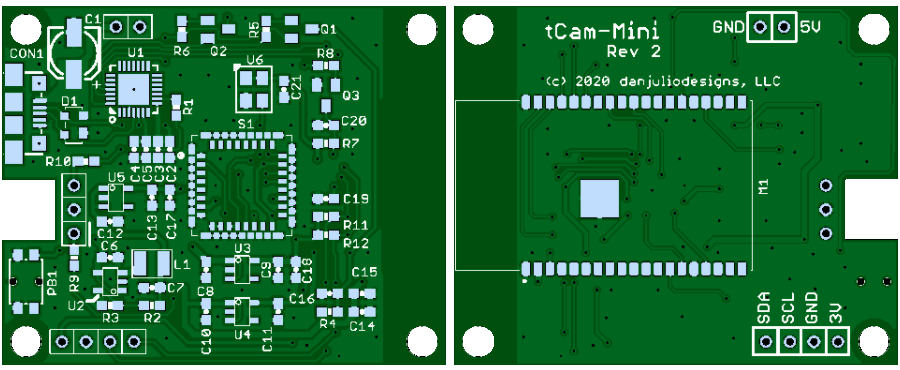
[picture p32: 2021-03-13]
ESP32/tCam-Mini/hardware/pictures/tcam_mini_pcb_r2_render.png

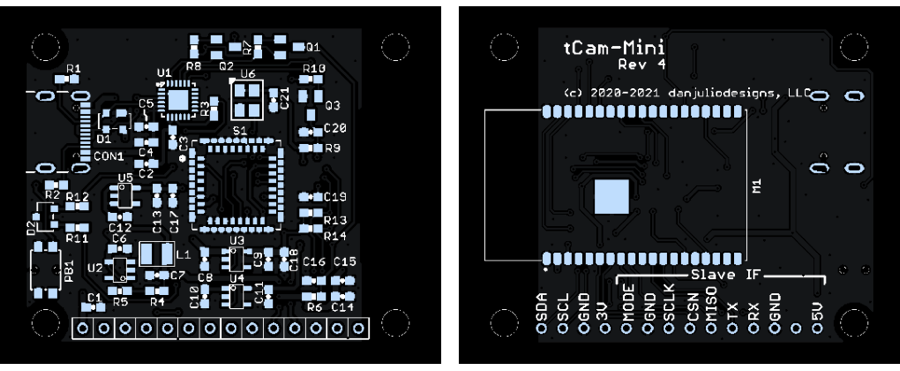
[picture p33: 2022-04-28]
ESP32/tCam-Mini/hardware/pictures/tcam_mini_pcb_r4_render.png

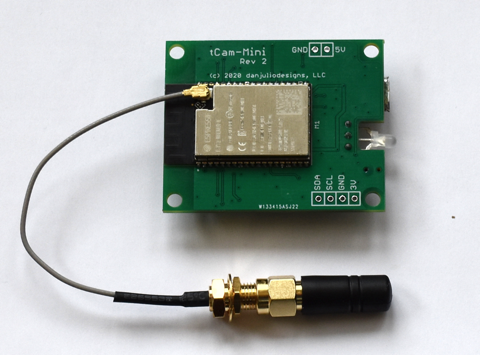
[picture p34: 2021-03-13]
ESP32/tCam-Mini/hardware/pictures/tcam_mini_ext_antenna.png

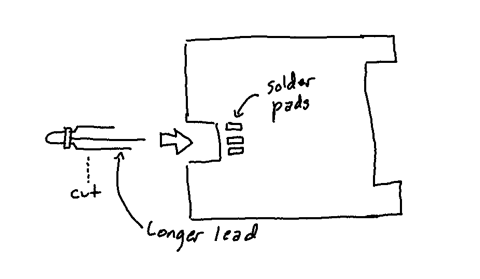
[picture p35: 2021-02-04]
ESP32/tCam-Mini/hardware/pictures/tcam_mini_led.png

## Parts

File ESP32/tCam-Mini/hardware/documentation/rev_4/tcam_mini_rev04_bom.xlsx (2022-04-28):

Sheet: tCam-Mini - Rev 04 - Top PCB As
tCam-Mini PCB Assembly - Top Side - Rev 04
Line No | Qty | Ref Desg | Part Number | Manuf | Package/Type | Desc | Distributor Part Number | Notes
1 | 4 | C1, C2, C4, C6 | JMK107BJ475KA-T | Taiyo Yuden | SMD/0603 | Multilayer Ceramic Capacitors MLCC - 6.3VDC 4.7uF 10% X5R | Mouser 963-JMK107BJ475KA-T | May substitute equal or better
2 | 8 | C3, C5, C14, C17, C18, C19, C20, C21 | EMK107B7104KAHT | Taiyo Yuden | SMD/0603 | Multilayer Ceramic Capacitors MLCC - 16VDC 0.1uF 10% X7R | Mouser 963-EMK107B7104KAHT | May substitute equal or better
3 | 3 | C7, C9, C15 | GRM188R60J226MEA0D | Murata | SMD/0603 | Multilayer Ceramic Capacitors MLCC - SMD/SMT 0603 22uF 6.3volts | Mouser 81-GRM188R60J226ME0D | May substitute equal or better
4 | 6 | C8, C10, C11, C12, C13, C16 | TMK107B7105KA-T | Taiyo Yuden | SMD/0603 | Multilayer Ceramic Capacitors MLCC - 25VDC 1uF 10% X7R | Mouser 963-TMK107B7105KA-T | May substitute equal or better
5 | 1 | CON1 | USB4105-GF-A | Global Connector Technology | SMD | USB Connectors USB Type C,2.0, Rec,SMT,TH Shell Stakes,G/F,RA,Top Mnt | Mouser 640-USB4105-GF-A | May substitute equal or better
6 | 1 | D1 | SP0503BAHTG | Littlefuse | SMD/SOT-143-4 | ESD Suppressors / TVS Diodes | Mouser 576-SP0503BAHTG
7 | 1 | D2 | AM23ESGW | Kingbright | SMT/SOT23 | Standard LEDs - SMD Red/Green Diffused, Common Cathode | Mouser 604-AM23ESGW
7 | 1 | L1 | MBMK2520T2R2M | Taiyo Yuden | SMD/0805 | Fixed Inductors 0805 2.2uH 159mOhms +/-20% 1250mA | Mouser 963-MBMK2520T2R2M | May substitute equal or better
8 | 1 | PB1 | 436351045816 | Wurth Elektronik | SMD | Tactile Switches Tact Switch SMT 1.65mm White Act. | Mouser 710-436351045816 | May substitute equal or better
9 | 3 | Q1, Q2, Q3 | MMBT3904-7-F | Diodes Incorporated | SMD/SOT23-3 | Bipolar Transistors - BJT 40V NPN SS Trans 60Vceo 6Vebo 200mA | Mouser 621-MMBT3904-F | May substitute equal or better
10 | 4 | R1, R2, R13, R14 | RC0603FR-075K1L | Yageo | SMD/0603 | Thick Film Resistors - SMD 5.1 kOhms 100mW 0603 1% | Mouser 603-RC0603FR-075K1L | May substitute equal or better
10 | 1 | R3 | RC0603FR-071KL | Yageo | SMD/0603 | Thick Film Resistors - SMD 1K OHM 1% | Mouser 603-RC0603FR-071KL | May substitute equal or better
11 | 1 | R4 | RC0603FR-0745K3L | Yageo | SMD/0603 | Thick Film Resistors - SMD 45.3K OHM 1% | Mouser 603-RC0603FR-0745K3L | May substitute equal or better
12 | 6 | R5, R6, R7, R8, R9, R10 | RC0603FR-0710KL | Yageo | SMD/0603 | Thick Film Resistors - SMD 10K OHM 1% | Mouser 603-RC0603FR-0710KL | May substitute equal or better
13 | 2 | R11, R12 | RC0603FR-07330RL | Yageo | SMD/0603 | Thick Film Resistors - SMD 330 OHM 1% | Mouser 603-RC0603FR-07330RL | May substitute equal or better
14 | 1 | S1 | 105028-1001 | Molex | SMD | IC & Component Sockets 8.5*8.5 AUTO FOCUS C AMERA SOCKET ASSY | Mouser 538-105028-1001
15 | 1 | U1 | CP2102N-A02-GQFN24R | Silicon Laboratories | SMD/QFN24 | USB Interface IC USBXpress - USB to UART Bridge | Mouser 634-CP2102NA02QFN24R
16 | 1 | U2 | TLV62568DBVR | Texas Instruments | SMD/SOT23-5 | Switching Voltage Regulators | Mouser 595-TLV62568DBVR
17 | 1 | U3 | TLV75530PDBVR | Texas Instruments | SMD/SOT23-5 | LDO Voltage Regulators 500-mA low-IQ small-size low-dropout (LDO) regulator | Mouser 595-TLV75530PDBVR | May substitute equal or better
18 | 1 | U4 | MIC5365-2.8YD5-TR | Microchip | SMD/SOT23-5 | LDO Voltage Regulators Ultra Small Single 150mA LDO | Mouser 998-MIC5365-2.8YD5TR | May substitute equal or better
19 | 1 | U5 | MIC5365-1.2YD5-TR | Microchip | SMD/SOT23-5 | LDO Voltage Regulators Ultra Small Single 150mA LDO | Mouser 998-MIC5365-1.2YD5TR | May substitute equal or better
20 | 1 | U6 | DSC1001CI1-025.0000 | Microchip | SMD/3225 | Standard Clock Oscillators 3225 pkg -40-85C 50ppm 025.0000MHz | Mouser 998-1001CI1-025.0000 | May substitute equal or better
21 | 1 | PCB |  |  |  | 2-layer FR-4, 1.6mm, 1 oz copper, ENIG finish, Black solder mask, White Silkscreen (rev 4) |  | Panelization at discretion of CM
22 | 1 |  | 500-0771-01 | Flir |  | Thermal Image Sensor 160Hx120V | Group Gets Lepton 3.5 or DigiKey 500-0771-01-ND | Installed in S1 after PCB Assy

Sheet: tCam-Mini - Rev 04 - Bot PCB As
tCam-Mini PCB Assembly - Bottom Side - Rev 04
Line No | Qty | Ref Desg | Part Number | Manuf | Package/Type | Desc | Distributor Part Number | Notes
1 | 1 | M1 | ESP32-WROVER-E(M213EH6464PH3Q0) | Espressif | SMD | WiFi Modules (802.11) SMD Module ESP32-WROVER-E, ESP32-D0WD-V3, 3.3V 64Mbit PSRAM, 8 MB SPI flash, PCB Antenna | Mouser 356-ESP32WRVE26464PC | Use this part if you desire a built-in antenna
2 | 1 | M1 | ESP32-WROVER-IE(M213EH6464UH3Q0) | Espressif | SMD | WiFi Modules (802.11) SMD Module ESP32-WROVER-IE, ESP32-D0WD-V3, 3.3V 64Mbit PSRAM, 8 MB SPI flash, IPEX connector | Mouser 356-ESP32WRVIE6464UC | Use this part if you desire an external antenna
3 | 1 |  | 080-0001 | Laird Connectivity | Cable | RF Cable assembly U.FL to RP-SMA Bulkhead cable 105 mm | Mouser 741-080-0001 | User this part if you desire an external antenna
4 | 1 |  | RN-SMA-S-RP | Microchip | Antenna | Antenna 2.4 GHz 1” Stubby Rev Pol SMA | Mouser 765-RN-SMA-S-RP | Use this part if you desire an external antenna

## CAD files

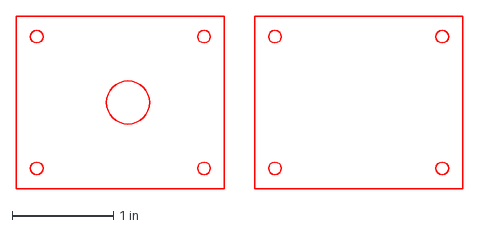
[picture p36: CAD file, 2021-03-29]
ESP32/tCam-Mini/enclosure/laser/tcam_mini_cutout.dxf
4.40 x 1.70 in

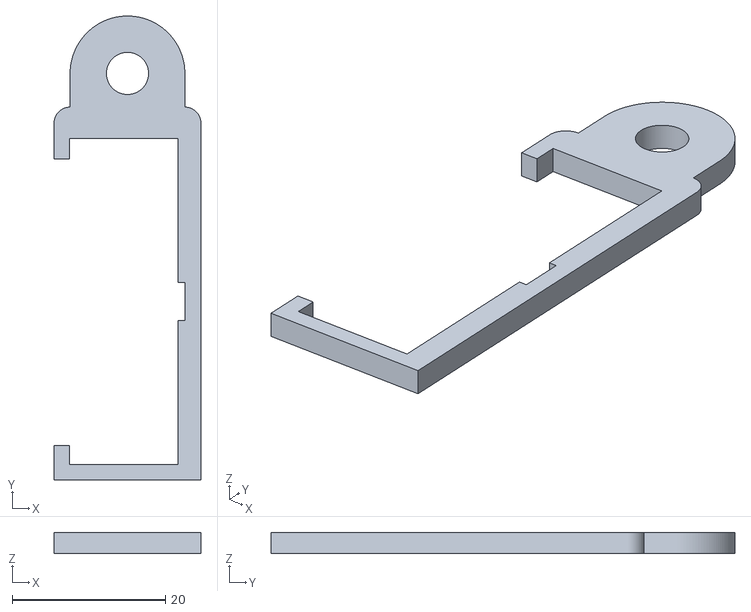
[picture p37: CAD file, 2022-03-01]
ESP32/tCam-Mini/enclosure/tcam_mini_basic/tcam_mini_basic/tcam_mini_gp_mount_v.stl
19.2 x 60.6 x 2.75

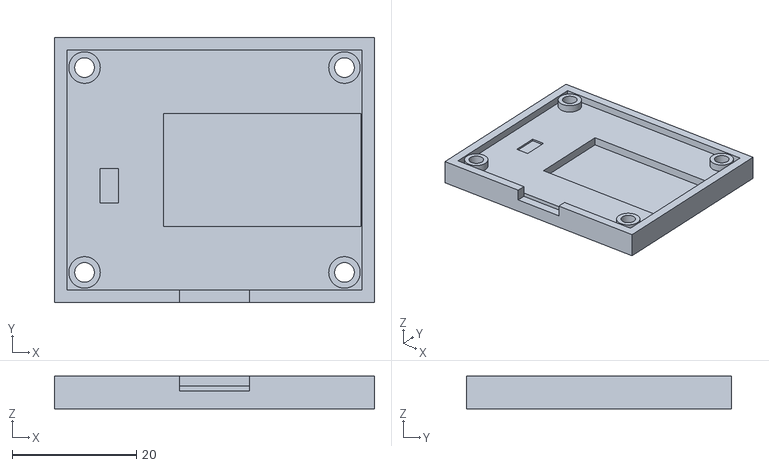
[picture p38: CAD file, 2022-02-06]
ESP32/tCam-Mini/enclosure/zeke_gustafson/Enclosure Back.stl
51.6 x 42.7 x 5.30

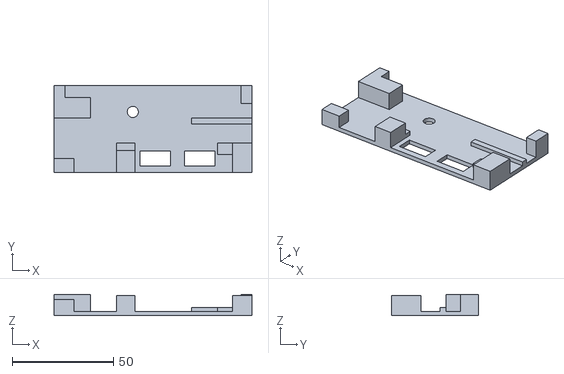
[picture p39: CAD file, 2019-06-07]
pocketbeagle/enclosure/top.stl
98.0 x 43.1 x 10.5

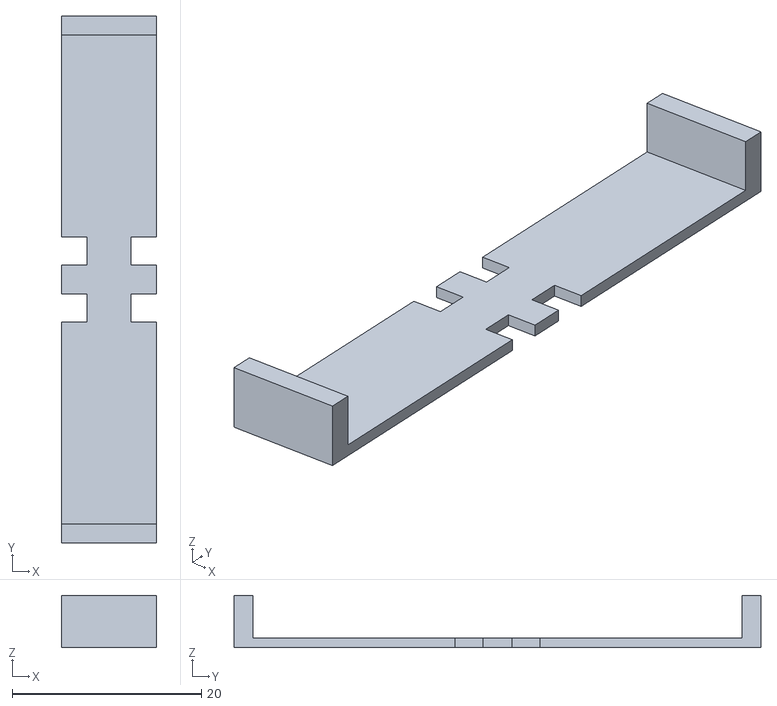
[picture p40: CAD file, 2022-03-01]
ESP32/tCam-Mini/enclosure/tcam_mini_basic/tcam_mini_basic/tcam_mini_gp_mount_h.stl
10.0 x 55.7 x 5.50

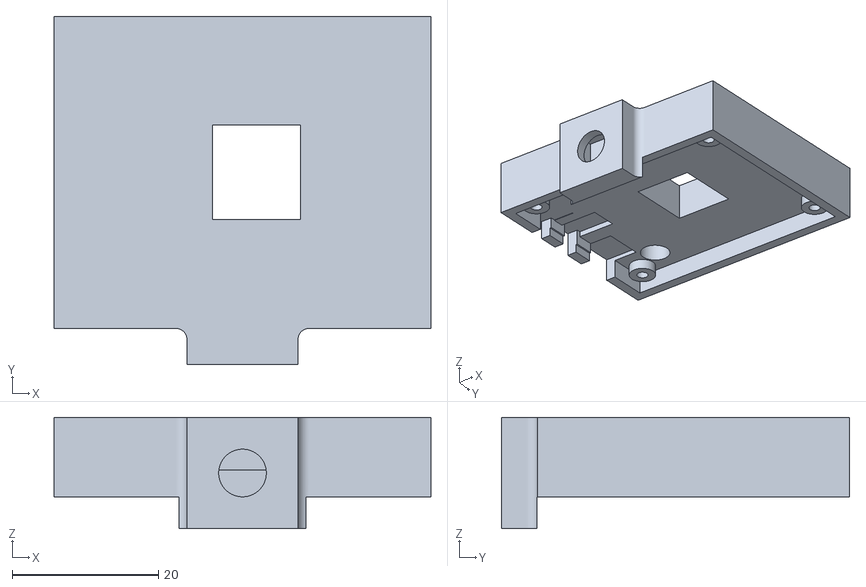
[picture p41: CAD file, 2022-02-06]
ESP32/tCam-Mini/enclosure/zeke_gustafson/Enclosure Front.stl
51.6 x 47.7 x 15.2

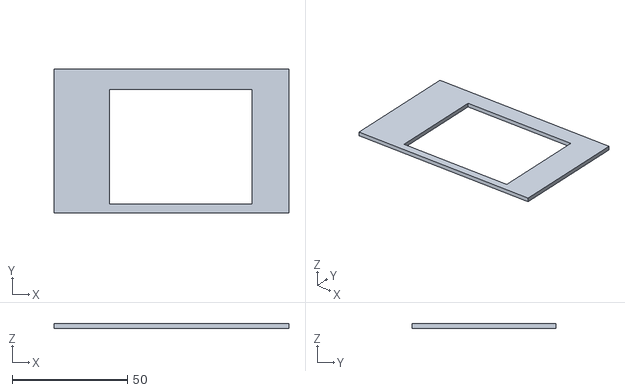
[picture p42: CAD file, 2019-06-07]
pocketbeagle/enclosure/front2.stl
102.0 x 62.5 x 2.00

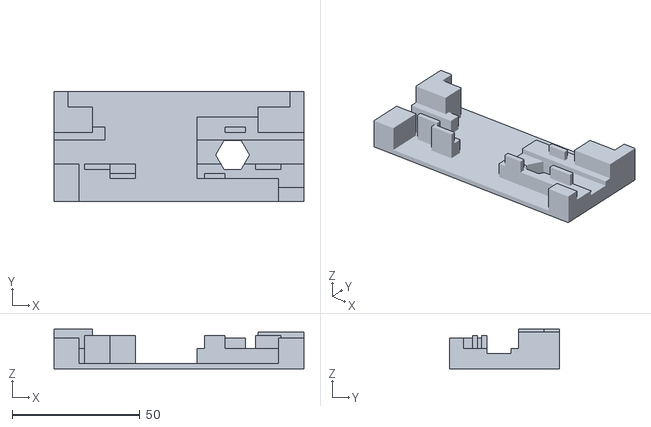
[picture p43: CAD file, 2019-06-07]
pocketbeagle/enclosure/base.stl
98.0 x 43.1 x 15.5

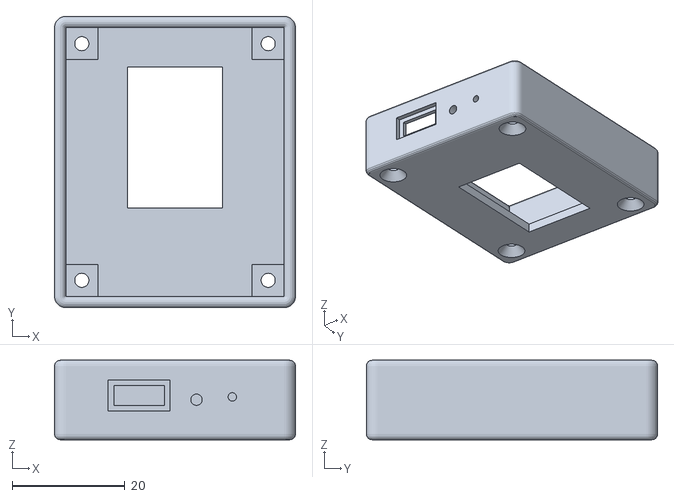
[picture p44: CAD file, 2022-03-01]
ESP32/tCam-Mini/enclosure/tcam_mini_basic/tcam_mini_basic/tcam_mini_rev4_encl.stl
42.7 x 51.6 x 14.1

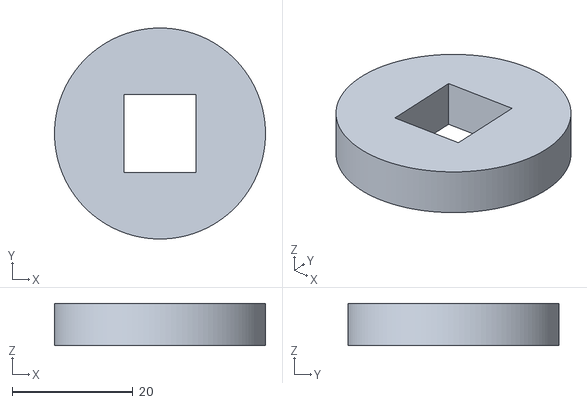
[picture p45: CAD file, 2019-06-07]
pocketbeagle/enclosure/rear_lens.stl
35.0 x 35.0 x 7.00

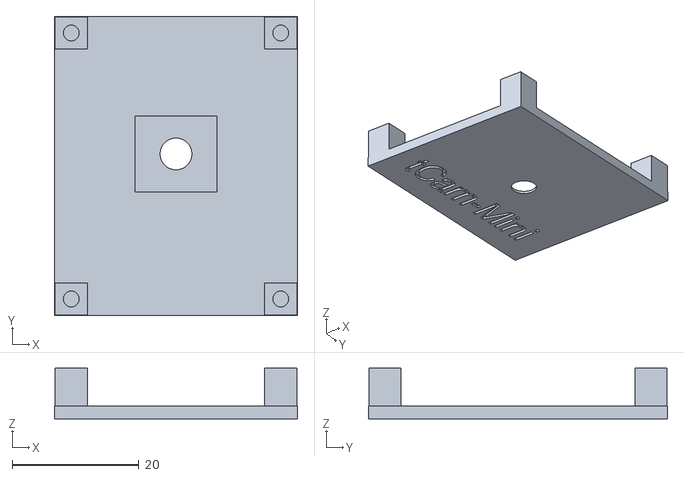
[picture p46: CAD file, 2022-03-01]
ESP32/tCam-Mini/enclosure/tcam_mini_basic/tcam_mini_basic/tcam_mini_bezel.stl
38.3 x 47.2 x 8.00

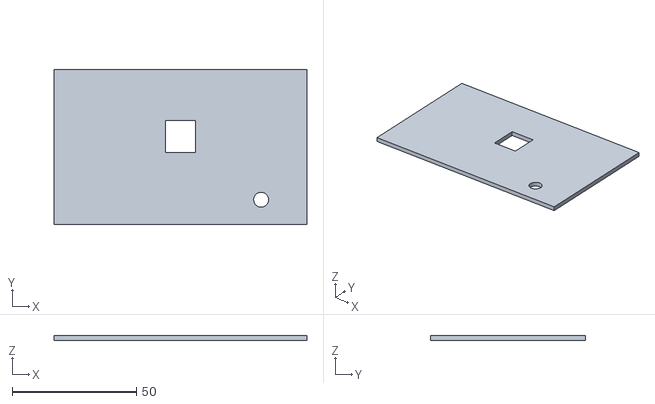
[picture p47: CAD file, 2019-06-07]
pocketbeagle/enclosure/rear_smooth.stl
102.0 x 62.5 x 2.00

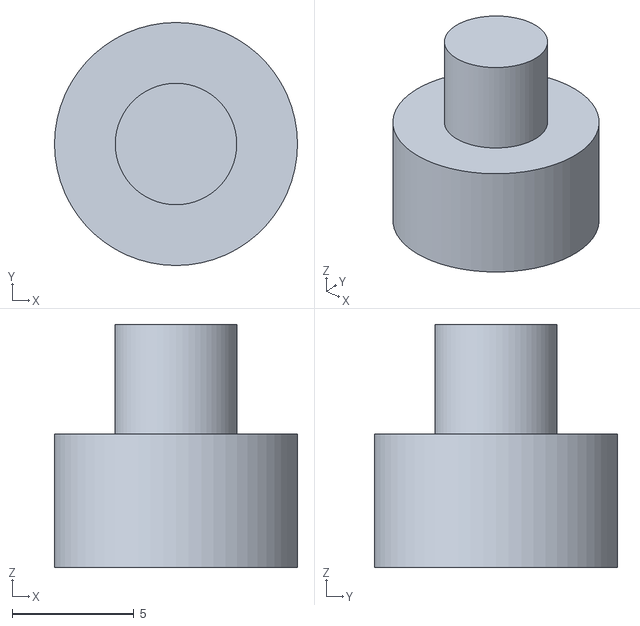
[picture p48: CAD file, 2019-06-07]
pocketbeagle/enclosure/button.stl
10.0 x 10.0 x 10.0

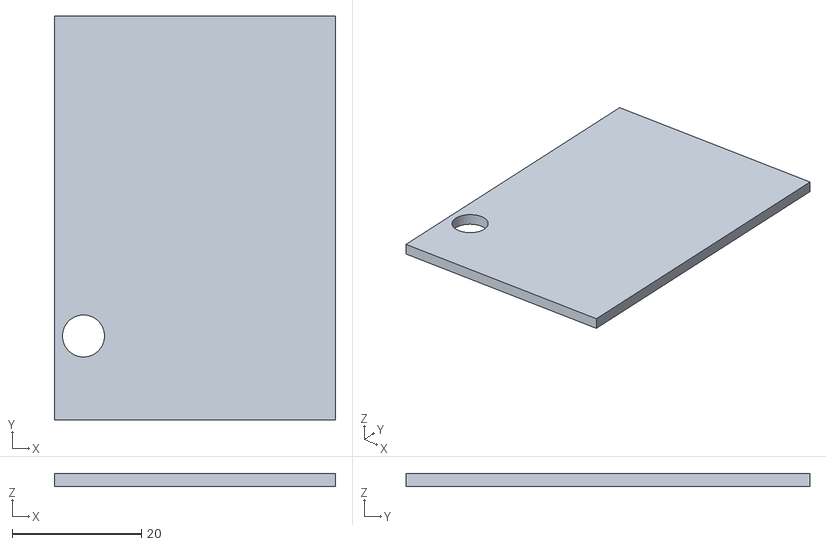
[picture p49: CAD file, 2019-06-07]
pocketbeagle/enclosure/side1.stl
43.5 x 62.5 x 2.00

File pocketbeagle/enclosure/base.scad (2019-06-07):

// Thermal imaging camera bottom plate
//
// View from front - (0, 0, 0) = front, left, bottom
//

//
// Main parts of plate
//
module base_parts() {
  union() {
    // Bottom plate
    cube([98, 43.1, 2]);

    //
    // Pi Platter section -> front
    //
    translate([0, 0, 0]) {
      cube([9.75, 14.6, 12]);  // Left mount
    }
    translate([22, 9, 0]) {
      cube([10, 5.6, 8]);      // Left PCB base
    }
    translate([56, 9, 0]) {
      cube([42, 5.6, 8]);      // Right PCB base
    }
    translate([12, 12.6, 0]) {
      cube([10, 2, 13]);       // Left PCB guide (rear of PCB)
    }
    translate([22, 9, 0]) {
      cube([10, 2, 13]);       // Middle Left PCB guide (front of PCB)
    }
    translate([59, 9, 0]) {
      cube([8, 2, 13]);        // Middle Right PCB guide (front of PCB)
    }
    translate([79, 12.6, 0]) {
      cube([10, 2, 13]);       // Right PCB guide (rear of PCB)
    }
    translate([88, 0, 0]) {
      cube([10, 5.5, 12]);     // Right mount
    }
    translate([88, 0, 0]) {
      cube([10, 9, 8]);        // Right mount extension
    }

    //
    // Battery section
    //
    translate([56, 14.6, 0]) {
      cube([42, 9.5, 6]);      // Battery base
    }

    //
    // Pocketbeagle section -> rear
    //
    translate([0, 27.1, 0]) {
      cube([15, 10, 15.5]);      // Left mount
    }
    translate([0, 24.1, 0]) {
      cube([20, 5, 8]);          // Left PCB base
    }
    translate([0, 37.1, 0]) {
      cube([5.5, 6, 15.5]);      // Left front mount
    }
    translate([56, 24.1, 0]) {
      cube([42, 9, 8]);          // Right PCB base
    }
    translate([67, 27.1, 0]) {
      cube([8, 2, 12]);          // Right PCB guide (front of PCB)
    }
    translate([80, 27.1, 0]) {
      cube([18, 10, 14.5]);      // Right mount
    }
    translate([92.5, 37.1, 0]) {
      cube([5.5, 6, 14.5]);
    }
  }
}

//
// Plate with subtraction for tripod-mount
//
difference() {
  base_parts();

  translate([70, 18.25, -1]) {
    cylinder(h=20, d=13.25, center=false, $fn=6);
  }
}

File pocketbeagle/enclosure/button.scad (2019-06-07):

//
// Thermal imaging camera power button
//
module additive_parts() {
  // Disk
  cylinder(h=5.5, d=10, center=false, $fn=60);

  // Stem
  cylinder(h=10, d=5, center=false, $fn=60);
}

difference() {
  additive_parts();

  // Cut-out for PCB button stem
  cylinder(h=2, d=4.5, center=false, $fn=30);
}

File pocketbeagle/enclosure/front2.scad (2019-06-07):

//
// Thermal imaging camera front (LCD Bezel)
//

difference() {
  // Bezel
  cube([102, 62.5, 2]);

  // LCD cut-out
  translate([24, 4, -1]) {
    cube([62, 49.5, 4]);
  }
}

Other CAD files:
pocketbeagle/enclosure/side2.stl
ESP32/tCam-Mini/enclosure/tcam_mini_basic/tcam_mini_basic/tcam_mini_rev2_encl.stl
pocketbeagle/enclosure/rear_lens.scad
ESP32/tCam-Mini/enclosure/tcam_mini_basic/openscad_libraries/smooth_prim.scad
ESP32/tCam-Mini/enclosure/tcam_mini_basic/openscad_libraries/tcam_mini.scad
ESP32/tCam-Mini/enclosure/tcam_mini_basic/tcam_mini_basic/tcam_mini_basic_encl.scad
ESP32/tCam-Mini/enclosure/tcam_mini_basic/tcam_mini_basic/tcam_mini_gp_mount.scad
ESP32/tCam-Mini/enclosure/zeke_gustafson/tCam-mini enclosure.f3d
pocketbeagle/enclosure/rear_smooth.scad
pocketbeagle/enclosure/side1.scad
pocketbeagle/enclosure/side2.scad
pocketbeagle/enclosure/top.scad

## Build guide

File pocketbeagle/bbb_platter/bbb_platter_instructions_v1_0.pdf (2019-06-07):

### Beaglebone version of Pi Platter Operating Instructions for Firmware 1.0, Board Rev 03 Ver 1/20/2019

Introduction
This firmware is a modified version of the firmware used for the original Pi Platter for use with the Beaglebone Black and Pocketbeagle computers. It provides most of the functions of the original Pi Platter and adds power management functionality to allow the Beaglebone to operate from a Li-Ion battery and charge the battery while the system is powered off.

The following functions were removed from the Pi Platter firmware to support the Beaglebone power management.
1. Analog Input 2
2. PWM Outputs
3. Watchdog timer

This document describes the functionality of the firmware. Additional information can be found in the github repository for the original Pi Platter (https://github.com/danjulio/rocketblue-automation/tree/master/pi_platter).

Assembly Notes for Pocketbeagle
1. Wire the Pi Platter board to the Pocketbeagle as shown in the diagram below. Note that one wire must be soldered to the anode of diode D2 on the Pi Platter. It is also possible to use the positive power line from a Micro-USB connector plugged into the Pi Platter Micro-USB power connector. This allows power to the system through the Micro-USB connector on the Pocketbeagle.
2. Attach the battery first then any other power source. The system may be powered by either the Pocketbeagle Micro-USB connector or the Pi Platter 5.5 x 2.1mm jack (5V power supply). Power connected the Pi Platter jack is routed through the charge circuit which limits current to both charging the battery and power the system to 750 mA.

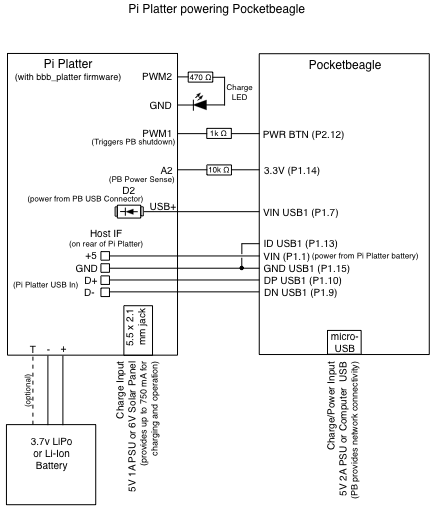
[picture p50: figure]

Hardware Notes

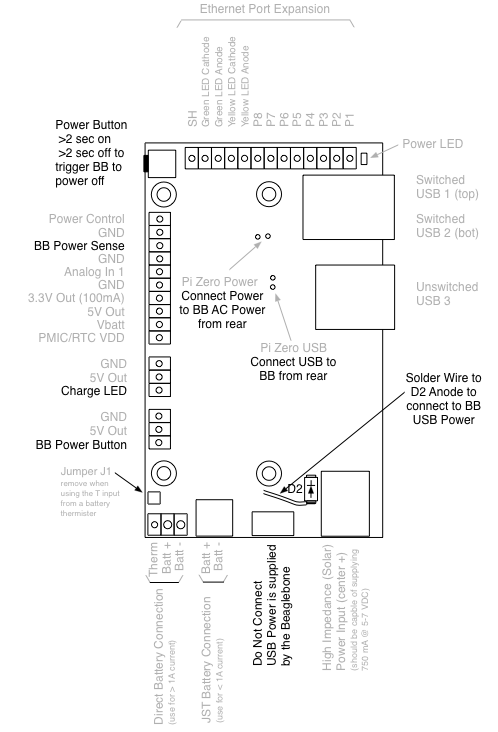
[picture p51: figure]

The Pi Platter and Beaglebone combination can be powered and battery charged using two sources.

The 5.5x2.1mm jack, CON1, routes power through the charging circuit. The Pi Platter boost converter is active to supply the 5V main rail that powers the Beaglebone through its VIN/AC Power. A 5V 1A supply should be used. The charge circuit can supply a maximum of 750 mA so any additional power will come from the battery. Best use of this connector is to charge the system or to power the system when it is not necessary to simultaneously charge the battery.

The Micro-USB connector on the Pocketbeagle routes power directly to the system as well as charges the battery. Power to the Beaglebone is supplied through the Beaglebone’s built-in PMIC. Power to the Pi Platter is supplied via the USB bypass circuitry. A 5.1V 2A supply should be used to supply both system power and charge current.

The Pi Platter will manage switching to battery power as necessary. Its power button is used to power-on the system by pressing it for more than two seconds. When the system is powered on, pressing it again for more than two seconds will cause the Pi Platter to simulate a Beaglebone power button press to initiate a controlled system shutdown. The Pi Platter waits until the

Beaglebone shuts down as indicated by the 3.3V output from its PMIC switching off and then it switches off. In the case where the Beaglebone does not successfully power down, the Pi Platter will shut down all power in 30 seconds.

A single-cell, 3.7V, Li-Ion battery must be connected to either CON3 with a JST connector (compatible with batteries from both Sparkfun and Adafruit) or directly wired to CON4. The Pi Platter is designed for Li-Ion batteries with capacities between about 1000 mAh to 5000 mAh. Sparkfun claims that their batteries using the JST connector shouldn’t have a load current in excess of 1A so CON4 should be used for systems that will have a higher load current as described below. CON4 also provides a connection for an external 103AT-4 thermistor that can be attached to the battery to limit battery charging in extreme temperature situations. Remove J2 to use an external thermistor.

USB Connector CON 5 is identified as USB devices 2 and 3. Power to these two USB devices may be switched on and off (on by default). USB Connector CON7 is identified as USB device 1. There is a 1A current limit imposed by the USB power switch for CON5. CON6 has no current limiting. Over-current may cause the boost converter to shut down when running on batteries or the USB power source to current limit.

The PWM 1 port is wired to the Beaglebone power button and is driven low to simulate a button press. The PWM 2 port may be connected to an external LED (with current limiting resistor) to indicate battery charging. The PWM ports are no longer available as general purpose PWM outputs.

Analog input A1 operates as an analog input converted to a value with a configurable voltage reference. The voltage reference may be set to one of three fixed, precision, values (1.024, 2.048, 4.096 volts) for making absolute measurements or it may be set to the PMIC/RTC power supply rail (VD) for making relative measurements. Input voltages on A1 should never exceed VD or damage to the PMIC/RTC may occur.

The A2 port is used to sense the Beaglebone 3.3V output through a 10 k-ohm resistor. It is no longer available as general purpose analog input.

The PC (“Power Control”) expansion in port is connected in parallel to the power button. External circuitry (e.g. a relay or N-Channel MOSFET) can pull this signal low to simulate a button press. Assert the signal low for more than 2 seconds to power on the board. Assert the signal low for more than 6 seconds to power off the board.

The VD, VB, 5 and 3.3 expansion connections provide access to the various power rails in the system. VD is the PMIC/RTC VCC signal and might be useful as the reference voltage for devices using the Analog inputs and setting Vref to VCC. VB is the battery voltage. Current should be limited to 500 mA. 5 is the 5V output. 3.3 is a 3.3V output (that is shared with the USB and Ethernet subsystem). Output current on the 5V line is limited to a system total of 2A. Output current on the 3.3V line is limited to 100 mA.

G expansion connections are connected to ground. There are several to simplify connecting to various external devices.

The ethernet expansion port is designed for use with the Sparkfun BOB-13021 RJ45 MagJack breakout board (Adafruit has no similar product).

Default Configuration
- Low Battery Threshold (configurable): 3.6V
- Critical Battery Threshold (configurable): 3.1V
- Battery Start Under-voltage threshold: 3.2V
- Battery Restart voltage threshold: 3.8V
- Battery Critical detection to turn-off: 30 seconds
- Low Battery Warning Enabled
- Critical Battery Warning Enabled
- Battery Restart Disabled
- USB Fault Warning Enabled
- Power on USB Port 2: Enabled
- Power on USB Port 3: Enabled
- Analog 1 Reference: PMIC/RTC VCC (VD)

Operational Notes
The Pi Platter starts up in sleep mode when power is first applied and the real-time clock initialized to 0 seconds. Press the button for 2 seconds to turn power on.

The Pi Platter will not turn power on while the battery voltage is less than the Battery Start Under-voltage Threshold.

Power can be turned on when the board is sleeping by the RTC. The RTC is simply a 32-bit second counter and can be associated with any time keeping scenario the user wants. It supports a single 32-bit Wakeup Time that can be enabled and is triggered when the RTC matches the Wakeup Time and the board is sleeping. There is also a 32-bit Wakeup Repeat time that is added to Wakeup Time every time an Wakeup condition is detected (Wakeup Time matches RTC and is enabled). This makes it possible to create a simple system that turns on the Pi periodically with software on the Pi turning the system off after it has completed its functions. The RTC runs as long the battery is connected.

Power can also be turned on when the battery voltage is charged above the Battery Restart Threshold. This value is stored in EEPROM (default 3.8 volts) and can be automatically enabled every time the Pi is powered by the EEPROM Battery Restart Enable or selectively for the next charge cycle by the Restart Enable Control register. This functionality is disabled by default.

By default all three USB connectors are enabled when the board is turned on. This is to allow the user to connect a keyboard/ mouse in order to do initial configuration of their system. They can reconfigure the Pi Platter so that either of the USB ports on CON5 are disabled when the board turns on for power savings.

The Pi Platter shows up as an ACM serial port on the Beaglebone. Depending if any other ACM serial devices are connected to one of the USB ports, it will show up as /dev/ttyACM0 (or /dev/ttyACM1 if there is a USB ACM device, etc). The PMIC/RTC micro-controller is connected to USB port 4 on the board’s hub so will enumerate after other USB ACM devices. The baud rate does not matter since it is a USB ACM device.

Warnings are enabled by default. They are simple text strings with the form “WARN <N><CR><LF>” where <N> is a number identifying the warning type, <CR> is the carriage return character, and <LF> is the linefeed character. A serial connection must be open in order to receive any warning messages. Individual warning messages may be disabled.

- “WARN 0”: Low Battery Warning Message
- “WARN 1”: Critical Battery Warning Message
- “WARN 2”: USB Fault Detected Message

Voltage levels must persist at Low or Critical levels for at least 5 seconds before a warning is issued.

Power will turned-off a programmable time after the critical battery voltage level is detected. Power cannot be switched back on, either by the power button or a RTC Wakeup if the battery voltage is less than or equal to the Start-up under-voltage. The Wakeup Repeat interval is added to the Wakeup Time so that the board has a chance to power up at the next Wakeup Time if the battery has been sufficiently charged before then.

Command Interface
Commands are simple ASCII sequences with two forms terminated by a Carriage Return character (<CR>), shown below, sent to or received from the Pi Platter’s ACM Serial interface (using the “screen” utility, for example). The first form is used to set a value. The second form is used to query a value. Each command is a single upper-case ASCII character, <CMD>, that is selected to mnemonically represent its function. A command may be followed by a optional numeric index, <INDEX>, required when it applies to more than one item (for example, USB port or Analog input). Values, <VALUE>, to be set are numeric values.
1. Form 1 (Set): <CMD>[<INDEX>]=<VALUE><CR>
2. Form 2 (Query): <CMD>[<INDEX>]<CR>

All parameters, <INDEX> or <VALUE>, are base-10 numeric values. All other characters besides the <CMD> character, numbers “0”-“9”, the “=“ character and the Carriage Return character are ignored. Illegal or malformed commands cause the Pi Platter to respond with an error message with the form “ERR <N><CR><LF>” where <N> is a number identifying the type of error.

- “ERR 0”: Unknown Command (The command character, <CMD>, did not match any of the supported commands).
- “ERR 1”: Illegal Index value (The index value, <INDEX>, did not apply or was out of range)
- “ERR 2”: Command does not support Form 1 (Set). It is a Query-only item.

The Pi Platter does not echo back commands. It only generates responses to Queries, warning messages or command error messages. You can enable local echo if you are using a terminal emulator program. The Pi Platter command processor looks at the last characters before a <CR> entered to process commands. This means you can correct commands by just typing what you really meant before hitting <CR>. The Pi Platter also appends a Line Feed, <LF>, character to messages it sends to make them easier to see in a terminal emulator. It ignores <LF> characters sent to it.

Commands are grouped into several categories.

1. Power Management - Monitor battery voltage, Set/Query the USB Port power, initiate a power-down timeout.
2. Real Time Clock - Set/Query the RTC, Wakeup Time and Wakeup Repeat Time.
3. User Peripherals - Query Analog Voltage readings.
4. Control and Status - Set/Query operational control registers, Query the system Status.
5. System Configuration - Set/Query configuration values that are stored in EEPROM and are used to configure operation each time the board is powered up.

Power Management

Battery Voltage - “B” - Supports the Query form only. Returns the current battery voltage in volts with 10 mV resolution.

B<CR> - Returns the battery voltage (B=<VOLTS><CR><LF> - for example “B=4.05”)

Power Off - “O” - Supports both forms. Set initiates a power-down in the specified number of seconds. Query returns the number of seconds until power is turned off. A value of 0 means the power down timer is not operating. The time value may range from 1-255 seconds.

O=30<CR> - Sets a 30 second timeout until power down
O<CR> - Returns the number of seconds until power down (O=<NUM><CR><LF>)

USB Port Power Enable - “U” - Supports both forms. Set allows turning on or off an individual, indexed, USB port. Query returns the current power status of the indexed USB port. The index value may range from 1 - 2 for USB Ports 2 and 3. The power control value is 0 to turn a port off and 1 to turn a port on.

U1=1<CR> - Turns USB Port 2 on
U2=0<CR> - Turns USB Port 3 off
U1<CR> - Returns the power control state for USB Port 2 (U1=<N><CR><LF> where <N> is 1 or 2)

Real Time Clock

Current Time - “T” - Supports both forms. Set allows setting the current RTC second count (32-bit unsigned number). Query returns the current RTC second count.

T=1000<CR> | - Sets the RTC to 1000 seconds
T<CR> | - Returns the current RTC value (T=<SECONDS><CR><LF>)

Wakeup Time - “W” - Supports both forms. Set allows setting the Wakeup Time (32-bit unsigned number). Query returns the current Wakeup Time. Note that Control Register Wakeup Enable (C0) must be set to 1 to enable wakeup to occur when the current time matches the wakeup time and the device is powered down.

W=1100<CR> | - Sets the Wakeup Time to 1100 seconds
W<CR> | - Returns the current Wakeup Time (W=<SECONDS><CR><LF>)

Wakeup Repeat Time - “R” - Supports both forms. Set allows setting the Repeat Time (32-bit unsigned number). This is the value added to the Wakeup Time when the RTC second count equals the Wakeup Time and Wakeup Enable is set to 1 (it is added when the board is both sleeping and when it is powered up). Query returns the current Repeat Time. A value of 0 means do not modify the Wakeup Time. Control Register Wakeup Enable (C0) is not cleared if the Wakeup Repeat Time is non-zero and the Wakeup Time is updated whenever Current Time matches it.

R=86400<CR> | - Sets the Wakeup Repeat Time to 86400 seconds (1 day)
R<CR> | - Returns the current Wakeup Repeat Time (R=<SECONDS><CR><LF>)

User Peripherals

Analog Input - “A” - Supports the Query form only. Returns a 10-bit unsigned value from the indexed Analog Input. The number is referenced to the current Analog Channel reference setting. For example, if the Analog Channel reference is set to 1.024 volts then a 1.0 volt signal would return (1.0/1.024) * 1023 = 999. The index, <INDEX>, may only have the value 1.

A1<CR> - Returns the 10-bit unsigned value from Channel 1 (A1=<VALUE><CR><LF> where <VALUE> = 0 - 1023

Control and Status

Control Register - “C” - Supports both forms. Set allows setting an indexed control register to a value. Query returns the current value of an indexed control register. The index value selects a control register. The legal control register index values are shown below along with the legal values for each control register.

C0=1<CR> - Sets Control Register 0 to 1
C1<CR> - Returns the value of Control Register 1

The Pi Platter has the following control register index values. Default values may be set from EEPROM.

0 - Wakeup Enable: 1 = Wakeup Enable, 0 = Wakeup Disable. Cleared automatically when a wakeup occurs unless the Repeat Time is non-zero.
1 | - Low Battery Warning Enable: 1 = Enable Message, 0 = Disable message
2 | - Critical Battery Warning Enable: 1 = Enable Message, 0 = Disable message

3 | - USB Fault Warning Enable: 1 = Enable Message, 0 = Disable message
4 | - Analog 1 Reference: (see below for Analog reference values)
5 | - Unused
6 | - Unused
7 | - Restart Enable: 1 = Enable restart when battery voltage exceeds Battery Restart Threshold, 0 = Disable restart
8 | - Unused

Analog Reference Values

0 | - Analog Channel Vref = PMIC/RTC VCC (PMIC/RTC power input - voltage on expansion port VD connection)
1 | - Analog Channel Vref = 1.024 Volts
2 | - Analog Channel Vref = 2.048 Volts
3 | - Analog Channel Vref = 4.096 Volts

Status - “S” - Supports the Query form only. Returns an 8-bit mask containing various status information.

S<CR> - Returns the 8-bit status value.

The return value is a number 0 - 255 but can be broken down by converting to a hex value and looking at the following bit positions.

bit 7: USB Fault Detected: set when the USB Power Switch is indicating a USB Fault (over-current or short).
bit 6: Reserved, will return 0.
bit 5:4 Power Up Reason: (see below).
bit 3: Battery Charging: set if the Charger subsystem is supplying current to charge the battery and/or operate the system bit 2: USB Supplying Power: set when power is being supplied by an external USB power supply, clear when it is being supplied by the battery.
bit 1: Battery Critical: set when the battery voltage is below the Battery Critical threshold, clear when the battery voltage is above the Battery Critical threshold.
bit 0: Battery Low: set when the battery voltage is below the Battery Low threshold, clear when the battery voltage is above the Battery Low threshold.

Power Up Reason (2-bits)
00: Alarm
01: Button
10: Battery Restart (battery charge exceeded Battery Restart Threshold to power-up the board) 11: USB Power Startup (the system booted because power was supplied to the USB input)

Version - “V” - Supports the Query form only. Returns the current board type and firmware revision as a 24-bit unsigned value (3 bytes). The lower byte (bits 7:0) contains the firmware minor number. The middle byte (bits 15:8) contains the firmware major number. The minor number is incremented for bug fixes and minor modifications to existing functionality. The major number is incremented for new functionality or user-visible modification of existing functionality. The minor number is the fractional value reported by the PMIC/RTC USB Version field. The major number is the integer value reported by the PMIC/RTC USB Version field.

The upper byte (bits 24:16) contain the board ID (which is 0x02 for the Beaglebone version of the Pi Platter).

V<CR> - Returns the version (V=<VERSION><CR><LF>, Version 1.0 returns “V=131328”)

System Configuration

EEPROM - “E” - Supports both forms. Set allows setting an indexed Configuration Value that is stored in the PMIC/RTC’s EEPROM memory that persists across power-cycles (including battery removal). Query returns the value of an indexed Configuration Value. Configuration Values are read each time the board is powered-up and are used to set the default operating conditions. Setting a Configuration Value does not take effect until the Pi Platter has powered down and then powered up the Pi Zero.

E9=0<CR> - Sets Configuration Index 9 (USB 1 Default Enable) to 0 (off).
E11<CR> - Returns the value of Index 11 (Analog 1 Default Reference)

The Configuration Value indexes are shown below along with their legal values.

0: | Battery Low Warn Threshold. A 16-bit unsigned integer (0-1023) that sets the Low Battery Threshold (see below).
1: | Battery Critical Threshold. A 16-bit unsigned integer (0-1023) that sets the Critical Battery Threshold (see below).
2: | Battery Start Under-voltage Threshold. A 16-bit unsigned integer (0-1023) that sets the under voltage Threshold.
3: | Battery Restart Threshold. A 16-bit unsigned integer (0-1023) that sets the restart voltage Threshold.

4: | Battery Critical to Turn-off Timeout. An 8-bit unsigned integer that sets the number of seconds (0-255).
5: | Battery Warn Message Enable. Set to 0 to disable Low Battery Warning Messages, 1 to enable.
6: | Battery Critical Message Enable. Set to 0 to disable Low Battery Warning Messages, 1 to enable.
7: | Battery Restart Enable. Set to 0 to disable setting the Battery Restart Enable when powering up, 1 to enable.
8: | USB Fault Message Enable. Set to 0 to disable Low Battery Warning Messages, 1 to enable.
9: | USB Port 2 Default Power Enable. Set to 0 to disable power to USB Port 2 on power-up, 1 to enable.
10: | USB Port 3 Default Power Enable. Set to 0 to disable power to USB Port 3 on power-up, 1 to enable.
11: | Analog 1 Default Reference. One of the 4 Analog Reference Values for Analog 1 (0 - 3).

Low and Critical Battery Threshold Calculations
The Low and Critical battery threshold configuration values may be calculated as follows. They are the ADC count threshold based on the Pi Platter battery sense circuitry and a Vref of 1.024 volts. Vthresh is the voltage level expressed in volts (e.g. 3.6).

Threshold (0-1023) = ((Vthresh * 0.2362)/1.024) * 1023

Note that the Pi Platter has been preset with reasonable values for Li-Ion batteries. These values should only be changed for specific reasons.

Start Under-voltage and Restart Threshold Calculations
The Start Under-voltage and Restart threshold configuration values may be calculated as follows. They are the ADC count threshold based on measuring a 1.024 volt reference against the PIC VDD power (through a diode with an estimated 0.15 volt Vf drop) when powered by the battery. Vthresh is the voltage level expressed in volts (e.g. 3.2).

Threshold (0-1023) = (1.024 / (Vthresh - 0.15)) * 1023

Special Note for EEPROM access
The PMIC/RTC EEPROM has a limited number of write cycles. Depending on the type of Configuration Value Index being written, the memory will only support a few tens-of-thousands of updates. While this should be sufficient for the purpose it was intended (making a custom system configuration) software should not make changes to the System Configuration unless absolutely necessary (do not treat EEPROM like a RAM variable).

Battery Restart Operation
The Battery Restart mechanism allows the board to automatically power-on the Pi when the battery is charged to a configurable voltage (Battery Restart Threshold). This functionality is disabled by default and may be enabled in one of two ways. The Battery Restart Enable EEPROM configuration entry can set the enable every time the Pi is powered. This may be useful in an application that should run whenever there is sufficient power in the battery and software running on the Pi does not have to do anything (other than execute an orderly shutdown if required to prevent SD card corruption).

If the Battery Restart Enable configuration entry is clear then system software running on the Pi can set the Restart Enable Control register to 1 to enable a restart on the next power down only. In this case the Restart Enable will be disabled on the next power up and the Pi must, again, enable it for the power cycle. This allows the Pi set setup a special condition if necessary.

The Battery Restart mechanism is only applied when power is shut down. It is checked once per second when the RTC is updated while the board is sleeping.

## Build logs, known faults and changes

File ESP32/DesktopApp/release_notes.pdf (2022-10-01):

tcam Desktop Application
Release Notes

Version 3.1.0
1. Support 63 character WiFi passwords with all tCam firmware and tCam-Mini firmware 3.1 and beyond
2. Disabled Graph when connected to a camera with a Lepton 3.0
3. Display “RAW” and “AGC” in color palette bar when connected to a camera with a Lepton 3.0
4. Worked around Xojo bug where pull-down menus didn't work properly in Linux builds (starting with version 3.0.0)

Version 3.0.0
1. New IsoTherm palette
2. Added ability to change palettes by clicking the top or bottom of the color bar
3. Added support to identify new Ethernet camera model
4. Added Camera Info window (opened by new Camera->Camera Info... menu item)
5. Application no longer displays firmware version of connected camera in main window
6. Added new Discover function for bonjour discovery of cameras from Preferences Window
7. Wifi/Network Settings tab understands Ethernet camera model and disables irrelevent controls
8. Added Help window accessed through Application->Documentation menu
9. Added ability to check for updated application automatically at startup or from Application Menu
10. Added ability to check for new tcam/tCamMini firmware versions from Camera Menu based on connected camera type
11. Enabled close button on About window
12. Main Window toolbar connect button toggles between "Connect" and "Disconnect" captions
13. Improved error message when application can't connect to camera
14. Internal changes with window management in preparation for multi-camera sessions
15. Signed Mac version with Apple developer ID

Version 2.1.1
1. Fixed, yet again, AGC display of spot meter information…*sigh*

Version 2.1.0
1. Optimize compilation and add preference item to disable bilinear interpolation if desired to increase performance on slow computers and when the image has been resized. This fixes the issue where the UI seemed frozen while streaming.
2. Add check for minimum 8-character password when setting Wifi.
3. Fix bug where spot meter info is displayed when AGC enabled on a camera with a Lepton 3.5.
4. Fixed bugs in displaying garbage metadata when exporting images from a camera with a Lepton 3.0.
5. Fixed bug where application could crash when exporting an image to a protected directory.
6. Increased the width of some labels to display fully on Linux.

Version 2.0.0
1. Added support for Lepton 3.0 (non-radiometric) in tCam-Mini
2. Resized display window to 480x320 pixels and allow resizing main window
3. Added support for Over-the-air firmware updates for tCam-Mini (FW 2.0) and tCam
4. Modified Log Window to be able to shorten any long json packet (instead of just images)
5. Added Banded, Black Hot and Sepia color palettes
6. Improved accuracy of FPS display (now based on image timestamp data)
7. Misc bug fixes

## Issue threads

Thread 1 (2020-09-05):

Troubles in teensy3 code

Konan23, 2020-09-05:
Hi @danjulio ,

I have some troubles in your teensy3 code. I tried to verify lep_test5 and had errors
`lep_test5:265: error: 'IRQ_PORTA' was not declared in this scope
   SPI.notUsingInterrupt(IRQ_PORTA);
`
`controls:85: error: 'INTERNAL' was not declared in this scope
   analogReference(INTERNAL);
`
I couldn't find IRQ_PORTA and INTERNAL variables was declared or have instruction about them. Could you solve it pls. Thank you!

danjulio, 2020-09-05:
Hello @Konan23 ,

INTERNAL and IRQ_PORTA are part of the PJRC Teensy addition to the Arduino environment.  Have you included support for the Teensy in your Arduino application?  And have you selected "Teensy 3.2/3.1" as your board type?

Konan23, 2020-09-09:
Thanks for your reply and after trying to fix something, I still have error about multiple definition. I searched that error come from the overlap between 2 library i2c_t3 and Wire. I tried to deactivate Wire library in source code and header file but it doesn't work. Here is my error message

> Arduino: 1.8.13 (Windows 10), TD: 1.53, Board: "Teensy 3.2 / 3.1, Serial, 96 MHz (overclock), Faster, US English"
C:\Users\alta\AppData\Local\Temp\arduino_build_572620\libraries\Wire\WireKinetis.cpp.o: In function 'i2c0_isr':

> C:\Program Files (x86)\arduino-1.8.13\hardware\teensy\avr\libraries\Wire/WireKinetis.cpp:912: multiple definition of 'i2c0_isr'

> C:\Users\alta\AppData\Local\Temp\arduino_build_572620\libraries\i2c_t3\i2c_t3.cpp.o:C:\Program Files (x86)\arduino-1.8.13\hardware\teensy\avr\libraries\i2c_t3/i2c_t3.cpp:1134: first defined here

> c:/program files (x86)/arduino-1.8.13/hardware/tools/arm/bin/../lib/gcc/arm-none-eabi/5.4.1/../../../../arm-none-eabi/bin/ld.exe: Disabling relaxation: it will not work with multiple definitions

> C:\Users\alta\AppData\Local\Temp\arduino_build_572620\libraries\Wire\WireKinetis.cpp.o: In function 'Print::availableForWrite()':

> C:\Program` Files (x86)\arduino-1.8.13\hardware\teensy\avr\libraries\Wire/WireKinetis.h:136: multiple definition of 'i2c1_isr'

> C:\Users\alta\AppData\Local\Temp\arduino_build_572620\libraries\i2c_t3\i2c_t3.cpp.o:C:\Program Files (x86)\arduino-1.8.13\hardware\teensy\avr\libraries\i2c_t3/i2c_t3.h:883: first defined here

> C:\Users\alta\AppData\Local\Temp\arduino_build_572620\libraries\Wire\WireKinetis.cpp.o: In function 'Print::availableForWrite()':

> C:\Program Files (x86)\arduino-1.8.13\hardware\teensy\avr\libraries\Wire/WireKinetis.h:136: multiple definition of 'Wire1'

> C:\Users\alta\AppData\Local\Temp\arduino_build_572620\libraries\i2c_t3\i2c_t3.cpp.o:C:\Program Files (x86)\arduino-1.8.13\hardware\teensy\avr\libraries\i2c_t3/i2c_t3.h:883: first defined here

> c:/program files (x86)/arduino-1.8.13/hardware/tools/arm/bin/../lib/gcc/arm-none-eabi/5.4.1/../../../../arm-none-eabi/bin/ld.exe: Warning: size of symbol 'Wire1' changed from 20 in

> C:\Users\alta\AppData\Local\Temp\arduino_build_572620\libraries\i2c_t3\i2c_t3.cpp.o to 108 in C:\Users\alta\AppData\Local\Temp\arduino_build_572620\libraries\Wire\WireKinetis.cpp.o

> C:\Users\alta\AppData\Local\Temp\arduino_build_572620\libraries\Wire\WireKinetis.cpp.o: In function 'Print::availableForWrite()':

> C:\Program Files (x86)\arduino-1.8.13\hardware\teensy\avr\libraries\Wire/WireKinetis.h:136: multiple definition of 'Wire'

> C:\Users\alta\AppData\Local\Temp\arduino_build_572620\libraries\i2c_t3\i2c_t3.cpp.o:C:\Program Files (x86)\arduino-1.8.13\hardware\teensy\avr\libraries\i2c_t3/i2c_t3.h:883: first defined here

> c:/program files (x86)/arduino-1.8.13/hardware/tools/arm/bin/../lib/gcc/arm-none-eabi/5.4.1/../../../../arm-none-eabi/bin/ld.exe: Warning: size of symbol 'Wire' changed from 20 in

> C:\Users\alta\AppData\Local\Temp\arduino_build_572620\libraries\i2c_t3\i2c_t3.cpp.o to 108 in

> C:\Users\alta\AppData\Local\Temp\arduino_build_572620\libraries\Wire\WireKinetis.cpp.o

> collect2.exe: error: ld returned 1 exit status

> Error compiling for board Teensy 3.2 / 3.1.

Could you give me some advice to fix them. Thank you so much!

danjulio, 2020-09-11:
I'm sorry, I'm not sure I have much to offer you.  My LeptonSDKEmb32OEM.cpp file includes i2c_t3.  Maybe something else is including either i2c_t3 or wire and there is a collision.  All I can suggest is to look at every file and see if you can find a way multiple files are being included.

Konan23, 2020-09-12:
Thank you for your help. I will try some cases and hope that it will work. I will give you feedback when I completed it.

Konan23, 2020-09-17:
Finally, I debugged it successfully. The new version of Adafruit_GFX_Library contains Adafruit_GrayOLED file and it uses Wire.h to communication so when I compile the code, the program will call it too. Just delete the header and source files of Adafruit_GrayOLED, the program will run.

@danjulio you can close this issue :)))

danjulio, 2020-09-17:
Glad to hear you fixed it!

Closed 2020-09-17.

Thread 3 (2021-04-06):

idf.build error

JungSuWhan, 2021-04-06:
Hello Thank you for sharing a great project.

I ran a build with the idf.build command, but I got a compile error, so I'm inquiring.

../components/cmd/json_utilities.h:36:10: fatal error: ds3232.h: No such file or directory
 #include "ds3232.h"
          ^~~~~~~~~~
compilation terminated.
[7/24] cd /home/jsh/working/lepton/ESP32/tCam-Mini/firmware/build/esp-idf/part...*****************************************************************************
Partition table binary generated. Contents:
*******************************************************************************
# Espressif ESP32 Partition Table
# Name, Type, SubType, Offset, Size, Flags
nvs,data,nvs,0x9000,24K,
phy_init,data,phy,0xf000,4K,
factory,app,factory,0x10000,1M,
*******************************************************************************
[7/24] Building C object esp-idf/lepton/CMakeFiles/__idf_lepton.dir/cci.c.obj
FAILED: /root/.espressif/tools/xtensa-esp32-elf/esp-2020r3-8.4.0/xtensa-esp32-elf/bin/xtensa-esp32-elf-gcc  -Iconfig -I../components/lepton -I../main -I/root/esp/esp-idf/components/newlib/platform_include -I/root/esp/esp-idf/components/freertos/include -I/root/esp/esp-idf/components/heap/include -I/root/esp/esp-idf/components/log/include -I/root/esp/esp-idf/components/soc/esp32/include -I/root/esp/esp-idf/components/soc/include -I/root/esp/esp-idf/components/esp_rom/include -I/root/esp/esp-idf/components/esp_common/include -I/root/esp/esp-idf/components/xtensa/include -I/root/esp/esp-idf/components/xtensa/esp32/include -I/root/esp/esp-idf/components/esp32/include -I/root/esp/esp-idf/components/driver/include -I/root/esp/esp-idf/components/esp_ringbuf/include -I/root/esp/esp-idf/components/esp_event/include -I/root/esp/esp-idf/components/tcpip_adapter/include -I/root/esp/esp-idf/components/lwip/include/apps -I/root/esp/esp-idf/components/lwip/include/apps/sntp -I/root/esp/esp-idf/components/lwip/lwip/src/include -I/root/esp/esp-idf/components/lwip/port/esp32/include -I/root/esp/esp-idf/components/lwip/port/esp32/include/arch -I/root/esp/esp-idf/components/vfs/include -I/root/esp/esp-idf/components/esp_wifi/include -I/root/esp/esp-idf/components/esp_wifi/esp32/include -I/root/esp/esp-idf/components/esp_eth/include -I/root/esp/esp-idf/components/efuse/include -I/root/esp/esp-idf/components/efuse/esp32/include -I/root/esp/esp-idf/components/app_trace/include -mlongcalls -Wno-frame-address   -ffunction-sections -fdata-sections -fstrict-volatile-bitfields -nostdlib -Wall -Werror=all -Wno-error=unused-function -Wno-error=unused-but-set-variable -Wno-error=unused-variable -Wno-error=deprecated-declarations -Wextra -Wno-unused-parameter -Wno-sign-compare -ggdb -Os -freorder-blocks -std=gnu99 -Wno-old-style-declaration -D_GNU_SOURCE -DIDF_VER=\"v4.0.2\" -DGCC_NOT_5_2_0 -DESP_PLATFORM -MD -MT esp-idf/lepton/CMakeFiles/__idf_lepton.dir/cci.c.obj -MF esp-idf/lepton/CMakeFiles/__idf_lepton.dir/cci.c.obj.d -o esp-idf/lepton/CMakeFiles/__idf_lepton.dir/cci.c.obj   -c ../components/lepton/cci.c
../components/lepton/cci.c:25:10: fatal error: i2c.h: No such file or directory
 #include "i2c.h"
          ^~~~~~~
compilation terminated.
[7/24] Building C object esp-idf/lepton/CMakeFiles/__idf_lepton.dir/vospi.c.obj
FAILED: /root/.espressif/tools/xtensa-esp32-elf/esp-2020r3-8.4.0/xtensa-esp32-elf/bin/xtensa-esp32-elf-gcc  -Iconfig -I../components/lepton -I../main -I/root/esp/esp-idf/components/newlib/platform_include -I/root/esp/esp-idf/components/freertos/include -I/root/esp/esp-idf/components/heap/include -I/root/esp/esp-idf/components/log/include -I/root/esp/esp-idf/components/soc/esp32/include -I/root/esp/esp-idf/components/soc/include -I/root/esp/esp-idf/components/esp_rom/include -I/root/esp/esp-idf/components/esp_common/include -I/root/esp/esp-idf/components/xtensa/include -I/root/esp/esp-idf/components/xtensa/esp32/include -I/root/esp/esp-idf/components/esp32/include -I/root/esp/esp-idf/components/driver/include -I/root/esp/esp-idf/components/esp_ringbuf/include -I/root/esp/esp-idf/components/esp_event/include -I/root/esp/esp-idf/components/tcpip_adapter/include -I/root/esp/esp-idf/components/lwip/include/apps -I/root/esp/esp-idf/components/lwip/include/apps/sntp -I/root/esp/esp-idf/components/lwip/lwip/src/include -I/root/esp/esp-idf/components/lwip/port/esp32/include -I/root/esp/esp-idf/components/lwip/port/esp32/include/arch -I/root/esp/esp-idf/components/vfs/include -I/root/esp/esp-idf/components/esp_wifi/include -I/root/esp/esp-idf/components/esp_wifi/esp32/include -I/root/esp/esp-idf/components/esp_eth/include -I/root/esp/esp-idf/components/efuse/include -I/root/esp/esp-idf/components/efuse/esp32/include -I/root/esp/esp-idf/components/app_trace/include -mlongcalls -Wno-frame-address   -ffunction-sections -fdata-sections -fstrict-volatile-bitfields -nostdlib -Wall -Werror=all -Wno-error=unused-function -Wno-error=unused-but-set-variable -Wno-error=unused-variable -Wno-error=deprecated-declarations -Wextra -Wno-unused-parameter -Wno-sign-compare -ggdb -Os -freorder-blocks -std=gnu99 -Wno-old-style-declaration -D_GNU_SOURCE -DIDF_VER=\"v4.0.2\" -DGCC_NOT_5_2_0 -DESP_PLATFORM -MD -MT esp-idf/lepton/CMakeFiles/__idf_lepton.dir/vospi.c.obj -MF esp-idf/lepton/CMakeFiles/__idf_lepton.dir/vospi.c.obj.d -o esp-idf/lepton/CMakeFiles/__idf_lepton.dir/vospi.c.obj   -c ../components/lepton/vospi.c
In file included from ../components/lepton/vospi.c:38:
../components/lepton/vospi.h:31:10: fatal error: sys_utilities.h: No such file or directory
 #include "sys_utilities.h"
          ^~~~~~~~~~~~~~~~~
compilation terminated.
ninja: build stopped: subcommand failed.
ninja failed with exit code 1

How can I fix it?

skieast, 2022-03-15:
I've made changes on my fork to build using Cmake and the latest stable idf (4.4)
If there is interest i could do a PR

danjulio, 2022-03-15:
Yeah, that sounds interesting.  Would be good to get off of 4.0.2.  Things I'm worried about are having to retest everything and performance.  Can you give me a quick idea of what had to change?  (I saw your other issue regarding cJSON.  Not sure what happened there but it looks like cJSON should be part of every IDF release).

skieast, 2022-03-16:
From my memory:
I changed all the CmakeList.txt files to include all the dependent files. Seems to be needed to cmake correctly
Changed one line to switch the heap_caps_malloc region to MALLOC_CAP_SPIRAM for the json image text buffer. The IDF spi code checks if the buffer passed is in DMA region, if not the code allocates a buffer in DMA region and memcopies the result to the passed buffer.  I only compiled and tested briefly with the IOS app.

	sys_image_rsp_buffer.bufferP = heap_caps_malloc(JSON_MAX_IMAGE_TEXT_LEN, MALLOC_CAP_SPIRAM);

I was originally only trying to build it so for a PR would just start from scratch and apply enough changes with nothing extraneous.

Yes you are right about cJson.   As I am bulding with cmake the components being used in the IDF have to be explicitly listed. I'll make that change and that should be it.

danjulio, 2022-03-16:
Thanks for the info.  Why did you have to change the malloc for the sys_image_rsp_buffer?  Did the system run out of memory (malloc fail)?

As you figured out, that buffer needs to be in DMA accessible memory because that buffer is passed to the SPI Slave peripheral when the camera is used in the new Hardware Serial mode that the FW 2.X supports (allows connecting the camera directly to another micro instead of using Wifi and used by the tCam project).  It seems to me that the same out-of-memory issue might occur if the SPI driver has to allocate the same size buffer.  The copy may also impact performance since it will occur in series with data being available and notification to the external micro that an image is available.

I say make the PR when you can and I'll test it here.  I just can't promise it'll be done immediately.  But I do appreciate you making the effort and digging into, and understanding, someone else's code!

skieast, 2022-03-16:
Yes, the malloc failed. Doesn't appear to be enough space in dma accessible memory.  I didn't realize that the buffer in question is used for sending to a slave SPI device.  As you said that buffer must be in DMA memory.  The available largest free block of DMA memory to malloc appears to be about 33792 bytes (from what i remember as I was testing).  I believe that the code is trying to malloc 1204*53 or 54272 bytes.  So short a bit.

I'll just get it to build with the idf.py (cmake) build system but it won't work with a slave peripheral and dma mode,

As you said interesting looking at someone else's code and trying to understand it and what hardware is involved. Thanks for the responses.

skieast, 2022-03-17:
Just did a brief test with the attempt to allocate the DMA accessible memory for the spi buffer. Added a log for the free memory
```
I (1753) sys: Buffer Allocation
E (1753) sys: malloc shared json image text response buffer failed
E (1753) sys: DMA largest free block: 33792
E (1763) main: tCam Mini memory allocate failed
```

danjulio, 2022-03-17:
As you thought.  Something in 4.4 is taking more memory.  Off the top of my head the ways to deal with this are a) try to claw back enough internal memory with code changes so the buffer will fit again and b) see if there's anything that can be adjusted in the IDF through the config file.

I forgot to mention that another thing moving the buffer to internal memory did was to improve performance.  The IOS App doesn't display FPS but the desktop application does.  Do you see a drop in performance with the buffer in PSRAM?

skieast, 2022-03-17:
OK got the memory needed. Moved one of the json buffers to spiram/psram. Seems that the memory allocator puts MALLOC_CAP_8BIT into internal ram instead of using the external ram first. Even though it is 8bit addressable.
What sort of frame rate are you seeing with the desktop app over wifi? No idea if this change has affected anything.

I'll now remove all my debug prints and try to get a PR together.

danjulio, 2022-03-18:
Well this is a bit embarrassing.  I took a peek at json_image_text (that I am guessing you moved up to PSRAM) and realized it was no longer being used (a hold-over from the 1.x code I didn't clean up).  So I think there isn't an internal memory space issue after all.  Sorry about that...(and thanks).

The 2.X FW should be able to get the full ~8.7  FPS the lepton is capable of.  Wifi variability can affect this a bit but you should be able to see the desktop app reporting around that FPS while streaming at the fastest rate.

skieast, 2022-03-18:
All good. Thanks again.  I'm seeing around 6fps but as you said wifi variability can affect this. I'll build a stock image without my various changes and compare.  And looking at code like yours is how i learn stuff. or attempt to.

Closed 2022-10-03.

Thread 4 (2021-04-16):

Lepton 3.5 w/ Teensy 3.2 and VSYNC enable

TinManAkshay, 2021-04-16:
Hi,

I have been thinking to connect lepton 3.5 to Teensy 3.2 and use these libraries. Before that i had few questions as follows:

1. Has VSYNC been enabled successfully and use it in your test programs to get the synchronization among packets.
2. What's the max frame rate you got?

If you could give me any valuable info on vsync, frame rate , sync and so on, I'd appreciate it?

Thanks,
Akshay

danjulio, 2021-04-16:
Hello Akshay,

1. Yes, I have successfully used VSYNC on several platforms including the Teensy 3.2.
2. My Teensy 3.2 code only achieved about 4.5 fps because it split its time between reading the Lepton and updating an LCD display.  I believe with appropriate use of DMA channels and scheduling the Teensy platform should be able to read the full frame rate.  I have achieved full frame rate on Pi, Beaglebone (using the PRUs) and ESP32.

Regards, Dan

TinManAkshay, 2021-04-16:
Hi @danjulio ,

Thanks a lot for the quick response.

1. Speaking of ESP32, I didnt find arduino based firmware in your libraries. What software tool you used here for esp32?
2. With teensy 3.2, my project doesnt require LCD display. I just need 160*120 pixel values to be displayed on the monitor. I believe this way I can achieve the frame rate upto 9hz. Can you please suggest me what functions/logics I have to consider to just display the pixel values and get the max frame rate?
3. There is a project which we require lepton 3.5 to work with Pi. But your libraries are sending the data to server using socket logic. As I explained in Point 2 above, that I want to get 160*120 pixel values.

Any suggestion regarding both platforms would be appreciated...

Thanks,
Akshay

danjulio, 2021-04-16:
Hello Akshay,

1. I am using the Espressif ESP32 IDF for ESP32 development (currently I am using v4.0.1): https://docs.espressif.com/projects/esp-idf/en/latest/esp32/

2. I guess you could remove all screen related code and encode the pixel data for transmission over the serial port.  You'd have to make sure the serial port could handle the data and probably up the serial port buffer sizes inside the Teensy Arduino library to accommodate larger amounts of data.  Not sure how to do this however.

3. Perhaps look at other people's Raspberry Pi code for Lepton.

Regards, Dan

TinManAkshay, 2021-04-16:
Hi Dan,

Even though we could get frames out with a frame rate upto 9hz max, but if I want to send the 160*120 data to other medium using UART communication (like Serial prints), for an instance, Raspberry pi 3. To my knowledge, transferring the whole 160*120 frame from ESP32 to Pi would reduce the frame rate right? What's your thought on that matter?

danjulio, 2021-04-17:
Here's some calculations for serial data transmission.  160 x 120 pixels = 19200.  Each pixel is 16-bits of data unless the camera is operating with AGC turned on in which case the pixel data is contained in the lower 8-bits so with some processing each pixel could be 8-bits.  This means you have to move 19200x2 = 38400 bytes 8.7 times per second = 334080 bytes/sec (excluding any kind of framing data so you can easily decode the stream).  This would require a minimum baud rate of ~2.7 Mbit/sec which is significantly higher than the serial port is usually run.  In addition because there is so much data you would have to increase the internal serial buffers to avoid a slow down.  So it's probably pretty tough to output data using the serial port.

Something you might look into - but I have no experience with and can't offer any additional suggestions on - is to use the USB peripheral on a Teensy 4.  You should be able to achieve a lot higher data rate at the expense of having to deal with USB on the Teensy and in whatever receives the imagery.

TinManAkshay, 2021-04-19:
Hi Dan,

Yes I understand those calculations which need to be taken into account if we proceed with Serial communication.

Would the Teensy 3.2 libraries work with SAMD51 (built by Microchip tech) microcontrollers like Adafruit Feather M4 and so on???

danjulio, 2021-04-19:
I'm sorry Akshay, unfortunately I cannot answer that question as I have no experience with the SAMD51 (or its arduino libraries).  I would think, since they are all pretty simple libraries, the answer would be "yes" but probably with some porting needed.

TinManAkshay, 2021-04-19:
Dan,

Its alright. Not a problem at all....

I was wondering if I use your teens3.2 libraries on SAMD51 MCU with some porting (as you said), then I need to print 160*120 pixel values as you copied the whole packet into Buffer using the function named "CopyPackettoBuffer(uint8_t line)". How would I print the frame using that function?

Thanks,
Akshay

TinManAkshay, 2021-04-20:
Hi Dan,

I have been trying to compile the teensy arduino libraries with latest i2c_t3.h (which I just downloaded) release. its giving me a lot of errors in LeptonSDKEmb32OEM.cpp which is associated with i2c_t3.h library. I believe i2c_t3 had been modified after you developed these libraries.

Your Thoughts?

danjulio, 2021-04-21:
Regarding serial data.  I don't think you want to modify CopyPacketToBuffer as this is a low level routine that's part of the process of getting an entire image in ProcessPacket.  You want to print lepBuffer once it's been filled (where my example programs call the routines to display the data).  You'll have to figure out how you want to print it out, what buffering you need and what, if any, framing you want.

Regarding your compilation errors, without the specific errors, I have no idea of what's going wrong.  I just updated the github repository with a version of the LeptonSDKEmb32OEM library that uses the Wire library on platforms other than Teensy.

Closed 2021-04-16.

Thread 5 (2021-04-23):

Hex-File for TTGO T7 1.5

kami83, 2021-04-23:
Hi,

i am trying to use the firmware with the Lilygo TTGO T7 1.5 board. Can you offer me a precompiled hex-file and the correct wiring for this board?

I have got a lot of problem because i am using the Lepton 2.5 with the Breakoutboard 1.4.

Thanks a lot.

cu kami

danjulio, 2021-04-23:
Hello,

Precompiled Version 1 code in github repository should work for T7 1.5.

However, my code only supports Lepton 3.5.  I plan no support for any other module.  I don't have any other Leptons and I am not interested in them personally.   Sorry.

Regards, Dan

kami83, 2021-04-26:
Hi,

thanks a lot. I have also a 3.5 Lepton. So i can also test it with this module. Which wiring do you use. For example the SDA is on pin 23 in you picture, but on the module it is on pin 21??
Do i really need the VSYNC pin? on my breakout board there is no VSYNC pin.

Also another question can i get a tCam pcb board?

Thanks a lot.

BG kami

danjulio, 2021-04-26:
The ESP32 is flexible about what functions are associated with various GPIO.  You need to following the wiring as I showed it and with the GPIO described in the code's system_config.h file (copied below).

You need VSYNC.  At least one of the earlier Group Gets breakout boards provided VSYNC as a pad on the PCB (GPIO3).  You can see this if you look at my code associated with the Teensy 3.2 in this repository and documented at [hackaday.io](https://hackaday.io/project/159615-lepton-35-thermal-imaging-camera).

Group Gets will carry the tCam-Mini assembled PCB.

```
//
// IO Pins
//   Lepton uses HSPI (no MOSI)
//
#define BTN_IO            0
#define RED_LED_IO        14
#define GREEN_LED_IO      15

#define LEP_SCK_IO        5
#define LEP_CSN_IO        12
#define LEP_VSYNC_IO      13
#define LEP_MISO_IO       19
#define LEP_RESET_IO      21

#define I2C_MASTER_SDA_IO 23
#define I2C_MASTER_SCL_IO 22

```

kami83, 2021-04-29:
Hi,

thanks a lot for the answer. I found the Pad and will test it. But on the github history i found to folders with precompiled firmware in version 1.0. First the root folder precompiled with 3 Hex files and the subdirectory wih ESP32_v1_silicon. Which are the right version for my TTGO 1.5?

BG kami

danjulio, 2021-04-29:
I don't know what revision of the ESP32 chip is in your module.  You can start with the v1 firmware.  It should work.  And you can try the v3 firmware - the camera won't boot if the silicon is version 1.  You can look at the serial output (115200 baud) and the boot process will tell you the silicon revision.

kami83, 2021-04-30:
Hi,

thanks a lot. It works really fine with the TTGO 1.5 and the Lepton 3.5 (It doesnt work with the 2.5 Module). I have to use the Silicon v1 Version. If i use the AP setting i can connect to the standard ip with the Desktop App. But if i change the wifi setting to my router i can not change the IP Adress in the Desktop app, because i cannot write any . (dots) in the ip only ",". Maybe you can fix this??

Thanks a lot.

BG kami

danjulio, 2021-04-30:
I'm glad you got it running.  I do not understand your comment about entering an IP address.  I have tested that on all supported platforms and it works.  Try selecting the existing contents, deleting them and then entering an IPV4 address (e.g. XX.XX.XX.XX).  If you continue to have trouble then please provide more information so I can investigate.

kami83, 2021-05-01:
Hi, thanks a lot for the quick answer. I found a solution, but first of all i will try to describe the problem. In your mask Desktopapp under Win64 i can enter a ip adress in the field, if i use my keyboard i can not enter all numbers and i can not enter a dot. so i can only enter something like 100,100,100,100. The software is blocking this. I found a workaround. If i delete the field contents and then paste the IP adress it works. It looks like the field is filtering some values. Maybe you can fix this problem in your next version.

I have got another question. I am would like to add a TFT and SD-slot for my TTGO. Have you got a schematic for this (like your tCam) and maybe the firmware?

Thanks a lot. Have a nice weekend.

BG kami

danjulio, 2021-05-03:
I apologize but I cannot duplicate your failure with the IP entry on Windows.  I can successfully enter an IP address in many ways on both Win 7 and Win 10.  The field does attempt to keep the form "XXX.XXX.XXX.XXX" but you can enter any IP address if you select the existing contents to replace. You can also select any sub-field and replace that with no problem.

I have no plans to extend tCam-Mini with an LCD and SD-Card.  You might look at the tCam-Mini source code as well as other examples of using whatever LCD you want to use and then see how I generate visual data in my FireCam source code if you wanted to tackle this project on your own.

kami83, 2021-05-04:
Hi, i tried to make a screenshot. In field 1 i can only enter numbers with comma in this style. In all other fields 2,3 i can enter everything. Maybe you use a mask or a filter for the IP field?
Under Windows i can paste a normal ip adress. Under MacOS this is not possible.
Can you send me your XOJO Project? I would also like to see how you calculate temperatures etc. for some function in my python scripts.

For the functions with the LCD and SD-Card i will try to wire it with my TTGO. Have you compiled a firmware of FireCam for ESP32 TTGO?

Thanks a lot. Have a nice day.

BG kami
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

danjulio, 2021-05-07:
Ah, I see.  I didn't consider international settings.  Thanks for explaining.  You are correct that I used a mask.  I have to think about it but maybe I'll just remove it and try to validate later.   I'll let you know when there's a new version to try.

At this time I'm not sharing the source code for the xojo applications.  However I did upload demonstration python programs that show how to calculate spot temperatures from both telemetry and the CCI interface.

Unfortunately no Firecam firmware for anything other than the custom board I designed.

kami83, 2021-05-07:
Hi, thanks a lot for the answer. I will wait for the new version.

BG kami

Closed 2021-05-07.

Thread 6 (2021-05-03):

Example for python with temperature and stream

kami83, 2021-05-03:
Hi,

can you please give a python example how to decode the temperatures from the radiometric string?

Maybe you can also give an example how to show the stream with python?

Thanks a lot.

bg kami

danjulio, 2021-05-03:
The python library is a work in progress and is not my area of expertise.   The engineer who is helping me and I have plans for more demos.  I will certainly take your suggestion into account but I cannot promise to make any particular type of demo.

kami83, 2021-05-04:
Hi, no problem i am working on it. Temperature is done now i am trying to watch the stream. If i can i would like to help.

BG kami

danjulio, 2021-05-07:
I updated the python area with a new driver and set of examples.  You'll have to upgrade your camera's firmware to v1.3 as it has new features the driver is using.  One example displays an image and the others show how to decode the telemetry stream and communicate directly with the Lepton's CCI interface (be careful, easy to crash it).

kami83, 2022-05-10:
Hi,

is it maybe now possible to give an example for video streaming with python?

BG kami

bitreaper, 2022-05-19:
Hi BG Kami, you should now be able to find a stream example in examples/streamtest.py.  It is using the Tk library which is the easiest to install and most widely available.  With pull request #26 you should be able to install tkinter and use it.

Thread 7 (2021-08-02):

How should I convert the stored radiometric files to a standard image output (jpg, png, gif)

baldeagle, 2021-08-02:

danjulio, 2021-08-02:
The desktop application can export these formats from an image directly acquired by the camera, from a file or from a frame in a video.  You use the preferences to select if you will add additional metadata to the image or not.  You can also include the spotmeter or not.

baldeagle, 2021-08-02:
I would like to train an object detector based on the stored radiometric images (.tjsn suffix).  But I'm not sure how to unpack that format into something that can be used by normal image detector algorithms.   I'm currently trying to modify dump_image.py to read from the stored files.

Also: Thank you for developing this and sharing it via groupgets!  It is an awesome little thermal monitor.

danjulio, 2021-08-02:
I should probably add a python example showing how to read a file, but possibly you could read the file, convert the base64 json image data into an array and then convert that into an RGB array which you could either directly use with your algorithm or convert it into a known filetype that they take.  I don't have examples showing how to read the file and but the examples show how to decode the base64 and get an RGB image.  I'm not very familiar with matplotlib but it can probably generate a known image file from the grayscale image that is calculated in disp_image.py.

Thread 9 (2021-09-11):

Power by lipo

Andi68-at, 2021-09-11:
Hello
Can I use the Tcam-mini directly with a 3.7V lipo or do I need a voltage converter?
how many mAh
thanks

danjulio, 2021-09-11:
Yes, it can be powered directly by a LiPo connected to the 5V terminals.  It requires 250-300 mA operating current.  Two things to consider:

1. Never connect USB power when the LiPo is attached.
2. tCam-Mini will fail when the Lipo voltage falls near or below 3.3V as the regulator providing 3.3V to the ESP32 will drop out of regulation.  You should provide a low-voltage shutdown circuit if possible set to about 3.3 - 3.4V.  This still provides you most of the energy in the LiPo.

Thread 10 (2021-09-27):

interested in tcam

spereg53, 2021-09-27:
how can  integrate publish mqtt topics on esp32, for send the value  to some broker, ,the maxim distance of the lepton??? and the maximum grades on centigrades,that can measurement,i wan to make some proyects for electrical devices,in a substation electrical,thanks in advanced

danjulio, 2021-09-27:
Hello spereg53:

I'm not sure I understand your questions but I have attempted some answers below.

"how can integrate publish mqtt topics on esp32, for send the value to some broker"
Could you use the python driver and write some python code running on a computer that connects to the tCam-Mini and publishes the information you are interested in using a MQTT library?

"the maxim distance of the lepton???"
I do not understand this question

"the maximum grades on centigrades"
Temperature information can be had two ways:
   1. Use the spot meter data in the telemetry
   2. Compute a temperature anywhere by taking the radiometric data and converting it to temperature using the gain information in the telemetry.

  You can see examples of how to use the python driver in the repository as well.

spereg53, 2021-09-27:
do you know some flow for working on node-red???thanks
ING.SERGIO M.PEREZ GORDILLO
CALLE DE CHAMULA #21
COL.LA LOMITA;C.P.29060
TUXTLA GTZ.CHIAPAS,MEXICO
TEL:019612640373 y
019611214526
CELULAR:9612015537
***@***.***
***@***.***

El lun, 27 de sep. de 2021 a la(s) 11:26, Dan Julio (
***@***.***) escribió:

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

danjulio, 2021-09-27:
No, I'm sorry.  I don't have experience with node-red.

Thovthe, 2022-03-18:
I think this issue can probably be closed but I'll add this to cover at least one of these questions.

To know about the technical capabilities on the sensor (max temperature in different modes etc.) look at the data sheets linked from these pages:
https://store.groupgets.com/products/flir-lepton-3-5
https://store.groupgets.com/products/flir-lepton-2-5

Closed 2022-03-21.

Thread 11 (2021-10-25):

New FLIR LEPTON® FS

bordins, 2021-10-25:
Hi,

I wonder the new [FLIR LEPTON® FS](https://groupgets.com/campaigns/976-teledyne-flir-lepton-fs) is compatible with the tCam-Mini.

[EDITED ... SOLVED]
Another question is that what are [differences](https://forums.openmv.io/t/radiometric-vs-non-radiometric-leptons/1795/4) between radiometric and non-radiometric cameras, in terms of data output from the camera module.  It seems the LEPTON FS' radiometric data is not as accurate as previous models, making it more affordable.

All the best,

Closed 2021-11-02.

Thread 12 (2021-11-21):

ESP32 Python FFC Mode

jperfo, 2021-11-21:
Hello,

at first thank you for the wonderful project!

Because I want to integrate the tcam mini in an house alarm system with motion detection I encountered the automatic FFC to be a problem. A problem, because on the FFC action the motion detection is triggered. If I could get the FFC status oder control it manually this could be resolved. Therefore my question:

1. Is it possible to read the FFC status via Python?
2. Is it possible to set the FFC mode to manually via Python?
3. If all the above is not possible: What would you recommend? :-)

Thank you very much
jperfo

danjulio, 2021-11-21:
Thank you for the kind words.  I understand how the FFC might confuse a motion detection algorithm (and the few seconds after as the Lepton settles back down).  It should be possible to do what you want using the python interface.  You should download, if you have not already, a copy of the Lepton data sheet (which describes the contents of the telemetry data) and the Interface Description document (IDD - which describes the CCI command interface).  You should be able to find these on the Group Gets Lepton pages.  Lots of good information about the Lepton and the way it works.

1. There are two ways to read the FFC status.  The Status field in the telemetry data returned with each image contains current FFC information in words 3 & 4.  See "Table 3 - Status Bit Encoding (Telemetry Row A, words 3 and 4)" in the Lepton datasheet.  You can also use the python driver's get_lep_cci method to run a Get SYS FFC Status command (see 4.4.29) in the IDD.

2. You can configure the Lepton's FFC mode using the python driver's set_lep_cci method to run a Set SYS FFC Mode Control command (see 4.4.27) to configure the mode.   Then you can use the SYS Run FFC Normalization command to explicitly execute a FFC if you want.

The get/set_lep_cci methods provide direct access to the CCI and are configured in terms of the 16-bit word data fields so you have to map the IDD C-language description into the actual 16-bit data words sent/received from the Lepton.  The intent of these methods was to be able to execute commands that there wasn't a more specific python API for.   The Desktop application also provides a way to run direct CCI commands and might be useful to poke around and see what the lepton returns, etc.  Of course you can do this from python as well.  The "cci_demo.py" program shows how to use these methods.

I hope this is helpful.  Good luck with your project.

baldeagle, 2022-01-12:
How are you integrating the TCAM into you home monitoring setup?

danjulio, 2022-01-12:
I haven't.  I did write a toy web server that is designed to connect to one or more cameras and store images when certain temperature criteria are met.  I played with it last fall looking for large animals on my property with mixed success.  What I want to do is exactly what you're doing and add motion detection but it seems a non-trivial problem to solve.

jperfo, 2022-01-14:
Hello,

at first, thank you very much, danjulio. Sorry for the late answer but I was a bit busy.

Your advice was very helpful so I could solve the problem regarding FFC. The current version of the motion detection script works with OpenCV. When the FFC is triggered the script ignores the changing pixel for a certain amount of time. An alternative would be to trigger FFC manually or to deactivate. However, I try to avoid the latter.
What of course needs to be said is the fact that the are of surveillance is very limited in my use case - it's a balkony. I haven't integrated it fully yet but the test result were ok. One must play with various settings that can be done for such a script, the alarm should not be triggered as soon as there is a human detected (because it could be also something different) but after a certain amount of time. Another approach worth trying out could be a tensor flow trained alarm, eventually.

I can keep you informed as soon as I make progress.

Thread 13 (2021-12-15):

Feature Request: Android App

gigawatts, 2021-12-15:
Any plans in the works for an Android app to stream video and take snapshots from the tCam-mini? That would make for an excellent mobile setup, with the tCam-mini in AP mode, phone/tablet connected to the AP and no PC required.

danjulio, 2021-12-15:
Short answer: yes!  I want it, too.

Long Answer: I have to learn to write mobile apps and my development platform, xojo, for which I have a ton if libraries and supporting code for tCam has to support Sockets for the Android build system (they just released their alpha Android build system).  I'm going to start with IOS since it's fully supported but hopefully the code I write for that will port right over to Android when xojo is ready.  I wish I could give you a date but there are too many variables.  Just be assured I'm interested in this too.

gigawatts, 2021-12-16:
Awesome! If you need any beta testers for Android, let me know. I don't own any iOS devices made in the last decade, so I probably won't be of much use there, haha!

KingRikkie, 2022-02-09:
.NET MAUI (former called Xamarin - full-feature cross-platform mobile & desktop framework) comes to mind. One code base + shared UI can generate builds for Windows/Mac/Linux/iOS/Android all at once.

danjulio, 2022-02-21:
The iOS App just went live at https://apps.apple.com/us/app/tcamview/id1610451813

As soon as xojo supports sockets for Android I will begin porting it there too!

@KingRikkie - I appreciate the suggestion.  Unfortunately I do this on the side and have a big investment in xojo code already (that has proven to be very useful).  I don't have the time to take on a new development environment.

dhelleberg, 2022-10-17:
Is the source code of the Xojo app available somewhere? I could take a look at it and may support android porting....

danjulio, 2023-02-24:
Another developer has created an Android app and is looking for alpha testers.  He's using the Play Store testing mechanism to distribute the app so please email me with your Google Email ID (for the phone) if you'd like to test the app.

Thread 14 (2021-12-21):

Quick explanation of I2C port on tCam-Mini

timbo100, 2021-12-21:
Hi Dan,   I'm very thankful for your project and I bought a batch of the tCam-Mini PCB's from GroupGets.  Thanks

I'm looking forward to digging into the hardware design and software components but I'm a little too busy and need a quick(er) answer if you don't mind.

I would like to integrate/communicate with a Lepton 3.5 from another SBC which may not have an OTG USB port and so trying to figure out how I will be able to get access radiometry info.  I see an I2C interface and was wondering what's accessible from that I/F?

I'm hoping to be able to query temperatures across the 2D pixels array from another ESP32, if not the onboard ESP32.  Any thoughts/suggestions?

Again, great job and thanks

danjulio, 2021-12-21:
Hello,

The I2C port provides access to the bus used by the ESP32 as master communicating with the Lepton's Command and Control Interface (CCI) and is how it configures the Lepton.  I broke it out because I had been thinking of including support for a I2C-based TOF distance sensor to try to improve accuracy but some testing shows that there may not be a big gain doing that so that part of this project moved to a lower priority for me.  Unfortunately it cannot be used by an external device to communicate with tCam-Mini.

Primarily tCam-Mini is designed to be accessed via the Wifi interface.  The new version 2.0 Firmware has support for a new hardware interface on some of the unused ESP32 IO pins that can be used instead of the WiFi interface.  I will use this for the tCam project but it could be also be used with another controller.  It consists of a serial port over which the same json commands are sent and received as over the Wifi interface with the exception of the image json object which is retrieved over a separate SPI slave interface (since there is so much data).  I still have to document this interface but it is functional in the new firmware.

A future revision of the tCam-Mini PCB will break these signals out to a header, although with delicate soldering it is possible to connect the necessary wires directly to the ESP32 module pins on existing boards (this is what I did for testing).

I will try to spend some time in the next couple/three weeks to documenting this interface in the tCam-Mini github readme.

FYI: tCam-Mini does not support image data transfer on the USB interface (like Group Get's PureThermal board which looks like a UVC class camera).  This interface is used for power and programming the ESP32 as well as monitoring diagnostic information over USB Serial.  You will need to use a Windows based utility (or the Espressif SDK) to load the 2.0 firmware but after that the new firmware also supports OTA updates from the desktop application for subsequent updates.

timbo100, 2021-12-21:
I appreciate your quick feedback.  I will look at the possibility of a local wireless connection, or there's also the possibility that I rewrite your ESP32 code to do what I need.   Thanks again.

Closed 2021-12-22.

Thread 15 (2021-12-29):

ESP32 programming error

mortenx, 2021-12-29:
Why this error?

UnicodeEncodeError: 'gbk' codec can't encode character u'\xf5' in position 13: i
llegal multibyte sequence

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

danjulio, 2021-12-29:
Unfortunately I don't have visibility into Espressif's tool.  However using google to lookup 'gbk' (https://pub.dev/packages/gbk_codec) and this error leads me to believe that the tool doesn't like the encoding in some string.  There is some unicode it can't understand.  Perhaps one of the filename strings has the extra unicode.   Is there another way you can enter these strings?

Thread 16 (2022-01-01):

how to use

calvfoo, 2022-01-01:
Hi,
I got my Tcam.

I use my phone to connect to it via wifi.

I got this on the console log (connected to PC).

19:34:13.396 ->  [0;32mI (7031) lep_task: Could not get lepton image [0m
19:35:21.123 -> I (74741) wifi:new:<1,0>, old:<1,1>, ap:<1,1>, sta:<255,255>, prof:1
19:35:21.123 -> I (74741) wifi:station: ee:94:b0:93:ae:b7 join, AID=1, bgn, 20
19:35:21.123 ->  [0;32mI (74741) wifi_utilities: station:ee:94:b0:93:ae:b7 join, AID=1 [0m
19:35:22.885 ->  [0;32mI (76521) tcpip_adapter: softAP assign IP to station,IP is: 192.168.4.2 [0m
19:37:15.146 ->  [0;32mI (188781) lep_task: Could not get lepton image [0m
19:37:15.656 ->  [0;32mI (189301) lep_task: Could not get lepton image [0m
19:37:16.210 ->  [0;32mI (189831) lep_task: Could not get lepton image [0m

On the phone should I use browser to connect to 192.168.4.2?

calvfoo, 2022-01-01:
FLIR3.5 camera is connected.

calvfoo, 2022-01-01:
ok
i used my PC,and connect the wifi to the Tcam
I then launched the tcam Windows app, and try to connect to 192.168.4.1
nothing happens.

Got error socket 103.

calvfoo, 2022-01-01:
ok, tried with another PC, and can connect.

Closed 2022-01-01.

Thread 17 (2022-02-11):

[FR] tCam + tCam-mini merge

Ramalama2, 2022-02-11:
Hey dan, im pretty sure this was asked before somewhere, but anyway.

First, the tCam mini is a really nice project, and probably the only way to make the lepton 3.5 usable. So i don't really understand why there aren't any other (halfway actual) projects about this camera.
However at this point, thank you very much for all the effort you do!

Now the main point, that i don't 100% understand...
Somehow tCam and tCam mini are 2 separate projects, with different hardware etc.... (At least from what i see)

Wouldn't it make more sense to use always tCam mini as the "carrier board" for the lepton 3.5 and add to it an wired interface that will allow it to connect simply to an raspberry?
I know the usb serial interface is probably not fast enough, so you need to find only a solution for that.
But this would allow it, to make everything much simpler, as the "full" tCam will become only a set of:
Rpi4 + desktop app
tCam-mini
Some sort of battery management pcb

And if you have a full tCam "set", it will still allow for a wifi access, because of tCam-mini. (Or if there isn't space on the esp, the raspberry could make an hotspot/nginx server either...)

And especially as the most interesting part of this is, this would allow every user to start with a tCam-mini and upgrade it later with almost no effort to a full tCam 🙈

Cheers ✌️

danjulio, 2022-02-11:
Hey, the answer to your questions of why is history.  Simply how things unfolded as I played around with the Lepton.  :-)

I started with the full ESP32 tCam but it ran into performance and complexity issues so I spun out tCam-Mini with the Lepton and Wifi parts as a first product.  I then re-structured the original tCam code into a part that handles a display (w/ GUI) and SD-card storage plus more commands.  To support this tCam-Mini got some new functionality that is actually along the lines of what you propose (see below).  I also scratched an itch to design the ESP32 dev board (gCore 2) that I wanted with a very high performance 480x320 pixel cap-touch display, good power and battery management, RTC and fast SD-card storage.  So now tCam = tCam-Mini + tCam firmware running on my (yet to be introduced) gCore dev board and it's pretty much done.  I just have to document everything and find a way to get some gCore boards built (at this writing, parts shortage is a killer).

Before I played with the ESP32, I experimented with the Pi (getting data reliably from Lepton was pretty iffy at the time - I always thought it needed a proper kernel level driver) and then using the PRUs on a Beaglebone along with a hacked version of another power board I had made for the Pi (Solar Pi Platter).  But I more-or-less lost interest in that project because of how slow Linux booted on the Beaglebone black and the work I'd have to do to the PRU code to get full radiometric data out of the Lepton (on the other hand the PRUs are a rock solid way to do real-time stuff like reading the Lepton).

Starting with FW 2.0, tCam-Mini now sports a new hardware interface (you can see it if you look at the code).  The interface is comprised of a serial port running at 230,400 baud and a slave SPI port.  A Mode input tells the camera on boot to use either the Wifi interface or the hardware interface (serial mode).  When configured for serial mode all the same json commands that are sent and received over the wifi interface can be sent and received over the serial interface with one exception.  Instead of sending image data over the serial interface the camera sends a new "image_ready" message over the serial interface and the external controller can read the image using the much faster SPI port.  This is how the gCore communicates with tCam-Mini to make tCam and it's certainly how another controller like a Pi could use tCam-Mini.  The only missing thing is a library to make using it easier.  Perhaps the python driver could be modified to use serial/spi peripherals instead of a socket.

I have designed a new version of the PCB that breaks these signals out to a header and it should be available within a few weeks on Group Gets.  Intrepid users of the current PCB revision could actually solder wires to the castellated connectors on the ESP32 like I did during development.

In the next few weeks I will have all of this documented and the new hardware revision released.

So if you made it all the way here I hope this helps explain why things ended up the way they did and what I'm going to do going forward.

Ramalama2, 2022-02-11:
Now, while you mentioned the serial/spi connection, i remembered again, that i readed it already somewhere here on GitHub 🙈

However, thank you very much for all the explanation and im glad that you basically confirmed, that we can use the tCam mini later together with some sort of an sbc that has spi, like the pi.
This will basically allow to design/make (3d print) an portable tCam. At some point in the future at least, once the software hurdles are taken.

However, sadly im not a dev, but i can help out with cad/modeling if there is need.
Thanks again dan 👍✌️

PS: should i close this issue?

danjulio, 2022-02-14:
I'll close this.  I hope the new board is helpful to your project when it's released!  Good luck with everything.

Closed 2022-02-14.

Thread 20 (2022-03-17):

Packaging and Licensing

Thovthe, 2022-03-17:
Very cool project, I have a t-cam mini on the way.

I thought I'd make up a pkgbuild of the applications for use on arch based distributions but I can't seem to find the source files or any build instructions.  Are those components not intended to be open source?  I'm also not seeing licensing information for many of the other files.  I'm not sure that I can do much more than packaging and letting people know about the project but I wanted to contribute.

danjulio, 2022-03-18:
Thank you.  And thanks for offering to make a pkgbuild and contribute.

Currently the supporting desktop and mobile applications aren't open source.  Partially because I use the paid xojo development environment and most people have no experience with that or would want to pay for it.  Partially because I worry about the support load of people digging into that code, and partially because I wanted to reserve the ability to possibly make modified versions of it for pay.

I do support the idea of open source - and have published the source to a ton of my work - although I am not religious about it.  Many parts of this project are open source (such as the firmware).  I am willing to have some discussion about sharing the source at some point.

Regarding the licensing: Yeah, probably not super clear and I'll put it on the list of things to do when there's time.  At least a note in some of the readmes.

Maybe not the answer you wanted to hear, but it is the honest truth.  I hope you still find value in the work I've done.

Thovthe, 2022-03-18:
Those are 3 reasonable concerns and I respect that it is your work that you may treat as you see fit.  I hope you won't mind me following up on some points though.
<br />
Is all the business logic for the webapp and the desktop app in xojo's language as well?
<br />
As long as you keep track (maybe with a separate repo) of what code is originally yours and what are community contributions you'd still be free to do whatever and license however with what is your work.
<br />
Having it be FOSS doesn't mean you couldn't get whoever is asking for these other features to pay you to develop them.  Certain licenses would even allow you to use community contributions in closed source as well as open source copies such as 3-clause BSD (though because I am somewhat religious about these things I look at them funny :wink: ).
<br />
I'll leave this issue open till there is more clear licensing for the open source components.  **Sound good?**
(If you clearly outline it some other way I might make up a pull request with the right words in the right places.)

danjulio, 2022-03-21:
All code in the desktop, web and mobile apps is created using xojo.

I appreciate your input regarding licensing.  It is something to consider.

In your opinion, what would make the licensing of open source components more clear?  For example the tCam-Mini firmware clearly states the license in every source file.  Should there be a comment in the readme for that piece?

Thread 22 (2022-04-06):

tCam-Mini with Serial Output

johannesosterberg, 2022-04-06:
Hi, I am excited about my tCam-Mini, I am in the process of building a small Pan Tilt Mount.

Is it possible to add something to the firmware to control the serial interface?

This way a small Arduino could control the Pan Tilt Mount using serial commands and I don't need an extra cable or wifi connection.

Four buttons could send serial commands for up, down, left and right to the Arduino would also be great. Is something like this planned or even feasible? That would make the tCam-Mini even more exciting.

The Arduino code be very simple to implement.

Thank you and many greetings

danjulio, 2022-04-06:
Sounds fun!  Unfortunately, based on your description, I'm not entirely sure what you are asking.  For example where are the buttons and what serial interface?  Is an arduino controlling to the servos/motors?  If so, how do you envision it communicating with tCam-Mini?

The primary serial interface is connected to the USB UART so probably can't be used for anything else (theoretically the ESP32 TX output could talk to something but those signals are hidden in the PCB and not available).

Starting with FW 2.0 there is a (currently undocumented) new hardware interface that makes use of the second serial port in the ESP32 and will be available on future PCBs but this is used for a new mode that allows an external controller to communicate with tCam-Mini directly instead of using WiFi.

Finally there is the internal I2C bus which is exposed on an expansion interface.  This is used by the firmware to configure the Lepton through its CCI interface.   I would use this interface if I were adding an expansion function to tCam-Mini.  It would communicate with some external controller like an Arduino that presents itself as an I2C slave. Then you could add support for an additional json command packet to the FW which could be used to deliver custom data via the I2C interface (using the FW's internal I2C API).  You'd also need custom code on the other end capable of sending this packet (e.g. none of the apps I've written to support tCam-Mini would know anything about this new command).

It doesn't make sense for me to add one-off functionality for individual users of the camera but I do encourage you to consider making your own custom firmware.  As I mentioned above you'd also have to make a custom program to control the camera and view images from it (but this could be facilitated using a modified copy of the json library with your new command added).

johannesosterberg, 2022-04-07:
Thanks for the quick answer, I hadn't realised that the USB UART overrides the serial interface. Thanks for the many points of reference, I'll have to think about how best to do this. Your code is not public, is it? I can understand that you don't want to incorporate the feature. Thanks anyway, I'll have to think about how to solve the problem for myself.

Closed 2022-04-14.

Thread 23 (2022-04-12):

transfer stop while ffc

tantalar, 2022-04-12:
Hello,
 This is very interesting project and would like to work with this. I am using pocketbeagle plus qqvga LCD (ST7735) and the code seems working pretty well. But you know, sometimes image transfer stops (Lepton freezes) and would like to solve this problem.

Before that, I see transfer stops (not freeze, CSN is de-asserted and PRU0/1 LEDs are off) when Lepton executes FFC automatically. I don't see any code handling FFC, it is under auto mode. It is separated from the image path (capture using PRU) then would like to know why it happens (or commanded to PRU from OS? how?). I think image capture must not stop while executing FFC...

danjulio, 2022-04-13:
Hey, glad to see this old code being played with!

In this system the Lepton is deciding to perform the FFC automatically (when the its temperature changes or every few minutes).  Unfortunately the Lepton is unable to generate data while it is performing a FFC.  What is happening is that the code running on PRU0 cannot get a valid frame during the FFC (it is incrementing lep_resync_count) so it de-asserted CSN for LEP_RESYNC_CYCLES (~190 mSec) to reset the Lepton VoSPI.

tantalar, 2022-04-14:
So, when FFC, what is the return value of get_packet()? Is it PKT_DISCARD?

danjulio, 2022-04-15:
Yes, probably PKT_DISCARD or perhaps PKT_ILLEGAL.

tantalar, 2022-04-15:
Thank you for your help.
I would like to ran this interesting code 24H continuously....will update when I succeed.

Closed 2022-04-15.

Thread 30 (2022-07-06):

Esp32

GaelTshamala, 2022-07-06:
Hi Dan,

I hope you are doing well.

I have an application i am currently developing, i m about to buy this amazing module you have designed. I would like to be able to stream short videos of 5 seconds, and also take pictures with the thermal camera, as it will be used in a condition monitoring application.

My idea is to use another ESP32 to connect to the  tcam module wifi, to access the data and send it to the server via another lte module. I saw you mentioned that this module can only work with the desktop application, does it mean i cannot access to the data even wih the ESP32 by sending the json commands to it?

Do you have a SPI example code for this tcam module?

Kind regards,
Gael

danjulio, 2022-07-06:
Hello Gael,

The camera can communicate with any device using WiFi (or with the Rev 4 version, the hardware interface comprised of serial and SPI slave ports).  You should be able to connect to it using another ESP32.  You will have to generate and interpret the json-based command set.

The python driver is being extended to support the hardware interface on the Raspberry Pi as an example.

With both interfaces the camera implements the same json command set with one exception.  Because image json packets are so large (~55kB) the camera implements a new json packet called "image_ready" that it sends over the serial interface to indicate the controlling device should read the image from the SPI slave.

Let me know where I implied the camera would only work with the Desktop application and I will try to correct it as the camera is not limited to the Desktop application (it currently works with an iOS app, the python driver, a simple web server, an android app in development and other people have created drivers in Matlab and R).  The intent was to create an interface that anyone could use.

Regards, Dan

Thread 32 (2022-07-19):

Connect external antenna on tCam-Mini

GillesBra, 2022-07-19:
Dear Dan,
I have bought the tCam-Mini Rev 2 board along with a Lepton 3.5 camera. My model is with a built-in antenna.
I would like to connect an external antenna to increase the range of the wifi connection but I am not sure this is possible with my version of the ESP32 (in the BOM there are 2 different references for built-in or external antenna).
Is it possible to connect an external antenna with my model ?
Which connector reference must I choose and how do I connect it to the board ?
Kind regards.
Gilles

danjulio, 2022-07-19:
Hello Gilles,

It is technically possible to add an external antenna to the WROVER module on tCam-Mini - but it's delicate and you risk destroying the antenna connection and rendering the device useless.

Basically you have to move the 0-ohm resistor that connects the antenna output to either the built-in PCB antenna or an IPEX connector pad.  Then you solder an IPEX connector to the board and connect to an external 2.4 GHz antenna.

The gang at Random Nerd Tutorials has a blog post showing how to do this with the WROOM module, but the process is the same with the WROVER module used on tCam-Mini.

https://randomnerdtutorials.com/esp32-cam-connect-external-antenna/

I was able to do this on a prototype but it is pretty delicate work and you should be prepared to lose your tCam-Mini in the process.  The risk is that you pull a pad off the board while removing the resistor.  I ended up losing the tiny resistor and had to replace it with a tiny piece of wire.  I have no idea how this affected signal quality.

So consider yourself warned - but good luck if you choose to try this modification.  There's always a new Rev 4 board waiting for you to buy at Group Gets should you fail.  :-)

Regards, Dan

GillesBra, 2022-07-20:
Thank you very much Dan.
The process is very clear, but, you are right, it seems risky because the
connections are very small.
I think I'd better buy a Rev4 board.
Kind regards.
Gilles

Le mar. 19 juil. 2022 à 16:22, Dan Julio ***@***.***> a
écrit :

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

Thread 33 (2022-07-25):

Building with idf.py fails

project-x51, 2022-07-25:
Hi Mate,

I love the work your doing with the Lepton.

I cloned your repository and tried to build it inside the VSCode terminal (Espressif Plugin for VSCode) but it failed due to some file dependencies. I was able to fix some of them by adding the REQUIRES keyword into the CMakeLists.txt file but some files appear to be missing from the repository all together.

../components/cmd/upd_utilities.c:27:10: fatal error: esp_ota_ops.h: No such file or directory
 #include "**esp_ota_ops.h**"

../components/sys/ps_utilities.c:30:10: fatal error: nvs_flash.h: No such file or directory
 #include "**nvs_flash.h**"

../components/cmd/json_utilities.h:41:10: fatal error: cJSON.h: No such file or directory
 #include "**cJSON.h**"

These are the changes I made to the CMakeLists.txt files to resolve the other issues.

**components/cmd/CMakeLists.txt**
file(GLOB SOURCES *.c)

idf_component_register(SRCS ${SOURCES}
                       INCLUDE_DIRS . ../../main
                       REQUIRES clock lepton sys)

**components/lepton/CMakeLists.txt**
file(GLOB SOURCES *.c)

idf_component_register(SRCS ${SOURCES}
                       INCLUDE_DIRS . ../../main
                       REQUIRES i2c sys)

**components/sys/CMakeLists.txt**
file(GLOB SOURCES *.c)

idf_component_register(SRCS ${SOURCES}
                       INCLUDE_DIRS . ../../main
                       REQUIRES cmd)

Cheers!

project-x51, 2022-07-25:
I'm using the ESP-IDF 4.4.1 BTW

skieast, 2022-07-26:
I went through the same process and did eventually get it working,  I was working on a PR but put it aside due to other pressures. I  will have to look at it again but you are on the right track.

danjulio, 2022-07-27:
Hey project-x51.  Thanks for the fixes to my CMakeLists.txt files.  I will incorporate those.

I'm not sure why you're not seeing the IDF header files.  I checked and they exist in 4.4 as well.  I still build using the old make system and perhaps you have to be more specific about specifying the IDF directories with the new system.  Maybe something else in the local CMakeLists.txt file or you have to add something so VSCode knows to look in the IDF directories.

It's on my list to try to move the code base to a newer IDF version but the environment I have works so it's really hard for me to prioritize it over all the other things I want to do related to this project.

project-x51, 2022-08-08:
Hi danjulio,

OK, I finally got the code to compile. The CMakeLists.txt files needed to be edited to refer to all the required components and point to the ESP-IDF component folders. The one in the main folder also needed to point to all the C files there to ensure the linker could find them as well.

**CMakeLists.txt**
cmake_minimum_required(VERSION 3.5)

set(EXTRA_COMPONENT_DIRS "$ENV{IDF_PATH}/components")

include($ENV{IDF_PATH}/tools/cmake/project.cmake)
project(tCamMini)

**main/CMakeLists.txt**
set(SOURCES main.c ctrl_task.c lep_task.c mon_task.c rsp_task.c sif_cmd_task.c wifi_cmd_task.c)
idf_component_register(SRCS ${SOURCES}
                    INCLUDE_DIRS .
                    REQUIRES clock cmd i2c lepton sys)

target_compile_definitions(${COMPONENT_LIB} PRIVATE LV_CONF_INCLUDE_SIMPLE=1)

**sys/CMakeLists.txt**
file(GLOB SOURCES *.c)

idf_component_register(SRCS ${SOURCES}
                       INCLUDE_DIRS . ../../main
                       REQUIRES cmd nvs_flash)

**cmd/CMakeLists.txt**
file(GLOB SOURCES *.c)

idf_component_register(SRCS ${SOURCES}
                       INCLUDE_DIRS . ../../main
                       REQUIRES clock lepton sys json app_update)

project-x51, 2022-08-08:
Hi danjulio,

I was able to flash and run the code but then I get a couple of errors. I see if I can figure them out but there here for your reference.

PS D:\ESP32\Lepton\ESP32\tCam-Mini\firmware> C:\esp\python_env\idf4.4_py3.8_env\Scripts\python.exe C:\esp\esp-idf\tools\idf.py -p COM14 monitor
Executing action: monitor
Running idf_monitor in directory d:\esp32\lepton\esp32\tcam-mini\firmware
Executing "C:\esp\python_env\idf4.4_py3.8_env\Scripts\python.exe C:\esp\esp-idf\tools/idf_monitor.py -p COM14 -b 115200 --toolchain-prefix xtensa-esp32-elf- --target esp32 --revision 0 d:\esp32\lepton\esp32\tcam-mini\firmware\build\tCamMini.elf -m 'C:\esp\python_env\idf4.4_py3.8_env\Scripts\python.exe' 'C:\esp\esp-idf\tools\idf.py' '-p' 'COM14'"...
--- WARNING: GDB cannot open serial ports accessed as COMx
--- Using \\.\COM14 instead...
--- idf_monitor on \\.\COM14 115200 ---
--- Quit: Ctrl+] | Menu: Ctrl+T | Help: Ctrl+T followed by Ctrl+H ---
ets Jul 29 2019 12:21:46

rst:0x1 (POWERON_RESET),boot:0x13 (SPI_FAST_FLASH_BOOT)
configsip: 0, SPIWP:0xee
clk_drv:0x00,q_drv:0x00,d_drv:0x00,cs0_drv:0x00,hd_drv:0x00,wp_drv:0x00
mode:DIO, clock div:2
load:0x3fff0030,len:6608
load:0x40078000,len:14788
ho 0 tail 12 room 4
load:0x40080400,len:3792
0x40080400: _init at ??:?

entry 0x40080694
I (29) boot: ESP-IDF v4.4.1 2nd stage bootloader
I (29) boot: compile time 20:06:34
I (29) boot: chip revision: 3
I (32) boot_comm: chip revision: 3, min. bootloader chip revision: 0
I (39) boot.esp32: SPI Speed      : 40MHz
I (44) boot.esp32: SPI Mode       : DIO
I (48) boot.esp32: SPI Flash Size : 8MB
I (53) boot: Enabling RNG early entropy source...
I (58) boot: Partition Table:
I (62) boot: ## Label            Usage          Type ST Offset   Length
I (69) boot:  0 nvs              WiFi data        01 02 00009000 00006000
I (76) boot:  1 phy_init         RF data          01 01 0000f000 00001000
I (84) boot:  2 factory          factory app      00 00 00010000 00100000
I (91) boot: End of partition table
I (96) boot_comm: chip revision: 3, min. application chip revision: 0
I (103) esp_image: segment 0: paddr=00010020 vaddr=3f400020 size=1ae28h (110120) map
I (151) esp_image: segment 1: paddr=0002ae50 vaddr=3ffb0000 size=039dch ( 14812) load
I (157) esp_image: segment 2: paddr=0002e834 vaddr=40080000 size=017e4h (  6116) load
I (160) esp_image: segment 3: paddr=00030020 vaddr=400d0020 size=864d8h (550104) map
I (364) esp_image: segment 4: paddr=000b6500 vaddr=400817e4 size=16314h ( 90900) load
I (402) esp_image: segment 5: paddr=000cc81c vaddr=50000000 size=00010h (    16) load
I (414) boot: Loaded app from partition at offset 0x10000
I (414) boot: Disabling RNG early entropy source...
I (425) cpu_start: Pro cpu up.
I (426) cpu_start: Starting app cpu, entry point is 0x40081420
0x40081420: call_start_cpu1 at C:/esp/esp-idf/components/esp_system/port/cpu_start.c:160

I (0) cpu_start: App cpu up.
I (442) cpu_start: Pro cpu start user code
I (442) cpu_start: cpu freq: 160000000
I (442) cpu_start: Application information:
I (446) cpu_start: Project name:     tCamMini
I (451) cpu_start: App version:      2.1
I (456) cpu_start: Compile time:     Aug  8 2022 11:53:13
I (462) cpu_start: ELF file SHA256:  ea87008092093216...
I (468) cpu_start: ESP-IDF:          v4.4.1
I (473) heap_init: Initializing. RAM available for dynamic allocation:
I (480) heap_init: At 3FFAE6E0 len 00001920 (6 KiB): DRAM
I (486) heap_init: At 3FFC45A0 len 0001BA60 (110 KiB): DRAM
I (492) heap_init: At 3FFE0440 len 00003AE0 (14 KiB): D/IRAM
I (499) heap_init: At 3FFE4350 len 0001BCB0 (111 KiB): D/IRAM
I (505) heap_init: At 40097AF8 len 00008508 (33 KiB): IRAM
I (513) spi_flash: detected chip: gd
I (516) spi_flash: flash io: dio
I (521) cpu_start: Starting scheduler on PRO CPU.
I (0) cpu_start: Starting scheduler on APP CPU.
I (530) main: tCam Mini startup
I (530) ctrl_task: Start task
I (540) gpio: GPIO[32]| InputEn: 0| OutputEn: 0| OpenDrain: 0| Pullup: 1| Pulldown: 0| Intr:0
I (550) gpio: GPIO[0]| InputEn: 0| OutputEn: 0| OpenDrain: 0| Pullup: 1| Pulldown: 0| Intr:0
I (560) gpio: GPIO[14]| InputEn: 0| OutputEn: 0| OpenDrain: 0| Pullup: 1| Pulldown: 0| Intr:0
I (570) gpio: GPIO[15]| InputEn: 0| OutputEn: 0| OpenDrain: 0| Pullup: 1| Pulldown: 0| Intr:0
I (580) sys: ESP32 Peripheral Initialization
**E (580) i2c: i2c_param_config(662): i2c clock choice is invalid, please check flag and frequency**
I (590) sys: System Peripheral Initialization
I (590) time_utilities: Initial RTC time: Thu Jan  1  0:00:00 1970
I (650) ps_utilities: Reading NVS lep info
I (650) ps_utilities: Reading NVS wifi info
I (670) wifi:wifi driver task: 3ffcdd30, prio:23, stack:6656, core=0
I (670) system_api: Base MAC address is not set
I (670) system_api: read default base MAC address from EFUSE
I (700) wifi:wifi firmware version: 63017e0
I (700) wifi:wifi certification version: v7.0
I (700) wifi:config NVS flash: enabled
I (700) wifi:config nano formating: disabled
I (700) wifi:Init data frame dynamic rx buffer num: 32
I (700) wifi:Init management frame dynamic rx buffer num: 32
I (710) wifi:Init management short buffer num: 32
I (710) wifi:Init dynamic tx buffer num: 32
I (720) wifi:Init static rx buffer size: 1600
I (720) wifi:Init static rx buffer num: 10
I (730) wifi:Init dynamic rx buffer num: 32
I (730) wifi_init: rx ba win: 6
I (730) wifi_init: tcpip mbox: 32
I (740) wifi_init: udp mbox: 6
I (740) wifi_init: tcp mbox: 6
I (750) wifi_init: tcp tx win: 5744
I (750) wifi_init: tcp rx win: 5744
I (750) wifi_init: tcp mss: 1440
I (760) wifi_init: WiFi IRAM OP enabled
I (760) wifi_init: WiFi RX IRAM OP enabled
I (770) wifi:set country: cc=US schan=1 nchan=11 policy=0

I (770) wifi_utilities: WiFi initialized
I (780) phy_init: phy_version 4670,719f9f6,Feb 18 2021,17:07:07
I (880) wifi:mode : softAP (7c:9e:bd:91:62:1d)
I (880) wifi:Total power save buffer number: 16
I (880) wifi:Init max length of beacon: 752/752
I (880) wifi:Init max length of beacon: 752/752
I (890) wifi_utilities: WiFi AP tCam-Mini-621D enabled
I (900) sys: Buffer Allocation
**E (900) sys: malloc RSP lepton shared image buffer 0 failed
E (900) main: tCam Mini memory allocate failed**

project-x51, 2022-08-08:
Hi Danjulio,

OK, I had some fun figuring this one out. I'm starting to get a bit more comfortable with the ESP32 now so it wasn't as difficult to solve.

I grabbed the latest build from the master branch as I noticed it was updated just yesterday. This solved the memory allocation issue which I had figured out was because the module never looked for PSRAM. The I2C issue was a little more subtle and related to a change to the config for the I2C controller made in a recent revision of the ESP-IDF.

This is the revised code from the i2c component. It includes the clk_flags property which for some unknown reason is needed in ESP-IDF 4.4.1 which I'm using. I also added some error checking around the i2c_param_config call as this was unhandled previously.

```
esp_err_t i2c_master_init(int scl_pin, int sda_pin)
{
    int i2c_master_port = I2C_MASTER_NUM;
    i2c_config_t conf;

    // Create a mutex for thread safety
    i2c_mutex = xSemaphoreCreateMutex();
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
calvfoo, 2022-10-01:
anyone got the same error? or i did something wrong? i am using esp idf 4.4.1

calvfoo, 2022-10-01:
ok, it works now after i use this for cmakelist.txt in the main folder

set(SOURCES main.c)
idf_component_register(
	SRCS
		"main.c"
		"ctrl_task.c"
		"mon_task.c"
		"lep_task.c"
		"net_cmd_task.c"
		"rsp_task.c"
		"sif_cmd_task.c"

                    INCLUDE_DIRS "."
                    REQUIRES clock cmd i2c lepton sys)

target_compile_definitions(${COMPONENT_LIB} PRIVATE LV_CONF_INCL

danjulio, 2022-10-02:
Well done calvfoo.  I hadn't kept the cmake files up-to-date over the project. Thanks, in part, to project-x51's work, I just committed official version 3.1 of the firmware to the repository and it is now built using v4.4.2 of the IDF.  Aside from the build environment, the biggest changes were moving to the netif API (removing the deprecation warnings).  One thing for those of you who moved v3.0 to IDF v4.4.X is that performance and memory use changed some so make sure everything works as you expect.

Closed 2022-10-02.

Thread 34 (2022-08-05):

Feature Request: RTSP tCam-mini

pierre-muth, 2022-08-05:
Dear Dan,
I recently played with the ESP-CAM module with rtsp server (even add some code for OV7725 support). However I only tweak the code within plateform.io, and I don't feel I'll be able to add rtsp server feature to your project.
Do you think it is something doable ? It would be very nice to be able to link the tCam-mini to any CCTV surveillance station, VLC player and so forth, as we can do with the ESP-CAM.
Thanks a lot for your hard work, the tCam-mini module and the apps are amazing !
Pierre

danjulio, 2022-08-05:
Hello Pierre,

I understand.  A stream like the ESP-CAM modules produce would be very useful and I have thought about it.  To modify the tCam-Mini firmware for that would take the following basic additions.

1. Add a web server.  Adding the server wouldn't be too difficult, and could be based on the ESP-CAM code but the web controls and associated handlers would have to be changed to match the Lepton sensor (AGC enable, Gain, Emissivity, Selected Color Palette).  And if you wanted something like a spot meter then detecting hits in the image canvas and sending back commands to the server.

2. Add code to convert the lepton raw image to a jpeg image for streaming.  The lepton's raw data would have to be converted to a bitmap (and colorized using a palette) and then the bitmap converted to a jpeg image.  There are libraries that could be used to take the bitmap and create a jpeg image but my concern is that they are very compute and memory intensive [slow] and the ESP32 couldn't keep up with the Lepton's 8.8 FPS output.  The ESP-CAM is able to do this because the Omnivision camera modules can directly output jpeg images and all the ESP32 has to do is package them up for transmission by the web server.

I have plenty of code to create the bitmap and I understand how to include the Espressif web server.  I'm not experienced with creating the HTML/CSS/JS for the web page (and sadly little time to learn) and I don't know how to speed up the process of encoding jpeg images.  If those could be overcome I would consider a future firmware release with a web server.  It would be cool.

Another tCam-Mini user had the idea of writing a python RTSP server utilizing both the tCam-Mini python driver and available python libraries for creating the RTSP server.  I don't know how much work this might be and it would require another computer to run the server (like a Pi).

pierre-muth, 2022-08-06:
Thanks a lot for replying so rapidly !
Exactly, the jpeg has to be done on the ESP. I did that for the ESP-CAN with OV7725 (https://github.com/pierre-muth/OV7725_ESP32cam). This sensor is very sensitive, but only gives RGB565 data. It is clear 8fps is almost impossible. If I remember well I have something like 3-4 fps at 640x480. While the lepton is 160x120, as you say the color palette mapping and other transformations has to be done.
I'll continue to play/learn and update here.
Thanks for your help!
Pierre

danjulio, 2022-08-06:
Well thanks for sharing that!  Very interesting.  Maybe it is feasible.  Can the encoder take the 160x120 lepton image and increase it to a larger image (that most people would want to see)?  Maybe I'll also try to play with this a little.

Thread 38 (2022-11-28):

Questions about the wifi mode of tCam-Mini

GillesBra, 2022-11-28:
Hi Dan, I have purchased a tCam-mini Rev 4 with an external antenna in order to get the maximal range for a drone application in a student project. I use it with a Lepton 3.5. We have reached 120m but we wish to increase it as much as possible (500 m is the objective). So I have some questions about the design of the tCam-Mini:
1) What is the data rate in transmission with a Lepton 3.5 (theory gives me 2.8 Mbps )
a) in video mode
b) during image transmission
2) What is the wifi mode (802.11 b, g, n) used in these transmissions and what is the nominal RF power ?
Thank you for developping nice products.
Best regards
Gilles Brazzini

danjulio, 2022-11-30:
Hello Gilles,

Each image json packet is about 55 kBytes of data so for 8.7 FPS you're looking at about 3.8 Mbps at the data level (obviously raw data rate will be higher).

Unfortunately much of the Espressif WiFi stack is a mystery to me.  I generally configure it with default settings.  According to the IDF website (https://docs.espressif.com/projects/esp-idf/en/v4.4.2/esp32/api-guides/wifi.html) the stack can support up to 20 MBit/s TCP throughput on 802.11b, g and n networks (I suppose it can't support 20 MBit/s on 802.11b).  According to the ESP32 hardware datasheet the typical TX output power for n (and g?) is 13 dBm and for b is 19.5 dBm.  I guess when it acts as a station it selects a mode based on the AP's mode but I'm not sure what the default mode is when it acts as an AP.

Based on my general experience extending WiFi range the antenna is one of the most important components and you could certainly experiment there.  I don't know if it's a possibility but perhaps using a slightly directional ground antenna (that you'd have to keep aimed at the drone) would help quite a bit.  In addition making sure you're running on as clean of a channel as possible is always helpful.  By default I am using channel 1.

From a code perspective there might be two places to look if you're willing to build your own binaries:

1. You can modify my default configuration in the components/sys/wifi_utilities.c file.  Look at the IDF documentation at https://docs.espressif.com/projects/esp-idf/en/v4.4.2/esp32/api-reference/network/esp_wifi.html, in particular the configuration data structures.  You can force the WiFi type, data rate and max TX power.

2. You might be able to use the configurator (menuconfig) to modify the WiFi stack configuration (for example to force various routines and data structures into IRAM).  However IRAM is slightly tight since I'm already trying to put performance sensitive buffers in there instead of the slower PSRAM so it's possible the code either won't compile or your could experience out-of-memory crashes while it's running.

Possibly an even more extreme solution would be to use Espressif's Long Range (LR) mode which claims up to 1 km range.  But that would probably take more significant changes to the code and (I think) you'd also have to use a ESP32 as the base station (also in LR mode).  This is described in the first link I sent you.

Good luck!  I certainly understand the desire for more range.

GillesBra, 2022-12-08:
Thank you very much Dan for this information.
Modifying the code is probably difficult and risky for us. But we will investigate this way.
Extending the antenna range is certainly a good solution for a 5/56 db increase.
I was also thinking of adding a RF amplifier at the output of the ESP32. What do you think ?
Kind regards

danjulio, 2022-12-08:
Gilles, I can't speak authoritatively about adding a RF amplifier but I guess it could be theoretically possible.  It looks like the ESP32 can be configured to control external RF switches which is what you'd need since you have to have both a TX path and a RX path.    You would use a GPIO to switch the TX or RX paths to the ESP32 antenna connection (I guess you could repurpose the GPIO I use and bring out on the Rev 4 board for the Hardware Serial IF). See the following link:

[https://docs.espressif.com/projects/esp-idf/en/v4.4-beta1/esp32s2/api-guides/wifi.html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](https://docs.espressif.com/projects/esp-idf/en/v4.4-beta1/esp32s2/api-guides/wifi.html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)

Of course you'd have also have high TX power at the other end since WiFi requires bi-direction communication and there could be legality or regulatory compliance issues and the like to consider.

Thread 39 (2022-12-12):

Change default palette in the Lepton Module

kami83, 2022-12-12:
Hi Dan,

just a question not directly for your program.
Do you know how it is possible to change the defaul palette in the Lepton Module. Maybe with your Software and Hardware?

My problem is that if i use the module over USB in the Purethermal board for example VLC only display the Video in RAINBOWS Table and i want IRON.

How can i change the default.

Thanks a lot for some help.

BR Stefan

kami83, 2022-12-13:
HI, thanks a lot. I will do it like this.

BR Stefan

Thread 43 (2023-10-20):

shutter control through external pins?

leoshmu, 2023-10-20:
Hi,
I have one of your tcam rev4 boards and it works amazingly well, thank you so much for putting this together. I am interested in a set up where the shutter is a bit separated from the housing, and this end up disconnecting the 2 pins of the shutter from the copper traces on the housing. I can easily solder wires to the shutter pins, and I'm wondering if the signal that controls the shutter to close is accessible on any of the pins that you have made available on the board. I see from the spec sheet that I_DDIO is a 310 mA current that is responsible for closing the shutter, but I can't tell what the housing traces connect to.

Do any of the SLAVE IF pins on the board go high during FFC? Any advice you have about what signal on the board could be used to externally connect to the shutter (rather than rely on the two copper traces on the camera housing) would be much appreciated!

Best,
Leo

danjulio, 2023-10-20:
Hi Leo,

I'd love to see how you're integrating an external shutter!  I never considered doing that so unfortunately I don't bring out any trigger for it.  Although you can send a command to initiate a FFC, normally my code just lets the Lepton manage that itself.

The Lepton does provide indication that it is about to and then performing a FFC in the telemetry data and my code reads the telemetry along with each image (see section 3.2 in the Lepton Engineering Datasheet that you can download from Group Gets if you don't have it already).

You could parse the telemetry data, probably in lep_task, and look at bits 4 & 5 of the Status Word (offset 3 & 4 of the lep_telemP data structure in the lep_buffer which you can get using the lepton_utilities lepton_get_tel_status function).  This will tell you when a FFC is imminent and/or in process and I think you'd set an external GPIO (you could use one of the Hardware IF GPIOs if you never ground Mode) during those states.  Although I'm not 100% sure about the timing.

One possible thing to consider is that the lepton uses the shutter temperature in its calculations during the FFC.  So either you need to assume your shutter is the same temperature as the Lepton's built-in temperature sensor or you'll need to do a more complex change to the code.  Flir suggests that you run the the module in manual mode with an external shutter and you manually command the FFCs (when you want and also when the camera requests it via the telemetry).  I think you'll have to provide the shutter temperature via the CCI (maybe the SYS FFC Mode Control command but not 100% sure).  The good thing about taking over FFC control completely would be you could assure the correct timing of an external trigger GPIO based on the mechanical timing attributes of your shutter with the actual FFC measurements performed by the Lepton.

Sorry I don't have an easier solution for you but I hope this points you in a fruitful direction.

Also, just FYI, I moved all things related to the tCam devices to a new github repo which is the one I currently update (https://github.com/danjulio/tCam).

Cheers, Dan

leoshmu, 2023-10-25:
Hi Dan,

Thanks so much for the feedback. I ended up taking a risk that worked - I
soldered directly to the leads on the housing that connect to the shutter
pins, then I can connect those wires to the pins of the shutter mechanism
with some careful soldering as well, and now the shutter can be positioned
wherever I like!

Will followup separately regarding why I am doing this!

Best,
Leo

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

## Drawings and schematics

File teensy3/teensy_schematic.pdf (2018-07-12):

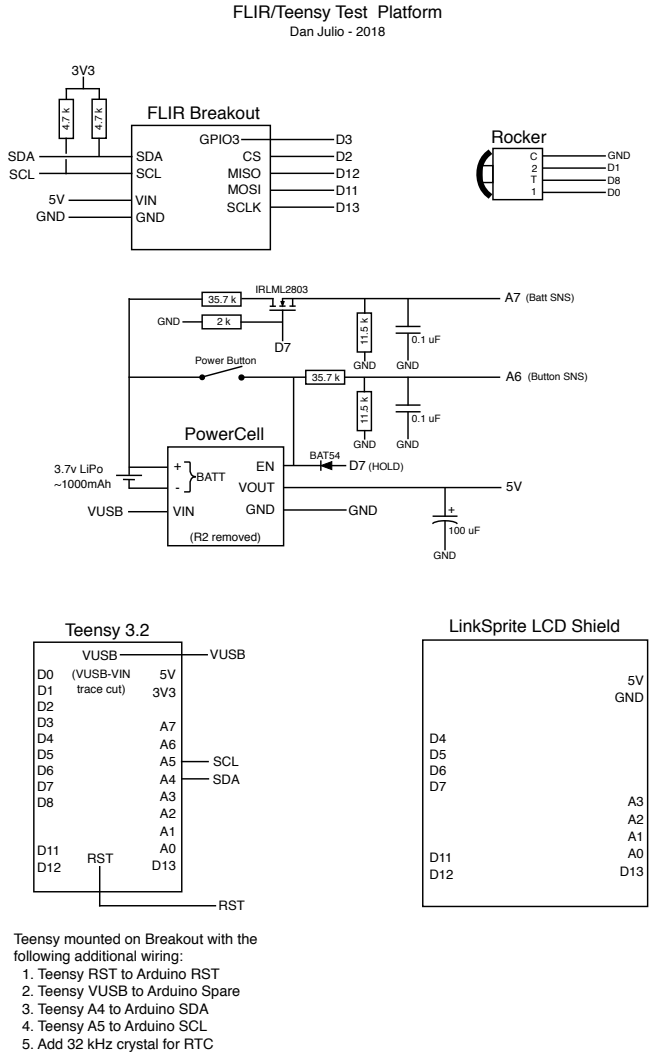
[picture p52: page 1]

FLIR/Teensy Test Platform

Teensy mounted on Breakout with the
following additional wiring:
1. Teensy RST to Arduino RST
2. Teensy VUSB to Arduino Spare
3. Teensy A4 to Arduino SDA
4. Teensy A5 to Arduino SCL
5. Add 32 kHz crystal for RTC

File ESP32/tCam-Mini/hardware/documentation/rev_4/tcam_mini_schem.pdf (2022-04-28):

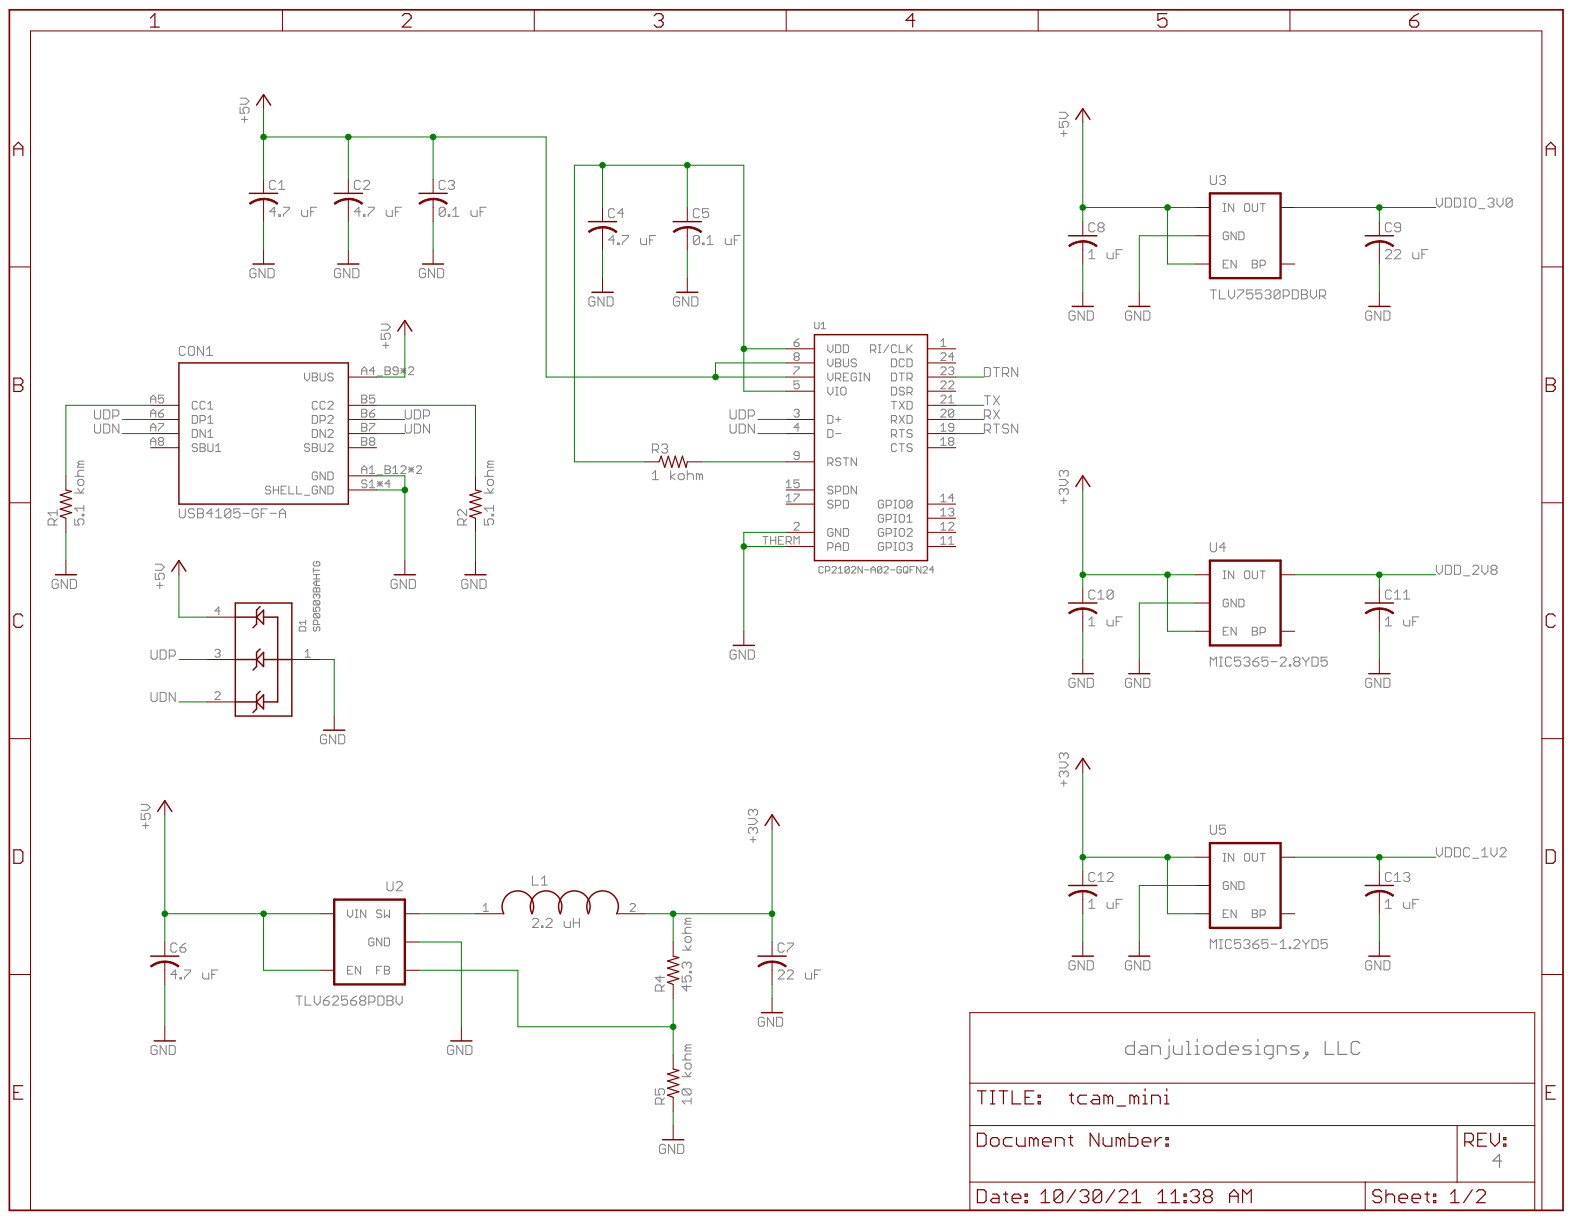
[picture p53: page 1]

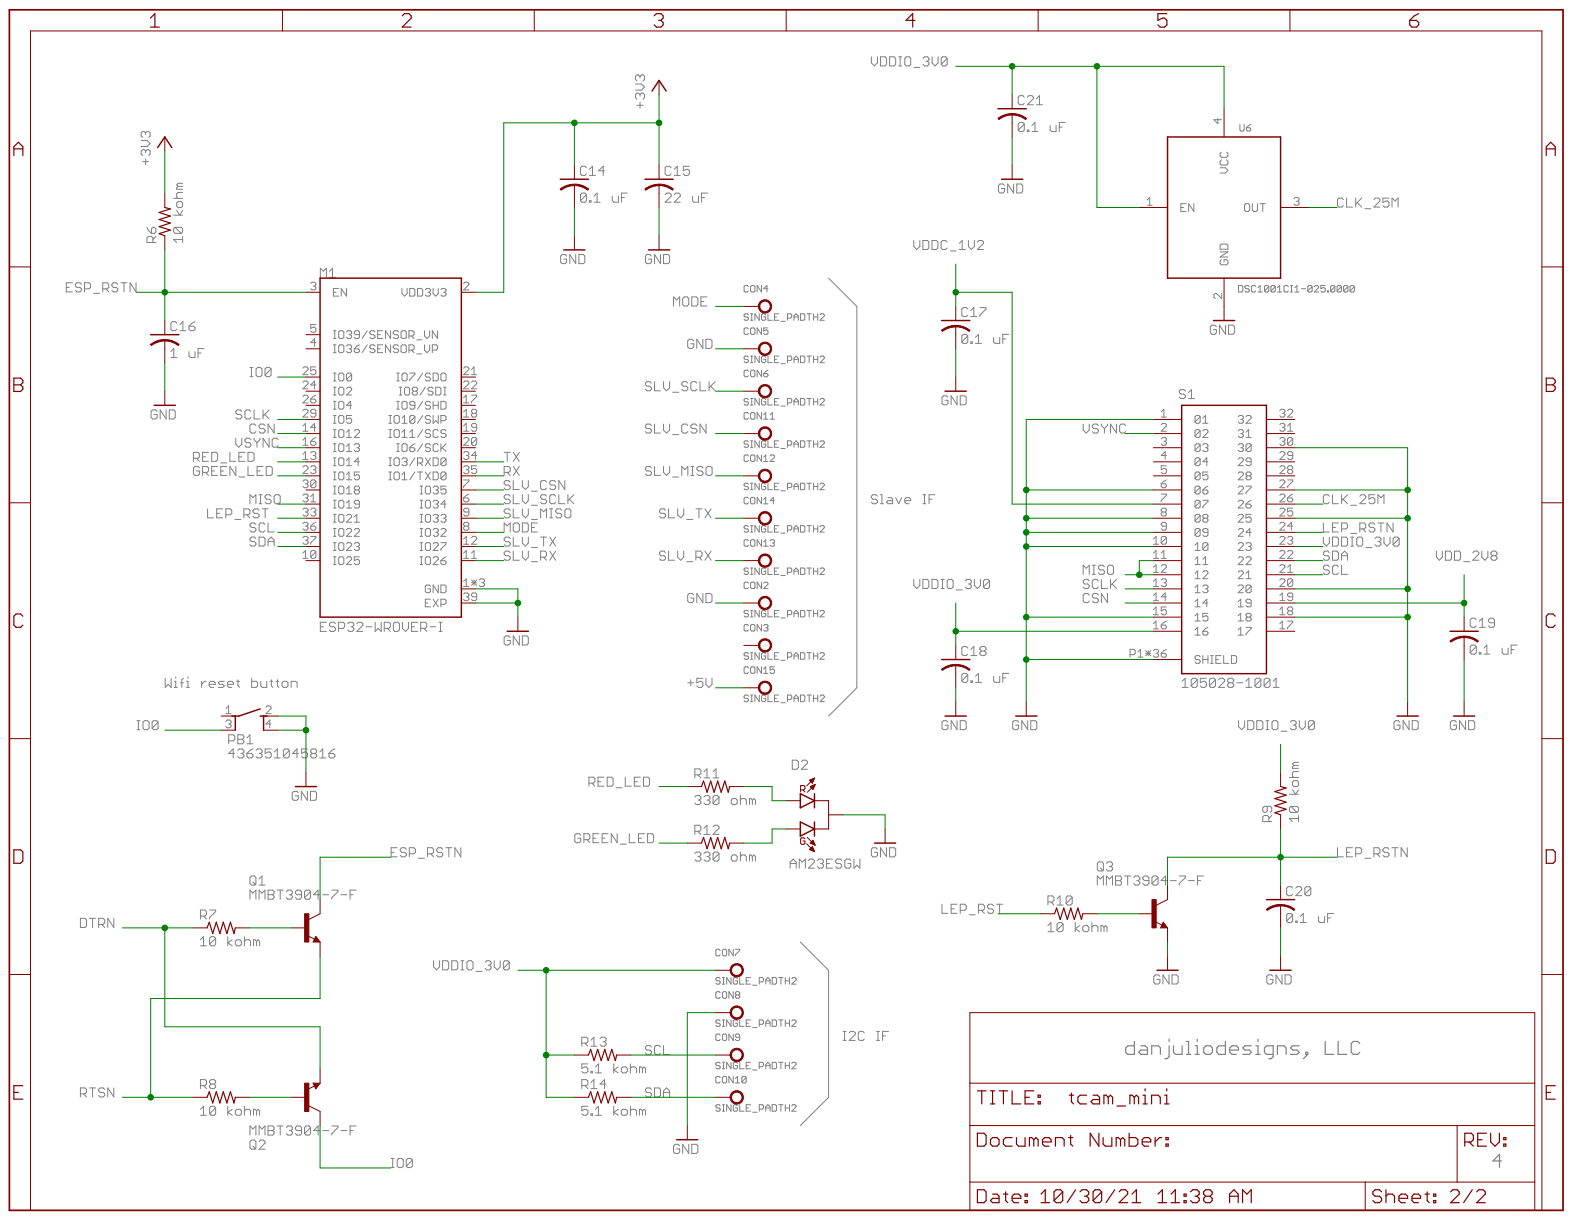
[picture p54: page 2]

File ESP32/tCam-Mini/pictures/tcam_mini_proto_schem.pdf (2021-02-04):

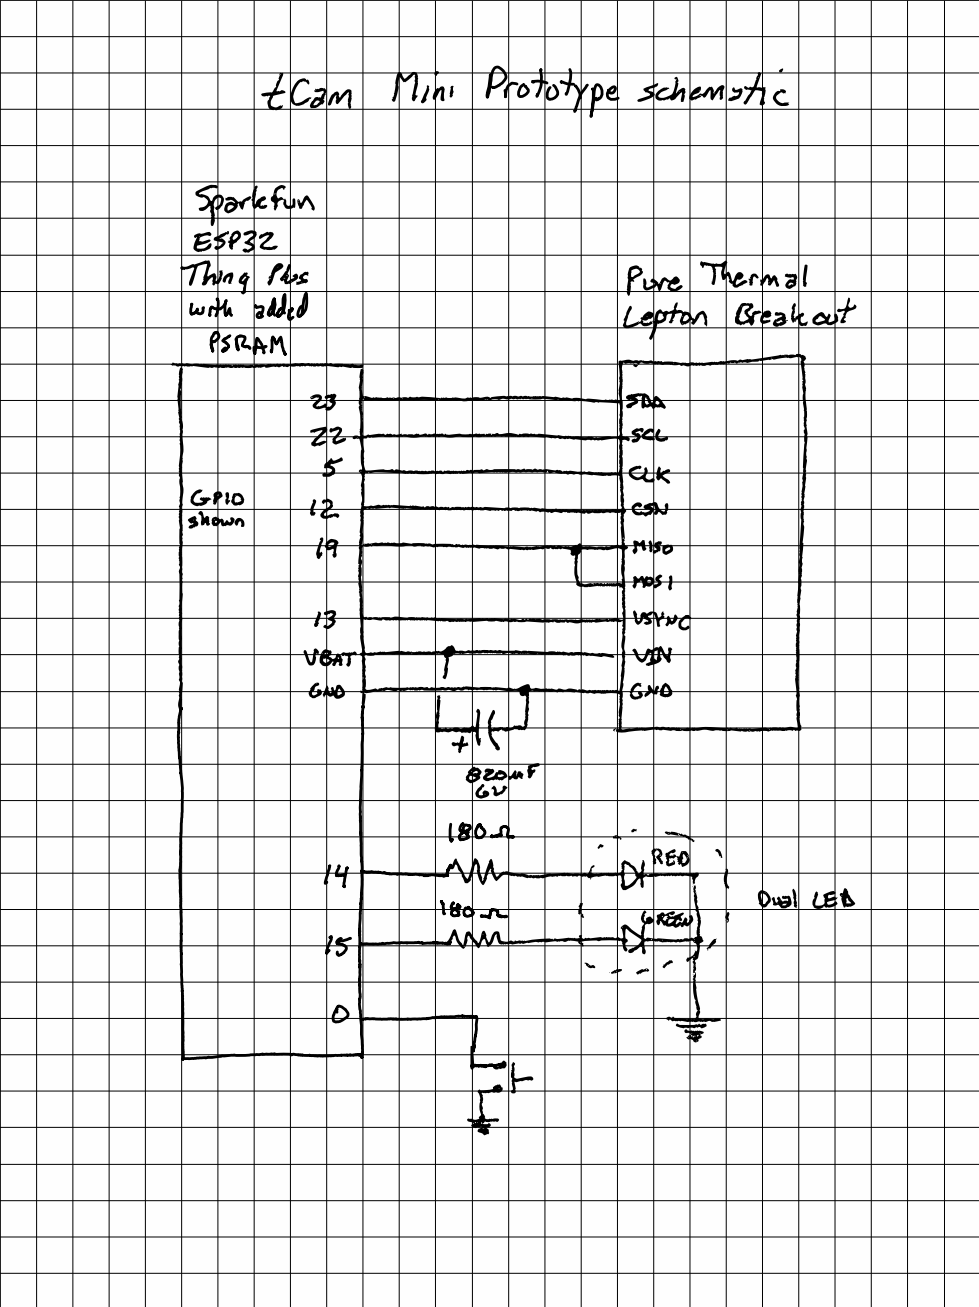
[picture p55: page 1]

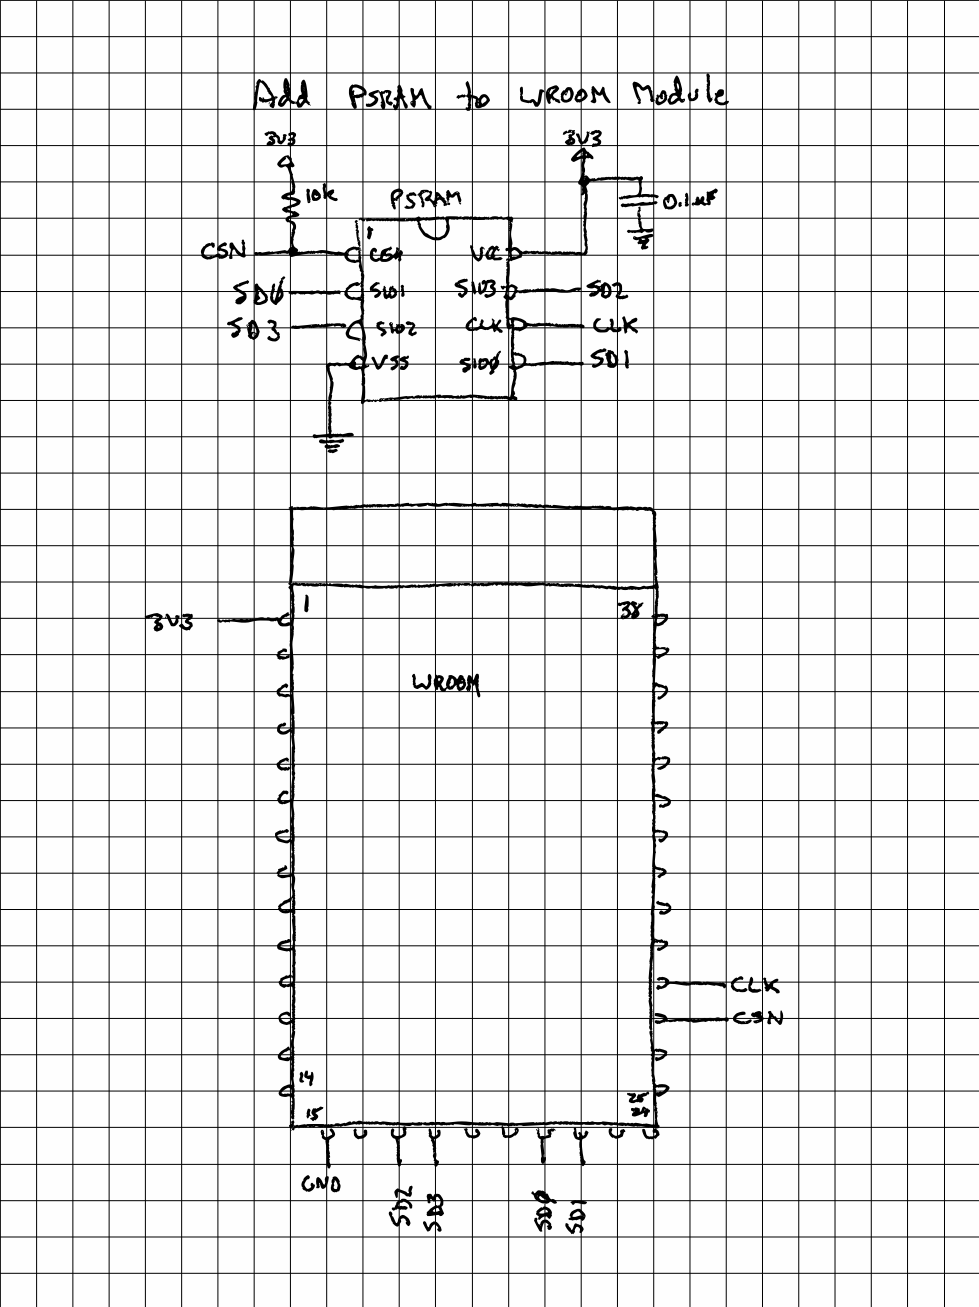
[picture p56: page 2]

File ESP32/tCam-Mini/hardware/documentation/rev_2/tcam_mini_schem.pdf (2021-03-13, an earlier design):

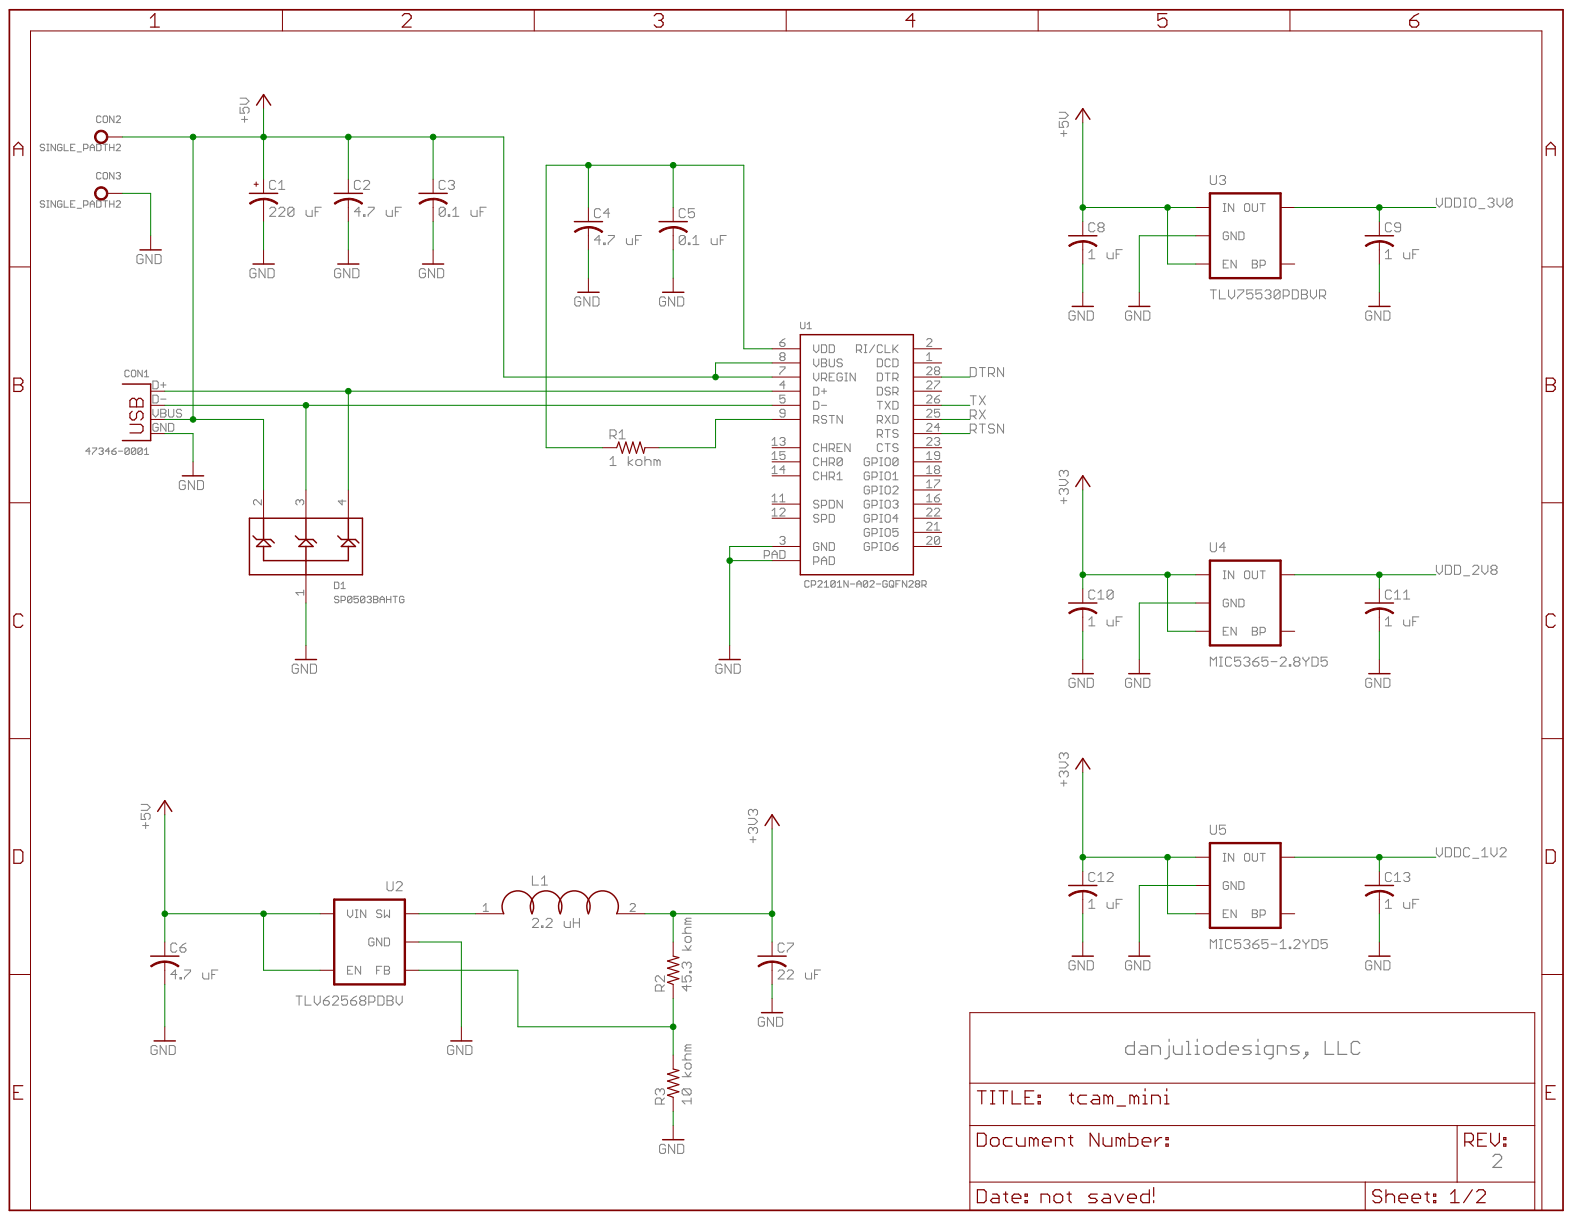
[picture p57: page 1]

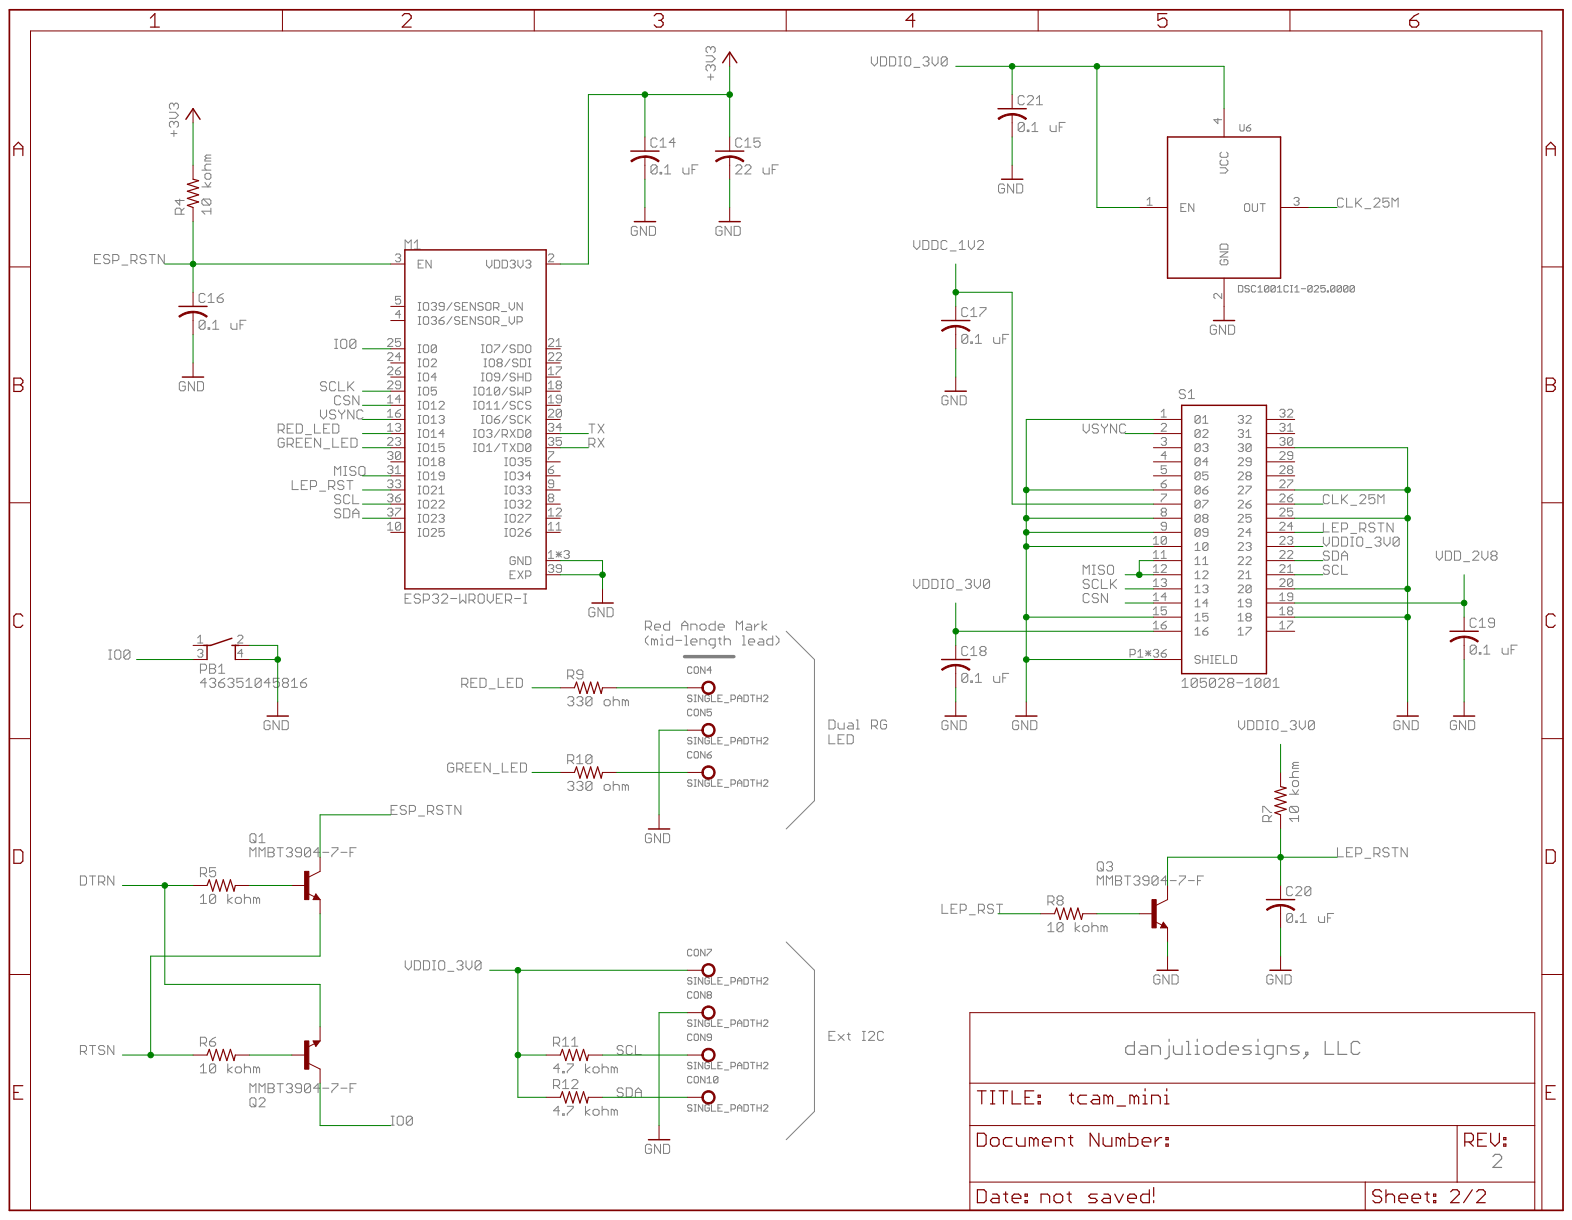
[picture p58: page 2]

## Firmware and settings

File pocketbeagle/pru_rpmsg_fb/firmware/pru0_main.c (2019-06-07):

/*
 * PRU Firmware for IR camera FLIR Lepton 3
 *
 * Implement the SPI portion of an interface for the Lepton camera.
 * This code assumes the Lepton AGC has been enabled (each 16-bit
 * data word contains 8-bits of data).  It reads packets from the camera
 * using a bit-banged MISO-only SPI interface running at 16.67 MHz.
 * It stores non-discard packets in a circular buffer located in shared
 * memory.  Only the low 8-bits of each Lepton data words are stored for
 * a total of 80 bytes per packet.  It assumes it is receiving a valid
 * frame when it sees packet 20 of segment 1 and notifies PRU1 that it can
 * start pushing packet data up to the host via RPMsg. 
 *
 * This PRU always starts loading at the beginning of the circular buffer.
 * Since the buffer is smaller than a complete frame it only starts pushing
 * data for a new frame after it sees that PRU1 has finished consuming
 * the current frame.  This means PRU1 must send data before a valid new
 * frame starts (every third frame).
 *
 * Also since the circular buffer is smaller than a complete frame it ends
 * up overwriting the start of the buffer with the end of the frame while
 * PRU1 is reading the buffer.  It's important to make sure the timing
 *
 * One frame requires 80 x 240 = 19200 bytes.  Almost the entire 12K shared
 * memory buffer is available for the circular buffer.
 *
 * This PRU reads one packet every 128 uSec (less than the maximum 158 uSec
 * period that is required to keep up with the Lepton).  The other PRU must
 * read data out fast enough yet slowly enough not to overrun this PRU. Since
 * the timing is fixed we can find this balance without requiring the two
 * PRUs to communicate other than valid (or cancelled buffer).
 *
 * This PRU also maintains a counter to validate each packet (the counter
 * value is the (segment-1) * packet number).  If it sees a non-discard 
 * packet with an unexpected count it resets.  If it has previously triggered
 * PRU1 to start reading out packets then it sends an abort notification to PRU1.
 *
 * PRU1 sets an enable locatation in shared memory buffer to 1 to indicate when
 * to run.  Otherwise this PRU spins waiting to be enabled.
 *
 * The LED attached to P1.36 is lit while receiving a valid frame (from segment 1,
 * packet 20 to segment 4, packet 59).
 *
 * Copyright (C) 2018 Dan Julio <dan@danjuliodesigns.com>
 *
 * This program is free software; you can redistribute it and/or modify it
 * under the terms of the GNU General Public License as published by the
 * Free Software Foundation; either version 2 of the License, or (at your
 * option) any later version.
 */
/* We are compiling for PRU0 */
#define PRU0

#include <stdint.h>
#include <pru_cfg.h>
#include <pru_ctrl.h>
#include "pru_common.h"
#include "resource_table_0.h"


/* ========= */
/* Constants */
/* ========= */

/* ----------- */
/* Sample Time */
/* ----------- */
#define PKT_SAMPLE_USEC  128
#define PRU_CLK_PER_USEC 200
#define PRU_SAMPLE_TO    (PKT_SAMPLE_USEC * PRU_CLK_PER_USEC)

/* Number of packet sample intervals to detect need to resync Lepton  */
/*   Time is greater than 1/9 second plus 10 mSec per spec 4.2.3.3.1  */
#define RESYNC_THRESHOLD_USEC 200000
#define RESYNC_THRESHOLD_COUNT (RESYNC_THRESHOLD_USEC / PKT_SAMPLE_USEC)

/* PRU Cycles to reset Lepton -> 185 mSec */
#define LEP_RESYNC_USEC 190000
#define LEP_RESYNC_CYCLES (LEP_RESYNC_USEC * PRU_CLK_PER_USEC)


/* -------------- */
/* PRU IO related */
/* -------------- */
#define CLK     14      //P2_24
#define MISO    5       //P2_34
#define CSN     2       //P2_32
#define LED     0       //P1_36

#define SET_PIN(bit,high)	if(high) __R30 |= (1 << (bit)); else __R30 &= ~(1 << (bit));
#define INVERT_PIN(bit)		__R30 ^= (1 << (bit));
#define CHECK_PIN(bit)		__R31 & (1 << (bit))


/* ------------------ */
/* Lepton 3.5 related */
/* ------------------ */
#define LEP_PACKET_SIZE      164 // Bytes
#define LEP_PACKET_DATA_SIZE 160 // Bytes


/* --------- */
/* Run state */
/* --------- */
#define RUN_STATE_STOPPED 0
#define RUN_STATE_DATA    1
#define RUN_STATE_DISCARD 2


/* ---------------------- */
/* Received Packet Status */
/*    from get_packet     */
/* ---------------------- */
#define PKT_DISCARD  0
#define PKT_GOOD     1
#define PKT_TRIGGER  2
#define PKT_ILLEGAL  3


/* ================ */
/* Global Variables */
/* ================ */
volatile register unsigned __R31;
volatile register unsigned __R30;

/* Shared memory buffer */
volatile uint8_t* buf_en_reg_ptr = SMEM_EN_REG;
volatile uint8_t* buf_pru1_cmd_ptr =  SMEM_CMD_REG;
volatile uint8_t* buf_cur_ptr = SMEM_BUF_START;

uint8_t run_state = RUN_STATE_STOPPED;
uint8_t cur_segment = 0; /* 0 while waiting, 1 - 4 while receiving */
uint8_t cur_packet = 59; /* 0 - 59 */
uint8_t cur_count = 0;   /* 0 - 239 */
uint16_t lep_resync_count = 0; /* Counts sample intervals, reset each trigger */
uint32_t lep_discard_pkt_count = 0;  /* Counts consecutive Lepton discard packets in a row */
                                     /* for diag purposes to read out with prudebug */


/* =========== */
/* Subroutines */
/* =========== */
void init_pru()
{
	/* Enable OCP Master Port */
	CT_CFG.SYSCFG_bit.STANDBY_INIT = 0;

	/* Make sure we always start up disabled - clear any enable left laying around */
	*buf_en_reg_ptr = P0_DISABLE;

	/* Set CSN de-asserted and SCK high */
	SET_PIN(CSN,1);
	SET_PIN(CLK,1);

	/* Slow blink the LED to let them know we've started */
	SET_PIN(LED,1);
	__delay_cycles(100000000);
	SET_PIN(LED,0);
}


void init_capture()
{
	buf_cur_ptr = SMEM_BUF_START;
	cur_segment = 0;   /* setup to receive segment 1 in packet 20 as first valid segment */
	cur_packet = 59;   /* setup to receive packet 0 as first valid packet */
	cur_count = 0;
}


void disable_timer()
{
	PRU0_CTRL.CTRL_bit.CTR_EN = 0;
}


void init_timer()
{
	PRU0_CTRL.CTRL_bit.CTR_EN = 0;  /* Disable timer */
	PRU0_CTRL.CYCLE = 0;            /* Reset timer */
	PRU0_CTRL.CTRL_bit.CTR_EN = 1;  /* Enable timer */
}


/* Returns 1 if the timer has expired - and resets timer */
int timer_expired()
{
	if (PRU0_CTRL.CYCLE >= PRU_SAMPLE_TO) {
		init_timer();
		return 1;
	}
	return 0;
}


/*
 * Read 8-bit word from SPI pins, SPI mode 3 - CPOL=1, CPHA=1, CSN low on entry
 *   Tuned to 12-13 clocks -> 60-65 nS -> 16.67-15.38 MHz (there is 1-clock variability
 *   writing to the miso variable depending on other activity in the PRU memory subystem)
 */
uint8_t spi_read8() 
{
	uint8_t i;
	uint8_t miso;

	miso = 0x0;
	
	for (i = 0; i < 8; i++) {
		miso <<= 1;
		SET_PIN(CLK,0);
		__delay_cycles(4);
		
		SET_PIN(CLK,1);
		if (CHECK_PIN(MISO))
			miso |= 0x01;
		else
			miso &= ~0x01;
	}
	return miso;
}


/*
 * Read one packet from the Lepton and store it in our buffer if it is valid
 */
uint8_t get_packet()
{
	uint8_t i;
	uint8_t pktNumHigh;
	uint8_t pktNumLow;

	/* Read one packet */
	pktNumHigh = spi_read8();  /* TTT bits and discard indication */
	pktNumLow = spi_read8();   /* Packet number */
	i = spi_read8();           /* Throw away CRC for now */
	i = spi_read8();           /* Throw away CRC for now */

	/* Look to see if we should discard this packet */
	if (((pktNumHigh & 0x0F) == 0x0F) || (run_state == RUN_STATE_DISCARD)) {
		/* Count discard packets */
		if ((pktNumHigh & 0x0F) == 0x0F) {
			++lep_discard_pkt_count;
		} else {
			lep_discard_pkt_count = 0;
		}

		/* Throw away this packet */
		for (i=0; i<LEP_PACKET_DATA_SIZE; i++) {
			(void) spi_read8();
		}
		return PKT_DISCARD;
	}

	/* Reset consecutive discard count */
	lep_discard_pkt_count = 0;

	/* Store packet - low 8-bits of each word */
	for (i=0; i<LEP_PACKET_DATA_SIZE/2; i++) {
		(void) spi_read8();                /* Skip high half */
		*buf_cur_ptr++ = spi_read8();      /* Store low half - output of AGC module */
		if (buf_cur_ptr > SMEM_BUF_END) {
			buf_cur_ptr = SMEM_BUF_START;
		}
	}

	/* Update state */
	if (pktNumLow == 20) {
		/* Check and update our segment */
		i = (pktNumHigh & 0x70) >> 4;    /* TTT bits */

		if ((cur_segment + 1) == i) {
			/* Expected segment */
			cur_segment = i;

			if (cur_packet == 19) {
				/* Expected packet */
				cur_packet = 20;

				if (cur_segment == 1) {
					/* Looks like a good frame, trigger other PRU */
					return PKT_TRIGGER;
				}
			} else {
				/* Unexpected packet */
				return PKT_ILLEGAL;
			}
		} else {
			/* Unexpected segment number */
			return PKT_ILLEGAL;
		}
	} else if (cur_packet == 59) {
		if (pktNumLow == 0) {
			/* Expected packet for start of next segment */
			cur_packet = 0;
		} else {
			/* Unexpected packet */
			return PKT_ILLEGAL;
		}
	} else {
		if ((cur_packet + 1) == pktNumLow) {
			/* Expected next packet in this segment */
			cur_packet = pktNumLow;
		} else {
			/* Unexpected packet */
			return PKT_ILLEGAL;
		}
	}

	return PKT_GOOD;
}


/* ==== */
/* Main */
/* ==== */

void main()
{
	uint8_t pkt_response;

	init_pru();

	/* Loop Forever */
	while (1) {
		/* Check our enable register */
		if (*buf_en_reg_ptr == P0_ENABLE) {
			if (run_state == RUN_STATE_STOPPED) {
				/* Start up */
				run_state = RUN_STATE_DATA;
				init_capture();
				init_timer();
				lep_resync_count = 0;

				/* Assert CS */
				SET_PIN(CSN,0);
			}
		} else {
			if (run_state != RUN_STATE_STOPPED) {
				/* Shut down */
				run_state = RUN_STATE_STOPPED;
				disable_timer();
				SET_PIN(LED,0);

				/* De-assert CS */
				SET_PIN(CSN,1);
			}
		}

		/* Get data if enabled */
		if (run_state != RUN_STATE_STOPPED) {
			/* Check if PRU1 is done processing and we can start pushing data again */
			if (run_state == RUN_STATE_DISCARD) {
				if (*buf_pru1_cmd_ptr == P1_CMD_IDLE) {
					run_state = RUN_STATE_DATA;

					/* Initialize capture system for next frame */
					init_capture();
					lep_resync_count = 0;
				}
			}

			/* Check if time to read and process a packet */
			if (timer_expired()) {
				pkt_response = get_packet();
				lep_resync_count++;
				if (pkt_response == PKT_ILLEGAL) {
					/* Notify PRU1 if necessary */
					if (*buf_pru1_cmd_ptr == P1_CMD_IN_FRAME) {
						*buf_pru1_cmd_ptr = P1_CMD_ABORT;
						/* PRU1 will clear command when it reads it */
					}

					/* Try to restart */
					init_capture();
					SET_PIN(LED,0);
				} else if (pkt_response == PKT_TRIGGER) {
					/* Got Seg1/Pkt20 - Tell PRU1 to start processing */
					*buf_pru1_cmd_ptr = P1_CMD_IN_FRAME;

					/* Reset lepton resync counter because we expect this is a good frame */
					lep_resync_count = 0;

					/* Set LED */
					SET_PIN(LED,1);
				} else if (pkt_response == PKT_GOOD) {
					/* Look for last packet just pushed */
					if ((cur_packet == 59) && (cur_segment == 4)) {
						/* Discard packets until PRU1 is done */
						run_state = RUN_STATE_DISCARD;

						/* Clear LED */
						SET_PIN(LED,0);
					}
				}

				/* Look for need to resync Lepton */
				if (lep_resync_count == RESYNC_THRESHOLD_COUNT) {
					/* De-assert CS and LED */
					SET_PIN(CSN,1);
					SET_PIN(LED,0);

					/* Delay to allow Lepton to resync */
					__delay_cycles(LEP_RESYNC_CYCLES);

					/* Reinitialize capture system */
					init_capture();
					init_timer();
					lep_resync_count = 0;

					/* Re-assert CS */
					SET_PIN(CSN,0);
				}
			}

		}
	}
}

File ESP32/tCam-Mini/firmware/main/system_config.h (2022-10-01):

/*
 * System Configuration File
 *
 * Contains system definition and configurable items.
 *
 * Copyright 2020-2022 Dan Julio
 *
 * This file is part of tCam.
 *
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
 */
#ifndef SYSTEM_CONFIG_H
#define SYSTEM_CONFIG_H

#include "esp_system.h"



// ======================================================================================
// System debug
//

// Undefine to include the system monitoring task (included only for debugging/tuning)
//#define INCLUDE_SYS_MON



// ======================================================================================
// System hardware definitions
//

//
// IO Pins
//   Pin allocation is dependent on board type (Ethernet or WiFi/Serial)
//   due to some dedicated pins for ethernet.  Pins for non-existent functions
//   set to -1 since they will not be used.

// Board sense pin - pulled high with internal pull-up
//   0 - Ethernet board
//   1 - Wifi/Serial board
//
// Mode sense pin
//   Ethernet board (pulled high w/ external resistor) - 0: Ethernet, 1: Wifi
//   Wifi/Serial board (internal pull-up) - 0: Serial, 1: Wifi
//
#define BOARD_SENSE_IO          2

// Ethernet board pins
#define BRD_E_MODE_SENSE_IO     39

#define BRD_E_BTN_IO            36  /* requires external pull-up */
#define BRD_E_RED_LED_IO        14
#define BRD_E_GREEN_LED_IO      15

#define BRD_E_LEP_SCK_IO        12
#define BRD_E_LEP_CSN_IO        13
#define BRD_E_LEP_VSYNC_IO      35
#define BRD_E_LEP_MISO_IO       34
#define BRD_E_LEP_RESET_IO      4

#define BRD_E_I2C_MASTER_SDA_IO 32
#define BRD_E_I2C_MASTER_SCL_IO 33

#define BRD_E_SIF_RX_IO         -1
#define BRD_E_SIF_TX_IO         -1

#define BRD_E_HOST_SCK_IO       -1
#define BRD_E_HOST_MISO_IO      -1
#define BRD_E_HOST_CSN_IO       -1

#define BRD_E_ETH_MDC           23
#define BRD_E_ETH_MDIO          18
#define BRD_E_PHY_RESET         5

// Wifi/Serial board pins
#define BRD_W_MODE_SENSE_IO     32

#define BRD_W_BTN_IO            0
#define BRD_W_RED_LED_IO        14
#define BRD_W_GREEN_LED_IO      15

#define BRD_W_LEP_SCK_IO        5
#define BRD_W_LEP_CSN_IO        12
#define BRD_W_LEP_VSYNC_IO      13
#define BRD_W_LEP_MISO_IO       19
#define BRD_W_LEP_RESET_IO      21

#define BRD_W_I2C_MASTER_SDA_IO 23
#define BRD_W_I2C_MASTER_SCL_IO 22

#define BRD_W_SIF_RX_IO         26
#define BRD_W_SIF_TX_IO         27

#define BRD_W_HOST_SCK_IO       34
#define BRD_W_HOST_MISO_IO      33
#define BRD_W_HOST_CSN_IO       35

#define BRD_W_ETH_MDC           -1
#define BRD_W_ETH_MDIO          -1
#define BRD_W_PHY_RESET         -1



//
// Hardware Configuration
//

// I2C
#define I2C_MASTER_NUM     1
#define I2C_MASTER_FREQ_HZ 100000

// SPI
//   Lepton uses HSPI (no MOSI)
//   Host SPI Slave uses VSPI (no MOSI)
#define LEP_SPI_HOST    HSPI_HOST
#define LEP_DMA_NUM     2
#define LEP_SPI_FREQ_HZ 16000000

#define HOST_SPI_HOST   VSPI_HOST
#define HOST_DMA_NUM    1
#define HOST_SPI_MODE   0

// Ethernet PHY
#define ETH_PHY_ADDRESS 1

// Uncomment one selection for the specific PHY chip
#define ETH_PHY_IP101
//#define ETH_PHY_RTL8201
//#define ETH_PHY_LAN8720
//#define ETH_PHY_DP83848



// ======================================================================================
// System configuration
//

// Camera model number
//  1. tCam Mini using the WiFi board is model 2
//  2. tCam Mini using the Ethernet board is model 3
#define CAMERA_MODEL_NUM_WIFI 2
#define CAMERA_MODEL_NUM_ETH  3

// tCam capabilities mask 
//   Bit  7: 0: Camera model number
//   Bit  9: 8: Lepton Type
//        0  0 - Lepton 3.5
//        0  1 - Lepton 3.0
//        1  0 - Lepton 3.1
//        1  1 - Reserved
//   Bit 13:12: Interface Type
//        0  0 - WiFi
//        0  1 - Serial/SPI interface
//        1  0 - Ethernet
//        1  1 - Reserved
//   Bit    16: Has Battery (not set)
//   Bit    17: Has Filesystem (not set)
//   Bit    18: Has OTA Firmware Updates (set)
#define CAMERA_CAP_MASK_CORE    0x00040000
#define CAMERA_CAP_MASK_IF_WIFI 0x00000000
#define CAMERA_CAP_MASK_IF_SIF  0x00001000
#define CAMERA_CAP_MASK_IF_ETH  0x00002000
#define CAMERA_CAP_MASK_LEP3_5  0x00000000
#define CAMERA_CAP_MASK_LEP3_0  0x00000100
#define CAMERA_CAP_MASK_LEP3_1  0x00000200
#define CAMERA_CAP_MASK_LEP_UNK 0x00000300
#define CAMERA_CAP_MASK_LEP_MSK 0x00000300


// Image (Lepton + Telemetry + Metadata) json object text size
// Based on the following items:
//   1. Base64 encoded Lepton image size: (160x120x2)*4 / 3
//   2. Base64 encoded Lepton telemetry size: (80x3x2)*4 / 3
//   3. Metadata text size: 1024
//   4. Json object overhead (child names, formatting characters, NLs): 128
// Manually calculate this and round to 4-byte boundary
#define JSON_MAX_IMAGE_TEXT_LEN (1024 * 53)

// Maximum firmware update chunk request size
#define FM_UPD_CHUNK_MAX_LEN    (1024 * 8)

// Maximum command response json object text size
#define JSON_MAX_RSP_TEXT_LEN   2048
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

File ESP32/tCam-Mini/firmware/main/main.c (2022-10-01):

/*
 * tCam-Mini Main
 *
 *
 * Copyright 2020-2022 Dan Julio
 *
 * This file is part of tCam.
 *
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
 * You should have received a copy of the GNU General Public License
 * along with tCam.  If not, see <https://www.gnu.org/licenses/>.
 */
#include <stdio.h>
#include <stdbool.h>
#include "freertos/FreeRTOS.h"
#include "freertos/task.h"
#include "esp_log.h"
#include "net_cmd_task.h"
#include "sif_cmd_task.h"
#include "ctrl_task.h"
#include "lep_task.h"
#include "mon_task.h"
#include "rsp_task.h"
#include "system_config.h"
#include "sys_utilities.h"



static const char* TAG = "main";

void app_main(void)
{
	int brd_type;
	int if_mode;
	
    ESP_LOGI(TAG, "tCamMini starting");
    
    // Start the control task to light the red light immediately
    // and to determine what kind of interface we will be using
    xTaskCreatePinnedToCore(&ctrl_task, "ctrl_task", 2176, NULL, 1, &task_handle_ctrl, 0);
    
    // Allow task to start and determine operating mode
    vTaskDelay(pdMS_TO_TICKS(50));
    ctrl_get_if_mode(&brd_type, &if_mode);
    
    // Initialize the SPI and I2C drivers
    if (!system_esp_io_init(brd_type, if_mode)) {
    	ESP_LOGE(TAG, "ESP32 init failed");
    	ctrl_set_fault_type(CTRL_FAULT_ESP32_INIT);
    	while (1) {vTaskDelay(pdMS_TO_TICKS(100));}
    }
    
    // Initialize the camera's peripheral devices
    if (!system_peripheral_init(brd_type, if_mode)) {
    	ESP_LOGE(TAG, "Peripheral init failed");
    	ctrl_set_fault_type(CTRL_FAULT_PERIPH_INIT);
    	while (1) {vTaskDelay(pdMS_TO_TICKS(100));}
    }
    
    // Pre-allocate big buffers
    if (!system_buffer_init()) {
    	ESP_LOGE(TAG, "Memory allocate failed");
    	ctrl_set_fault_type(CTRL_FAULT_MEM_INIT);
    	while (1) {vTaskDelay(pdMS_TO_TICKS(100));}
    }
    
    // Delay for Lepton internal initialization on power-on (max 950 mSec)
    vTaskDelay(pdMS_TO_TICKS(900));
    
    // Notify control task that we've successfully started up
    xTaskNotify(task_handle_ctrl, CTRL_NOTIFY_STARTUP_DONE, eSetBits);
    
    // Start tasks
    //  Core 0 : PRO - everything but lepton task
    //  Core 1 : APP - lepton task
    if (if_mode == CTRL_IF_MODE_SIF) {
    	xTaskCreatePinnedToCore(&sif_cmd_task, "sif_cmd_task",  3072, NULL, 1, &task_handle_cmd,  0);
    	xTaskCreatePinnedToCore(&rsp_task, "rsp_task",  2816, NULL, 19, &task_handle_rsp,  0);
    	xTaskCreatePinnedToCore(&lep_task, "lep_task",  2048, NULL, 18, &task_handle_lep,  1);
    } else {
    	xTaskCreatePinnedToCore(&net_cmd_task, "net_cmd_task",  3072, NULL, 1, &task_handle_cmd,  0);
    	xTaskCreatePinnedToCore(&rsp_task, "rsp_task",  2816, NULL, 19, &task_handle_rsp,  0);
    	xTaskCreatePinnedToCore(&lep_task, "lep_task",  2048, NULL, 19, &task_handle_lep,  1);
    }

#ifdef INCLUDE_SYS_MON
	xTaskCreatePinnedToCore(&mon_task, "mon_task",  2048, NULL, 1, &task_handle_mon,  0);
#endif
}

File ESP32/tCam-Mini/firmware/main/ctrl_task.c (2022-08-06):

/*
 * Control Interface Task
 *
 * Determine communication mode (Ethernet/WiFi or Serial)
 *
 * Manage user controls:
 *   Ethernet/WiFi Reset Button
 *   Red/Green Dual Status LED
 *
 * Copyright 2020-2022 Dan Julio
 *
 * This file is part of tCam.
 *
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
 */
#include <stdbool.h>
#include "ctrl_task.h"
#include "net_cmd_task.h"
#include "rsp_task.h"
#include "esp_system.h"
#include "esp_log.h"
#include "driver/gpio.h"
#include "freertos/FreeRTOS.h"
#include "freertos/task.h"
#include "net_utilities.h"
#include "ps_utilities.h"
#include "system_config.h"
#include "sys_utilities.h"



//
// Control Task Constants
//

// LED Colors
#define CTRL_LED_OFF 0
#define CTRL_LED_RED 1
#define CTRL_LED_YEL 2
#define CTRL_LED_GRN 3

// LED State Machine states
#define CTRL_LED_ST_SOLID      0
#define CTRL_LED_ST_BLINK_ON   1
#define CTRL_LED_ST_BLINK_OFF  2
#define CTRL_LED_ST_RST_ON     3
#define CTRL_LED_ST_RST_OFF    4
#define CTRL_LED_ST_FLT_ON     5
#define CTRL_LED_ST_FLT_OFF    6
#define CTRL_LED_ST_FLT_IDLE   7
#define CTRL_LED_ST_FW_REQ_R   8
#define CTRL_LED_ST_FW_REQ_G   9
#define CTRL_LED_ST_FW_UPD_ON  10
#define CTRL_LED_ST_FW_UPD_OFF 11

// Control State Machine states
#define CTRL_ST_STARTUP            0
#define CTRL_ST_NET_NOT_CONNECTED  1
#define CTRL_ST_NET_CONNECTED      2
#define CTRL_ST_CLIENT_CONNECTED   3
#define CTRL_ST_RESET_ALERT        4
#define CTRL_ST_RESET_ACTION       5
#define CTRL_ST_FAULT              6
#define CTRL_ST_FW_UPD_REQUEST     7
#define CTRL_ST_FW_UPD_PROCESS     8


//
// Control Task variables
//
static const char* TAG = "ctrl_task";

// Board/IO related
static int ctrl_brd_type;
static int ctrl_if_mode;
static int ctrl_pin_btn;
static int ctrl_pin_r_led;
static int ctrl_pin_g_led;

// State
static int ctrl_state;
static int ctrl_pre_activity_state;
static int ctrl_led_state;
static int ctrl_action_timer;
static int ctrl_led_timer;
static int ctrl_fault_led_count;
static int ctrl_fault_type = CTRL_FAULT_NONE;



//
// Forward Declarations for internal functions
//
static void ctrl_task_init();
static void ctrl_debounce_button(bool* short_p, bool* long_p);
static void ctrl_set_led(int color);
static void ctrl_eval_sm();
static void ctrl_set_state(int new_st);
static void ctrl_eval_led_sm();
static void ctrl_set_led_state(int new_st);
static void ctrl_handle_notifications();



//
// API
//
void ctrl_task()
{
	ESP_LOGI(TAG, "Start task");
	
	ctrl_task_init();
	
	while (1) {
		vTaskDelay(pdMS_TO_TICKS(CTRL_EVAL_MSEC));
		ctrl_handle_notifications();
		ctrl_eval_led_sm();
		ctrl_eval_sm();
	}
}

void ctrl_get_if_mode(int* brd, int* iface)
{
	*brd = ctrl_brd_type;
	*iface = ctrl_if_mode;
}


// Not protected by semaphore since it won't be accessed until after subsequent notification
void ctrl_set_fault_type(int f)
{
	ctrl_fault_type = f;
	
	if (f == CTRL_FAULT_NONE) {
		// Asynchronously notify this task to return to the previous state
		xTaskNotify(task_handle_ctrl, CTRL_NOTIFY_FAULT_CLEAR, eSetBits);
	} else {
		// Save the existing state to return to when the fault is cleared
		if (ctrl_state != CTRL_ST_FW_UPD_PROCESS) {
			ctrl_pre_activity_state = ctrl_state;
		}
		
		// Asynchronously notify this task
		xTaskNotify(task_handle_ctrl, CTRL_NOTIFY_FAULT, eSetBits);
	}
}



//
// Internal functions
//
static void ctrl_task_init()
{
	// First determine the board type
	gpio_reset_pin(BOARD_SENSE_IO);
	gpio_set_direction(BOARD_SENSE_IO, GPIO_MODE_INPUT);
	gpio_set_pull_mode(BOARD_SENSE_IO, GPIO_PULLUP_ONLY);
	if (gpio_get_level(BOARD_SENSE_IO) == 0) {
		// We're the Ethernet board - determine the operating mode
		ctrl_brd_type = CTRL_BRD_ETH_TYPE;
		gpio_reset_pin(BRD_E_MODE_SENSE_IO);
		gpio_set_direction(BRD_E_MODE_SENSE_IO, GPIO_MODE_INPUT);
		gpio_set_pull_mode(BRD_E_MODE_SENSE_IO, GPIO_PULLUP_ONLY);
		if (gpio_get_level(BRD_E_MODE_SENSE_IO) == 0) {
			ctrl_if_mode = CTRL_IF_MODE_ETH;
			ESP_LOGI(TAG, "Ethernet board type detected - using Ethernet");
		} else {
			ctrl_if_mode = CTRL_IF_MODE_WIFI;
			ESP_LOGI(TAG, "Ethernet board type detected - using WiFi");
		}
		
		ctrl_pin_btn = BRD_E_BTN_IO;
		ctrl_pin_r_led = BRD_E_RED_LED_IO;
		ctrl_pin_g_led = BRD_E_GREEN_LED_IO;
	} else {
		// We're the WiFi/Serial board - determine the operating mode
		ctrl_brd_type = CTRL_BRD_WIFI_TYPE;
		gpio_reset_pin(BRD_W_MODE_SENSE_IO);
		gpio_set_direction(BRD_W_MODE_SENSE_IO, GPIO_MODE_INPUT);
		gpio_set_pull_mode(BRD_W_MODE_SENSE_IO, GPIO_PULLUP_ONLY);
		if (gpio_get_level(BRD_W_MODE_SENSE_IO) == 0) {
			ctrl_if_mode = CTRL_IF_MODE_SIF;
			ESP_LOGI(TAG, "WiFi board type detected - using Serial");
		} else {
			ctrl_if_mode = CTRL_IF_MODE_WIFI;
			ESP_LOGI(TAG, "WiFi board type detected - using WiFi");
		}
		
		ctrl_pin_btn = BRD_W_BTN_IO;
		ctrl_pin_r_led = BRD_W_RED_LED_IO;
		ctrl_pin_g_led = BRD_W_GREEN_LED_IO;
	}
	
	// Setup the GPIO
	gpio_reset_pin((gpio_num_t) ctrl_pin_btn);
	gpio_set_direction((gpio_num_t) ctrl_pin_btn, GPIO_MODE_INPUT);
	gpio_pullup_en((gpio_num_t) ctrl_pin_btn);
	
	gpio_reset_pin((gpio_num_t) ctrl_pin_r_led);
	gpio_set_direction((gpio_num_t) ctrl_pin_r_led, GPIO_MODE_OUTPUT);
	gpio_set_drive_capability((gpio_num_t) ctrl_pin_r_led, GPIO_DRIVE_CAP_3);
	
	gpio_reset_pin((gpio_num_t) ctrl_pin_g_led);
	gpio_set_direction((gpio_num_t) ctrl_pin_g_led, GPIO_MODE_OUTPUT);
	gpio_set_drive_capability((gpio_num_t) ctrl_pin_g_led, GPIO_DRIVE_CAP_3);
	
	// Initialize state
	ctrl_set_state(CTRL_ST_STARTUP);
}


static void ctrl_debounce_button(bool* short_p, bool* long_p)
{
	// Button press state
	static bool prev_btn = false;
	static bool btn_down = false;
	static int btn_timer;
	
	// Dynamic variables
	bool cur_btn;
	bool btn_released = false;
	
	// Outputs will be set as necessary
	*short_p = false;
	*long_p = false;
	
	// Get current button value
	cur_btn = gpio_get_level(ctrl_pin_btn) == 0;
	
	// Evaluate button logic
	if (cur_btn && prev_btn && !btn_down) {
		// Button just pressed
		btn_down = true;
		btn_timer = CTRL_BTN_PRESS_MSEC / CTRL_EVAL_MSEC;
	}
	if (!cur_btn && !prev_btn && btn_down) {
		btn_down = false;
		btn_released = true;
	}
	prev_btn = cur_btn;
	
	// Evaluate timer for long press detection
	if (btn_down) {
		if (btn_timer != 0) {
			if (--btn_timer == 0) {
				// Long press detected
				*long_p = true;
			}
		}
	}
	
	if (btn_released && (btn_timer != 0)) {
		// Short press detected
		*short_p = true;
	}
}


static void ctrl_set_led(int color)
{
	switch (color) {
		case CTRL_LED_OFF:
			gpio_set_level((gpio_num_t) ctrl_pin_r_led, 0);
			gpio_set_level((gpio_num_t) ctrl_pin_g_led, 0);
			break;
		
		case CTRL_LED_RED:
			gpio_set_level((gpio_num_t) ctrl_pin_r_led, 1);
			gpio_set_level((gpio_num_t) ctrl_pin_g_led, 0);
			break;
		
		case CTRL_LED_YEL:
			gpio_set_level((gpio_num_t) ctrl_pin_r_led, 1);
			gpio_set_level((gpio_num_t) ctrl_pin_g_led, 1);
			break;
		
		case CTRL_LED_GRN:
			gpio_set_level((gpio_num_t) ctrl_pin_r_led, 0);
			gpio_set_level((gpio_num_t) ctrl_pin_g_led, 1);
			break;
	}
}
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

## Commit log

2018-07-18 lep_test8 bug fix for setting AGC mode
    Fixed a bug in the ConfigureAgcState where the switch statement cases did not have a break leading to the same AGC mode always being set.
2019-06-04 Fixed resync bug in pru0_main.c
    Fixed bug (discovered on port to pocketbeagle) where PRU0 might not attempt a resync if it were getting a series of illegal packets.
    [pru0_main.c]
2019-06-07 Add initial pocketbeagle content
    [base.scad, base.stl, button.scad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]
2019-07-26 Added touchscreen interrupt line
    Linux ADS7846 driver requires pendown interrupt.
2019-07-26 Added littlevgl_demo directory
    Added demo directory to capture device tree and littlevgl configuration files.
2021-02-04 Added ESP32
    Added the ESP32 directory including tCam-Mini and the tCam Desktop application.
    [tcam_mini.GBL, tcam_mini.GBO, tcam_mini.GBP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]
2021-02-04 Updated ESP32 top-level readme with pics
2021-02-07 Added precompiled binaries for ESP32 Rev 1 chips
2021-02-15 Fixed display of negative temperature values
    V1.0.1 fixes a formatting bug for image and histogram markers that prevented the display of the "-" character for negative numbers.
2021-03-01 Added board dimensions
2021-03-01 v1.1 firmware
    Fixed a bug where the camera, when wifi was configured as a client, would not try to reconnect with the AP if it failed the first time it tried.
2021-03-11 v1.2 firmware
    Moved lepton VSYNC/RST control to sys_utilities so the lepton can be reset on power-up for the case its oscillator is slow starting before the HW reset finishes. Also changed incorrect references in license comments in source files.
    [cci.c, cci.h, i2c.c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]
2021-03-13 Rev 2 PCB
    [tcam_mini.GBL, tcam_mini.GBO, tcam_mini.GBP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]
2021-03-29 Add enclosure
    [tcam_mini_cutout.dxf]
2021-04-14 Fixed count for an item
    [tcam_mini_rev02_bom.xlsx]
2021-04-21 Updated with support for Wire
2021-05-01 Desktop App Version 1.2
    Version 1.2 changes: support for tCam control and file management, support for Lepton CCI register access, new FFC button on main window and displayable log window.
2021-05-07 Update for tCam-Mini firmware v1.3
    Added API calls for run_ffc, get_lep_cci and set_lep_cci. With new cam_info response packet, all API calls now wait for a response. Added basic timeout checking for socket open.
2021-05-07 Added reference to python driver
2021-09-15 Fixed bug in set_lep_cci
    Was not encoding data as text
    [tcam.py]
2021-11-23 Version 2.0
    1. Faster performance
    2. Support for Lepton 3.0
    3. Support for OTA FW updates
    4. Support for a HW Slave interface
    5. Misc bug fixes
    [partitions.csv]
2021-11-23 Ignore ESP32/python/examples/__pycache__
2022-02-06 Added 3D printed enclosure by Zeke Gustafson
    [Enclosure Back.stl, Enclosure Front.stl, tCam-mini enclosure.f3d]
2022-02-06 tCam-mini version 2.1 firmware
    Prevent bricking if < 8 character password is set. Always allow wifi reset even if camera fails during boot.
    [ctrl_task.c]
2022-03-01 Added tcam_mini_basic enclosure
    [smooth_prim.scad, tcam_mini.scad, tcam_mini_basic_encl.scad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]
2022-03-15 Fixed typo with screw length
2022-04-20 Added ESP32 connections for breadboard build
2022-04-28 Updated with Rev 4 tCam-Mini
    [tcam_mini.GBL, tcam_mini.GBO, tcam_mini.GBP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]
2022-05-17 Adding some additional error handling, especially to handle the thread dying on a non-live IP address
    [tcam.py]
2022-06-19 Adding hardware interface logic for SPI/Serial version of tCam-mini
    This work does a major refactor of the manager thread, so that
    the outward interface remains largely the same, but you can use it
    with either the network version or the serial/spi version.
2022-06-26 Corrected mistakes and tightened
2022-07-17 Adding a check for the spidev.bufsize=65536 kernel cmdline argument that's required to have a buffer large enough to receive a frame from the lepton
2022-07-17 Adding a quick and dirty example of how to use the hardware interface version on a raspberry pi. It's called dump_hw_image.py
2022-11-06 Forked ESP32 stuff into a new repository

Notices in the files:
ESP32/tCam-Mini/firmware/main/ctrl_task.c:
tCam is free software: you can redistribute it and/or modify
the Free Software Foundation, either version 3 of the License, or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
